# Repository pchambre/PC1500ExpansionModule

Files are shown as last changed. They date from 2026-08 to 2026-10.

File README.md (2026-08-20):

# PC1500 Expansion Module (PSoC 5)

A PSoC 5-based hardware expansion board for the Sharp PC-1500/PC-2 pocket
computer, adding SD-card storage to PC-1500 BASIC via a set of new
`SD`-prefixed keywords (`SDLOAD`, `SDSAVE`, `SDLS`, `SDFMT`, ...).

The board plugs into the PC-1500's expansion port the same way a Sharp
CE-150/153/158 peripheral would, but unlike those (and unlike a real memory
module), the PSoC side has **no bus-request (BRQ) line** — it can't halt the
LH5801 CPU and take over the bus directly. Instead, the two sides
communicate through a shared 2KB RAM window mapped into the PC-1500's
address space: the CPU writes a command byte to a fixed "instruction"
address, the PSoC (polling that address in its own main loop) picks it up,
does the work, and writes its response into the same shared window. See
`PC_EXP.h` for the full wire protocol (command/status codes, buffer
layout).

## Companion emulator

[`pc1500emu`](https://github.com/pchambre/pc1500emu) is a from-scratch
PC-1500/LH5801 emulator with a matching `ExpansionMock` that implements this
same protocol against a real host directory — most of this board's firmware
and expansion-ROM development happens against the emulator (fast, no
hardware round-trip needed) and is only periodically verified against the
real PSoC board.

## Layout

This repo is a PSoC Creator workspace (`PC1500-PSOC5.cywrk`) containing
several `.cydsn` design variants, built up over the course of development.
**`Design01_NonDMA_8K_PV_Swap.cydsn` is the current, active design** — the
others (`Design01.cydsn`, `Design01_NonDMA.cydsn`,
`Design01_NonDMA_8KAddress_Space*.cydsn`, `Design01_NonDMA_8K_Swap2ndPage.cydsn`,
`Design02.cydsn`) are earlier iterations kept for reference, not maintained.

Inside the active design:

- `TopDesign/` — the PSoC 5 schematic (open with PSoC Creator to edit).
- `main.c` / `PC_EXP.h` — the PSoC-side firmware: the command processor
  (`DoCommand()`) that implements the shared-window wire protocol, backed
  by SEGGER emFile for the actual SD card filesystem calls.
- `rom/` — the PC-1500 expansion ROM, hand-written LH5801 assembly
  (`rom.asm`) that installs the new BASIC keywords. Assembled with
  [`sdaslh5801`](https://github.com/pchambre/sdcc-pc1500) via `build.ps1`,
  producing `rom_image.h` (baked into the PSoC firmware image so the module
  presents this ROM to the PC-1500 at boot) and a standalone `rom_8800.bin`
  (loadable directly into `pc1500emu` for fast iteration without a full
  PSoC Creator rebuild). See `rom/tests/` for a couple of small standalone
  test keywords used while reverse-engineering the PC-1500's own keyword
  dispatch mechanism.
- `SDCard/` — the emFile SD-card component wrapper.

Everything under `Generated_Source/`, `CortexM3/`, `codegentemp/`, and
`Export/` in each `.cydsn` folder is regenerated by PSoC Creator on build
and isn't tracked (see `.gitignore`) — open the workspace in PSoC Creator
and build to recreate it.

- `RP2350/` — an in-progress exploration of rearchitecting this board
  around the RP2350 (Pico 2 W) instead of PSoC 5 + ESP32-S3. Not yet the
  active design — see `RP2350/README.md` for the rationale and current
  state.

## Commands (implemented in `rom/rom.asm`)

- **`SDLS`** — browse the SD card's listing (current directory only, not
  recursive). Subdirectories are listed alongside files, with `<DIR>`
  (right-justified) in place of a size.
- **`SDFMT`** — format the SD card (`Y`/`N` confirmation).
- **`SDLOAD`** — load a BASIC program or binary data:
  - `SDLOAD` — browse, `L` selects and loads, `Enter` ignored, `CL`/`BREAK` abort.
  - `SDLOAD "<filename>"` — direct load, no browser.
  - `SDLOAD M` — browse, `L` loads the selected file as binary to its
    header's target address.
  - `SDLOAD M "<filename>"` — direct binary load to the file's header
    address; also `CALL`s an address embedded in the file, if present.
  - `SDLOAD M "<filename>",<address>` — direct binary load, relocated to
    `<address>` (decimal or `&`-prefixed hex); never calls the embedded
    address.
  - A missing file raises a genuine BASIC `ERROR 40`.
- **`SDSAVE`** — save a BASIC program or binary data:
  - `SDSAVE "<filename>"[,-Y]` — saves the current BASIC program.
  - `SDSAVE M "<filename>",<start>,<end>[,<call>][,-Y]` — saves the
    inclusive RAM range `[start,end]` as binary, with an optional embedded
    call address for a later `SDLOAD M` to invoke automatically.
  - Both forms prompt to confirm before overwriting an existing file
    (`-Y` skips the prompt); missing/malformed required arguments raise
    `ERROR 1`.

- **`SDCD "<path>"`** — change the current directory. Every other SD
  command that takes a name (`SDLOAD`, `SDSAVE`, `SDLS`, `SDRM`, `SDCP`,
  `SDMV`, ...) resolves a plain filename relative to wherever this last
  left it. `"."`/`".."` and multi-component relative paths work; a
  nonexistent directory silently aborts (no error code raised for this
  specific case yet).
- **`SDMKDIR "<path>"`** — create a directory.
- **`SDRMDIR "<path>"`** — remove an *empty* directory (matches emFile's
  own `FS_RmDir`, which fails outright on a non-empty one rather than
  deleting its contents).
- **`SDPWD`** — print the current directory (`/` at the SD root, before
  any `SDCD`).
- **`SDRM "<path>"[,-Y]`** — delete a single file (never a directory —
  `SDRMDIR` is the only sanctioned way to remove one). Confirms first
  (`DELETE FILE? Y/N`, explicit `Y` proceeds, anything else including
  `BREAK` aborts) unless `-Y` is given. A missing argument raises
  `ERROR 1`; the file not existing (or being a directory) raises
  `ERROR 40`.
- **`SDCP "<src>","<dest>"`** — copy a file. `SDMV "<src>","<dest>"`
  — move (rename) a file. If `<dest>` resolves to an *existing directory*,
  the file lands inside it under its own basename, matching Unix `cp`/
  `mv`'s own "copy/move INTO a directory" behavior; otherwise `<dest>` is
  the exact target name. An existing destination is confirmed first
  (`FILE EXISTS. OVERWRITE Y/N`) unless `-Y` is given, matching `SDSAVE`/
  `SDRM`'s own convention. A missing argument raises `ERROR 1`; the source
  not existing (or any other copy/move failure) raises `ERROR 40`.
- **`SDDF`** — print free/total SD space (`<free>F / <total>T`).

- **`SDOPEN`/`SDCLOSE`/`SDINPUT#`/`SDPRINT#`/`SDSKIP#`** — up to 16
  variable-oriented SD files open at once, numbered 1-16 (a simplified,
  Apple-BASIC-style analogue of the CE-150's own `PRINT#`/`INPUT#`, which
  operate directly on named variables rather than file handles or byte
  offsets):
  - `SDOPEN "<filename>" AS <n>` — opens (creating if necessary) a file on
    channel `<n>`. Reusing an already-open channel number closes its
    previous file first. Bare `SDOPEN` (no arguments) browses currently
    open channels and their numbers (`Enter`/`CL`/`BREAK` all exit).
  - `SDCLOSE <n>` — closes channel `<n>`. `SDCLOSE ALL` closes every open
    channel.
  - `SDPRINT#<n>,<var>[,<var>...]` — appends one value per listed variable
    to the end of channel `<n>`'s file, always at the end regardless of
    the channel's own read position.
  - `SDINPUT#<n>,<var>[,<var>...]` — reads one value per listed variable
    from channel `<n>`'s own persistent read position, advancing past
    each one read. If the channel runs out, every remaining requested
    variable is set to `0` (numeric) or blank (string) rather than
    raising an error.
  - `SDSKIP#<n>,<count>` — skips forward `<count>` values in channel
    `<n>`'s own read position without reading them. All-or-nothing: if
    the channel runs out partway through, the read position is left
    completely unchanged and a genuine `ERROR 40` is raised. The comma
    between `<n>` and `<count>` is required — BASIC's own line editor
    does not reliably preserve a bare space between two digit runs
    outside a quoted string, confirmed live (`SDSKIP#1 2` silently lands
    in the input buffer as `#12`).
  - Only simple (non-array) numeric and string variables are supported —
    no arrays, no general expressions, matching the real `PRINT#`/
    `INPUT#`'s own variable-list-only grammar. Values are stored as
    self-describing chunks (`rom.asm` resolves each variable's own real
    RAM address via the base ROM's `D461H` "variable address search"
    system subroutine and copies its storage bytes directly — `main.c`/
    the emulator's `ExpansionMock` never see a variable name or value,
    only opaque chunk bytes): a numeric chunk is the variable's own
    8-byte packed-decimal float, copied verbatim; a string chunk is a
    1-byte length plus that many raw ASCII bytes (a simple string
    variable always holds ≤16 characters). Reading back a value chunk
    whose type doesn't match the target variable, or a string chunk
    longer than the target's own real capacity (only possible from a
    corrupted or hand-crafted file — a genuine `SDPRINT#` can never
    overflow what any variable could legitimately hold), raises `ERROR
    42`.
  - A missing/malformed argument to any of these five raises `ERROR 1`;
    referencing a channel number that isn't currently open raises `ERROR
    40` (the wire protocol can't distinguish "not open" from a genuine
    I/O failure, so neither can the ROM — both get the same code every
    other SD-operation-failure case already uses).
  - True random-access/binary-offset access is not implemented yet —
    values are always read/written/skipped sequentially, one whole value
    at a time.

**Full path support**: every SD command's name argument (`SDLOAD`,
`SDSAVE`, `SDCD`, `SDMKDIR`, `SDRMDIR`, `SDRM`, and both `SDCP`/`SDMV`
arguments) accepts a plain filename, a relative path (`"SUB/FILE.BAS"`,
`"../FILE.BAS"`), or an absolute one from the SD root (`"/SUB/FILE.BAS"`,
or bare `"/"` for the root itself) — not just a bare filename in the
current directory. `/` is the one and only path separator — chosen
deliberately because it's an unshifted key on the PC-1500 keyboard, easy
to actually type. `main.c` converts to/from emFile's own native
`\`-separated, volume-prefixed paths at the boundary
(`PrepareFsName`/`ConvertSdPathToFsSeparators`), so nothing above that —
including the ROM side, which only ever sees/displays `/` — needs to know
emFile's own convention exists. A leading `/` with no volume prefix is
passed straight through to emFile, relying on its own path parser to
treat it as "from the SD root" (the same assumption `SDCD`'s own
`FS_ChDir` call already made — confirmed live for `SDCD` specifically,
not independently re-verified for every other command here).

`SDCD`/`SDMKDIR`/`SDRMDIR`/`SDRM`/`SDCP`/`SDMV` all require their
argument(s); missing one raises `ERROR 1`, matching `SDSAVE`'s own
convention.

**Uppercase 8.3 names**: this project's SD card uses SEGGER emFile's
No-Long-File-Name build (`emf32nosnlfn`, confirmed via this project's own
linker settings), so real on-disk names are genuine FAT 8.3 short names —
uppercase, `NAME.EXT` with an up-to-8-character name and an up-to-3-character
extension. Every SD command enforces this on its own argument(s):
lowercase letters are folded to uppercase automatically, and each
`/`-separated path segment that's too long, or has a second `.`, raises
`ERROR 1` (matching the existing unterminated/overlong-argument
convention) — except `SDLOAD`, which (per its own convention above)
silently aborts instead of raising an error for *any* malformed argument,
shape violations included. `.`/`..` segments are always exempt from the
shape check. A quoted argument itself is capped at 40 characters overall
— deliberately more than the 16-character width `SDLS`'s own listing
display column uses, since a path argument isn't shown in that fixed
column and can reasonably be longer.

The actual shape check + uppercase-folding runs on the PSoC/emulator side
(`EXP_COMMAND_VALIDATE_SD_NAME`, moved off `rom.asm` 2026-08-19) — `rom.asm`
itself only copies the raw typed name into the shared window and checks
for unterminated/overlong/empty before handing it off; the wire-level
`ERROR 1` behavior above is unchanged either way, since every call site
still just checks a Carry flag that means the same thing regardless of
which side actually did the validating.

**`+` stands in for `~`**: a card prepared on a normal PC (long filenames)
and then read by this project's NLFN firmware shows its auto-generated FAT
short names, which often contain a literal `~` (e.g. `MYAPPL~1.BAS`) — a
character the PC-1500 keyboard can't type. `+` is used as a typable
stand-in instead: `SDLS`/`SDPWD` show `+` wherever a real name has `~`,
and `SDLOAD`/`SDSAVE`/`SDCD`/`SDMKDIR`/`SDRMDIR` translate `+` back to `~`
before touching the real filesystem — including on create, so
`SDSAVE "APPL+1.BAS"` deliberately creates a file literally named
`APPL~1.BAS`. `+` (not `-`) was chosen specifically because it's illegal in
a real FAT 8.3 name, so the translation is unconditional and unambiguous in
both directions with zero risk of colliding with a genuinely `+`-named
file (impossible) — unlike `-`, which is a legal FAT 8.3 character.

BASIC-mode `SDLOAD`/`SDSAVE` target the program area's real, live start
address (tracked by BASIC itself in RAM at `7865H`/`7866H`, which shifts
depending on installed RAM — e.g. a CE-155 module moves it to `38C5H`),
not a hardcoded address, so they work correctly regardless of the PC-1500's
RAM configuration.

## Building

Requires PSoC Creator (this workspace was last built with PSoC Creator
4.x). Open `PC1500-PSOC5.cywrk`, select `Design01_NonDMA_8K_PV_Swap.cydsn`
as the active design, and Build. The ROM assembly step
(`rom/build.ps1`, needing `sdaslh5801` on `PATH`) must be run first if
`rom.asm` changed, so `rom_image.h` is up to date before the PSoC-side
build picks it up.

## License

Apache License 2.0 — see `LICENSE`.

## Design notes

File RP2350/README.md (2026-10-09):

# RP2350 (Pico 2 W) architecture -- in progress

An exploration of rearchitecting this board around the RP2350 (Pico 2 W,
with its CYW43439 WiFi/BT chip) instead of the current PSoC 5 + ESP32-S3
combination. **This is not yet the active design** -- `Design01_NonDMA_8K_PV_Swap.cydsn`
(see the top-level README) is what actually ships and is developed
against. This directory tracks a real rewrite of the firmware, not a
sketch: the bus-servicing loop and `DoCommand()` SD command dispatcher
are now ported from the PSoC5 side (see "Layout" below), and the GPIO
pin budget for a Pico 2 W module is fully worked out (see "Pin budget"
below) -- but **none of it has been run against real hardware**: there is
no RP2350 board wired to a PC-1500, no GreenPAK, and no schematic for
this board yet. Treat everything here as a carefully-reasoned starting
point for bring-up, not as proven-working firmware.

## Why RP2350

Same fundamental constraint as the PSoC5 design: the LH5801 has no
bus-request (BRQ) line, so the board can never halt the CPU to take over
the bus -- it must react to bus cycles it doesn't control the timing of.
RP2350's PIO blocks are a better fit for the reactive parts of that
problem than PSoC5's software polling loop: independent state machines
that react to GPIO transitions in a handful of deterministic clock
cycles, immune to whatever else the CPU cores are doing. Concretely:

- PIO has no general memory access -- it can capture an address/status
  atomically and drive output pins the instant it's handed a value, but
  it can't do an arbitrary "look up byte at this address" lookup itself
  (confirmed against how the Pico SDK's own `cyw43_bus_pio_spi.c` driver
  uses PIO+DMA: that's a CPU-orchestrated, sequential, fixed-length
  transfer, not a random-access slave response -- a genuinely different
  problem from what this board needs for its live data window).
- The reactive part of the protocol (the 2K "live" MCU<->LH5801 data
  window -- status/params/command byte, matching `EXP_INSTRUCTION_PAGE`/
  `EXP_BUFFER_START_PAGE` in the current PSoC firmware's `PC_EXP.h`)
  needs a real memory lookup per access, so it needs a dedicated CPU
  core running a tight loop against its own on-chip SRAM -- comfortably
  within a ~2us budget at 150MHz (on the order of 10-30 cycles of actual
  work against a ~300-cycle budget), but that core must be fully
  exclusive (no interrupts, no other work) while doing it, since there's
  no BRQ fallback if it's ever late.
- That core is only needed while actively servicing an LH5801 request,
  not perpetually -- most of the time (whenever no command is in
  flight), the MCU can be fully asleep. RP2350's pad isolation latches
  (datasheet SS9.7) freeze every GPIO's output state automatically on
  sleep entry and hold it through the entire sleep period and the early
  part of wake, with zero MCU participation -- so a status byte
  (sleeping/busy/ready) set just before sleeping stays correctly visible
  without needing a separate hardware latch for the *value*. Waking
  itself uses up to 4 dedicated GPIO wake sources (`PWRUP0`-`PWRUP3`),
  monitored by the always-on POWMAN domain even with the core fully
  powered down.
- The 6K ROM region and the 62256's remaining ~26K of general expansion
  RAM are **single-master** -- only the LH5801 ever drives that SRAM's
  address/data pins. The ROM image gets there via the LH5801 itself
  running a memcpy loop (the existing `_PV_Swap` firmware's own
  mechanism: PV toggled between the read, from the MCU's data path, and
  the write, to the SRAM, of each byte), not the MCU writing the SRAM
  directly -- so there's no two-master contention to arbitrate on that
  chip. GreenPAK-equivalent glue logic (still needed, likely still an
  actual small CPLD rather than something RP2350 absorbs) does address
  decode/chip-select for the 26K region and muxes whether the 6K ROM
  window's reads are answered by the SRAM directly (`ROM_FROM_SRAM`,
  hardware-only, MCU asleep) or by the MCU (`ROM_FROM_MCU`, during the
  boot-time copy) -- plus, separately, latching the one thing that
  genuinely still needs a CPLD-side flip-flop: the wake *request* itself
  (a bus write to the instruction address while asleep), since that has
  to survive as a stable level until POWMAN gets around to noticing it,
  not just a bus-cycle-width pulse.

## Pin budget

**Superseded 2026-09-16 by real schematic ground truth -- see
`board_pins.h`'s own top comment, which is now the authoritative
source.** This section is kept for the pin-*count*/budget reasoning
(still valid) and as a record of what this pre-hardware planning got
wrong once a real schematic existed to check it against -- most notably
the SD card story below, which wasn't just off by a pin number but
architecturally wrong for the board that actually got built.

A Pico 2 W module exposes 26 usable GPIOs (GP23/24/25/29 are wired on the
module itself to the onboard CYW43439 wifi chip). This design uses 25 of
those 26, with one spare (GP28, routed to a header on the real board):

| Signal | Pins | Notes |
|---|---|---|
| Address bus A0-A12 | 13 | Flat 8K window (0x8000-0x9FFF) |
| Data bus D0-D7 | 8 | |
| I2C-style link to the GreenPAK(s) | 2 | Comms + the `Control_Mode_Control`-equivalent ROM-source mux select |
| Trigger lines (read-trigger, write-trigger) | 2 | A GreenPAK combines CS+R/W+OE into two edges ("read requested, drive data now" / "write requested, latch data now") instead of RP2350 computing CS&&RW&&OE itself. These double as POWMAN wake sources (`PWRUP0`/`PWRUP1`) -- no separate wake pin. |
| SD card | 0 | **Not wired to any RP2350 GPIO at all -- see below.** |

25 pins total; GP28 is spare. SRAM chip-select and MCU chip-select are
both handled by the GreenPAK(s) directly, not wired to RP2350 GPIOs. See
`board_pins.h` for the exact, schematic-confirmed GPIO assignment.

### SD card: this section was wrong -- no QMI CS1 on the real board

The plan below (QMI CS1 as a 1-GPIO-cost SPI-alike for the SD card) was
worked out before a schematic existed, and `lib/qmi_cs1_sdspi/` was built
against it. `PC1500-Pico2W-Dongle.kicad_sch` shows the real board doesn't
wire the SD socket to RP2350 GPIO/QMI at all: it goes through U5, an
SC18IS602B I2C-to-SPI bridge chip, sharing the GreenPAKs' own I2C bus
(A0/A1/A2 tied to GND -> fixed I2C address 0x28; only SS0 is wired, to
the card's CS). `lib/qmi_cs1_sdspi/` is unused on this board -- calling
its `qmi_cs1_spi_init()` configured GPIO19 for QMI/XIP duty, but GPIO19
is really this board's D6 data-bus line, so it hijacked a live bus line
on every boot and broke the PC-1500's own boot cycle outright.

Real SD support now exists against the actual hardware: `sc18is602b.h`/
`.c` is the bridge primitive (SPI-mode config, a chunked full-duplex
transfer respecting the chip's 200-byte internal buffer), and
`diskio_sd.c` implements FatFs's `disk_*()` interface on top of it,
through `sd_bus.h` (`sd_bus_bridge.c` here; the internal card's
`sd_bus_spi.c` drives SPI1 instead) -- the standard SD-over-SPI command set (CMD0/CMD8/ACMD41 init,
CMD9/CSD-based capacity, CMD17/CMD24 block read/write), targeting modern
SDHC/SDXC cards with a best-effort SDSC fallback. The bridge's own SPI
clock tops out at 1.843 Mbit/s -- slow, but fine for this board's actual
file sizes.

Original (superseded) reasoning, kept for context: a normal SPI
peripheral (4 dedicated GPIOs) would have blown the pin budget by 3.
RP2350's QMI (QSPI Memory Interface) peripheral -- the same one that
does XIP flash fetches -- supports a second chip-select, CS1, sharing
SCLK/SD0-3 with the flash's own CS0 (a real, documented feature,
normally used for XIP PSRAM). Using it for the SD card instead would
have cost 1 GPIO instead of 4 -- see `lib/qmi_cs1_sdspi/`'s own README.md
for the driver itself, which may still be useful for some other RP2350
project whose SD card really is wired that way.

## Layout

- `CMakeLists.txt` / `pico_sdk_import.cmake` -- standard Pico SDK
  project files, `PICO_BOARD=pico2_w`.
- `board_pins.h` -- picks the board's GPIO table: `board_pins_dongle.h`
  (the table above) or `board_pins_card.h` (see "Build targets").
- `pc_exp.h` -- copy of `../Design01_NonDMA_8K_PV_Swap.cydsn/PC_EXP.h`'s
  wire-protocol constants, kept in sync by hand (same pattern this
  project already uses elsewhere, e.g. pc1500emu's `ExpansionMock`).
- `ffconf.h` -- this project's FatFs configuration (copy of the vendored
  library's default with `FF_USE_LABEL`/`FF_FS_NORTC` changed -- see its
  own top comment).
- `monitor.c`/`monitor.h` -- the ported bus-servicing loop and
  `DoCommand()` SD command dispatcher, from
  `../Design01_NonDMA_8K_PV_Swap.cydsn/main.c`. Translated case-by-case
  from SEGGER emFile's `FS_*` API to FatFs's `f_*` API; see `monitor.c`'s
  own top comment for the port's structural reasoning (including why it
  deliberately does *not* need the RAM-residency treatment
  `qmi_cs1_sdspi` does).
- `lib/qmi_cs1_sdspi/` -- the QMI-CS1 SD-over-SPI driver described
  above.
- `lib/no-OS-FatFS-SD-SDIO-SPI-RPi-Pico/` -- git submodule; only its
  protocol-agnostic FatFs core (`ff15/source/ff.c`/`ffsystem.c`/
  `ffunicode.c`) is actually compiled in -- its own SD driver
  (`sd_driver/`) is unused, since the SD card goes through
  `qmi_cs1_sdspi` instead.
- `main.c` -- single-core (`stdio_init_all`, `monitor_init_buffer()`,
  then `monitor_run()`, which never returns) -- see its own comment for
  why: the MCU is either servicing the bus loop or executing a command,
  never both at once, so a second core never bought any real
  concurrency. SD card init is not part of this at all right now -- see
  the SD card section above.

## Build targets: the dongle and the internal card (2026-10-09)

One source tree builds firmware for two boards, chosen by the CMake cache
variable `PC1500_TARGET`, each in its own build directory:

| | `dongle` (default) | `card` |
|---|---|---|
| Board | Pico 2 W dongle (`PICO_BOARD=pico2_w`) | RP2354B internal card, `PC1500-RP2354B-BLE-more-RAM` (`boards/pc1500_card_rp2354b.h`) |
| Configure | `cmake -G Ninja -B build -S .` | `cmake -G Ninja -B build-card -S . -DPC1500_TARGET=card` |
| Firmware | `build/pc1500_expansion_rp2350.uf2` | `build-card/pc1500_card_rp2354b.uf2` |
| Pins | `board_pins_dongle.h` | `board_pins_card.h` |
| SD card | SC18IS602B bridge (`sd_bus_bridge.c`) | SPI1, GPIO40-43 (`sd_bus_spi.c`) |
| Wi-Fi, SSH, WFPING | yes (CYW43, lwIP) | no: the keywords give ERROR 40, WFSTAT is 0 |
| Bluetooth | BTstack on the CYW43: BLE + classic | not yet: the BGM220S's stack is undecided, so `no_radio.c` stands in and no BTstack is linked |
| LED | CYW43 GPIO | none |

`diskio_sd.c`'s SD protocol, the PIO/DMA bus serving, the keyword
executor, STAGE, MLOG, MCONF, command history, sleep and everything else
are shared. The card's differences are compile definitions set in
`CMakeLists.txt` (`PC1500_TARGET_CARD`, `PC1500_NO_WIFI`,
`PC1500_NO_CYW43`, `PC1500_SD_SPI`, `PC1500_NO_BLE`). Each guard is
written `#ifndef PC1500_NO_...`, so the dongle -- and pc1500emu's
ExpansionMock, which compiles `keywords.c` -- defines none of them.

`board_pins_card.h` describes the card **after a data-bus rewire**:
D0-D7 on GPIO16-23, in order. The bus PIO programs need the address bus,
the data bus and both triggers in one PIO block's GPIO0-31 window, and the
schematic as of 2026-10-09 had D3-D7 on GPIO35-39 (`board_pins.h`
checks this at compile time). The card firmware has been built, not yet
run on a card.

## Building

Requires the Pico SDK (2.0.0+, for RP2350 support) and its toolchain --
the [official Raspberry Pi Pico VS Code
extension](https://marketplace.visualstudio.com/items?itemName=raspberry-pi.raspberry-pi-pico)
normally manages this installation automatically, but that installer is
GUI-driven (no CLI equivalent for its specific managed-SDK download), so
this machine's copy was set up manually instead -- an independently
documented, fully standard way to develop for the Pico SDK, not a
workaround:

| Component | Version | Location |
|---|---|---|
| Pico SDK (+ submodules: tinyusb, cyw43-driver, lwip, mbedtls, btstack) | 2.3.0 | `~/.pico-sdk/sdk/2.3.0` |
| Arm GNU Toolchain (arm-none-eabi) | 15.2.rel1 | `~/.pico-sdk/toolchain/15.2.rel1` |
| Ninja | 1.13.2 | `~/.pico-sdk/ninja/1.13.2` |
| `picotool` (prebuilt, from `raspberrypi/pico-sdk-tools`) | 2.3.0 | `~/.pico-sdk/toolchain/picotool-2.3.0` |
| `pioasm` (prebuilt, from `raspberrypi/pico-sdk-tools`) | 2.3.0 | `~/.pico-sdk/toolchain/pico-sdk-tools-2.3.0` |

The SDK/toolchain versions are pinned to specific releases (not
"latest") for reproducibility -- bump deliberately, not by accident.
`picotool`/`pioasm` are prebuilt binaries from `pico-sdk-tools`'
releases rather than built from source: this machine has a stray, very
old GCC earlier in `PATH` (`C:\Flex Windows\gcc\bin`, unrelated to this
project) that CMake's `FetchContent`-driven host-tool sub-builds picked
up instead of a working host compiler, and it's new enough that this
predates C99 support -- using the prebuilt binaries sidesteps needing a
working *host* compiler entirely (separate from the `arm-none-eabi`
*target* cross-compiler above, which is unaffected by this).

`PICO_SDK_PATH` and `PICO_TOOLCHAIN_PATH` are set as persistent User
environment variables pointing at the paths above (standard Pico SDK
convention, read directly by its CMake files); Ninja and the toolchain's
`bin/` are also on the User `PATH`. `.vscode/settings.json` at the repo
root points the Pico extension's own `cmakePath`/`ninjaPath`/
`python3Path` settings at the same install. A new terminal (or VS Code
restart) is needed to pick up environment changes made after it was
opened.

Confirmed working end-to-end: `cmake -G Ninja -B build -S .` then
`cmake --build build` produces `build/pc1500_expansion_rp2350.uf2`,
ready to drag onto the board in BOOTSEL mode -- including the full
monitor loop, `DoCommand()`, and `qmi_cs1_sdspi` module described above
(a clean build was the extent of verification possible in the session
that wrote them; see "Pin budget" above for what still needs real
hardware to confirm).

Unlike the PSoC5 side, this is a plain CMake + C project -- no
proprietary schematic-only files, everything here is directly
readable/editable text.

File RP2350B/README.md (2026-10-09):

# RP2350B (bare core dev board + RN4871 BLE) -- RETIRED

> **Retired 2026-10-09.** The internal card's firmware is now a build
> target of `../RP2350/` (`cmake -B build-card -DPC1500_TARGET=card`; see
> that README's "Build targets"), which carries all the dongle's work since
> this fork (PIO/DMA bus serving, the keyword executor, STAGE, MLOG,
> MCONF, sleep). This directory was copied from the dongle on 2026-08-28 and
> never synced again; it is kept, unbuilt, for reference only. GreenPAK
> provisioning is the separate `../GreenPak_Provision/` project. Nothing
> below is current.

The active RP2350-based redesign, superseding `../RP2350/` (a Pico 2 W
module target, kept for reference/history but no longer developed
against). This directory targets a bare RP2350B chip on a "core dev
board" (WeAct Studio's `weact_studio_rp2350b_core`, a real stock Pico SDK
board definition -- 48-GPIO QFN-80 package, no onboard WiFi/BT module)
plus a Microchip RN4871 BLE module wired over UART, matching the real
KiCad schematic at
`C:\Users\paulc\Documents\PC1500ExpansionBoard\PC1500-RP2350B-BLE`.
**None of this has been run against real hardware yet** -- treat it the
same way `../RP2350/README.md` treats its own port: a carefully-reasoned
starting point for bring-up, not proven-working firmware.

## Why RP2350B instead of the Pico 2 W module

The Pico 2 W module only exposes 26 usable GPIOs (4 of its 30 are wired
on-module to the onboard CYW43439 WiFi/BT chip), which forced `../RP2350/`
into real compromises: a split, non-contiguous data bus field, and the
QMI-CS1 SD-card trick (`../RP2350/lib/qmi_cs1_sdspi/`) to save 3 GPIOs at
the cost of SPI-XIP-flash bus contention during SD transfers. The bare
RP2350B exposes the full 48 GPIOs; this design uses 35 of them with 13
genuinely spare, which removes both compromises: the address bus
(GPIO0-12) and data bus (GPIO13-20) are each a single contiguous field
(`addr = gpio_in & 0x1FFF` with zero shifting), and the SD card gets a
real, uncontended, full 4-pin hardware SPI1 peripheral. BLE is now RN4871
over a real hardware UART instead of the Pico 2 W module's onboard
CYW43439 WiFi/BT combo chip -- a simpler, better-understood transport for
this project's actual need (a BLE link to a phone/host, not WiFi).

See `board_pins.h` for the full pin table and, importantly, its comments
on *why* each pin was checked against the real RP2350 GPIO
function-select table (not just "the schematic says so") -- SPI and UART
pins genuinely need to land on the right hardware peripheral's funcsel,
which isn't the same thing as "the wiring is electrically valid."

## Layout

- `CMakeLists.txt` / `pico_sdk_import.cmake` -- standard Pico SDK project
  files, `PICO_BOARD=weact_studio_rp2350b_core`.
- `board_pins.h` -- the GPIO assignment table, kept in sync by hand with
  the real KiCad schematic (see its own top comment for exactly which
  file is ground truth if they ever disagree).
- `pc_exp.h` -- copy of `../Design01_NonDMA_8K_PV_Swap.cydsn/PC_EXP.h`'s
  wire-protocol constants, unchanged from `../RP2350/pc_exp.h`.
- `ffconf.h` -- this project's FatFs configuration, unchanged from
  `../RP2350/ffconf.h` (`FF_USE_LABEL`/`FF_FS_NORTC` changed from the
  vendored default -- see its own top comment).
- `hw_config.c` -- tells the vendored FatFs SD library which real
  GPIOs/SPI instance the SD card is on (SPI1, GPIO40-43).
- `monitor.c`/`monitor.h` -- the bus-servicing loop and `DoCommand()` SD
  command dispatcher, carried over from `../RP2350/monitor.c` with the
  bus-loop half simplified (single contiguous field for both buses now,
  see the file's own top comment) and `DoCommand()` itself unchanged
  (it's entirely transport-agnostic).
- `ble_rn4871.c`/`.h` -- minimal RN4871 UART-transparent-mode driver
  (init/send/recv/wake-pin control). Doesn't include the RN4871's own
  ASCII command-mode provisioning (putting it into transparent mode in
  the first place) -- that's a one-time setup step via the module's own
  `$$$` escape sequence, out of scope for this driver.
- `greenpak_i2c.c`/`.h` -- bit-banged (software) I2C primitives for the
  two GreenPAK links. Deliberately not using RP2350's hardware I2C
  peripherals -- `board_pins.h`'s GreenPAK SDA/SCL pins don't land on a
  matched pair on the same hardware I2C instance, which is fine since
  this link is low-speed/non-critical (see `board_pins.h`'s own comment).
  The actual GreenPAK command protocol isn't designed yet -- see
  `monitor.c`'s `EXP_COMMAND_ROM_FROM_SRAM`/`ROM_FROM_MCU` cases, carried
  over as placeholders from `../RP2350/monitor.c`.
- `main.c` -- core0: USB stdio, SPI1 SD mount, BLE UART init, both
  GreenPAK I2C buses init, then `multicore_launch_core1(monitor_run)` and
  idle. Core1 runs the whole bus loop/`DoCommand()` exclusively, same
  split as `../RP2350/main.c`.
- `lib/no-OS-FatFS-SD-SDIO-SPI-RPi-Pico/` -- git submodule, same library
  `../RP2350/` uses, pinned to the same commit (`d5e4534`). Unlike
  `../RP2350/`, this project links its own `add_subdirectory`'d
  `no-OS-FatFS-SD-SDIO-SPI-RPi-Pico` INTERFACE target directly (SPI SD
  driver included) instead of hand-picking just the FatFs core files --
  the QMI-CS1-vs-library's-own-SPI-driver symbol collision that forced
  `../RP2350/` to do it the hard way doesn't apply here, since this
  project uses the library's own SPI driver, not a custom one.
- No `lib/qmi_cs1_sdspi/` -- not needed, see "Why RP2350B" above.

## Building

Same toolchain as `../RP2350/` (see that file's own "Building" section
for the full pinned-version table) -- Pico SDK 2.3.0 + Arm GNU Toolchain
15.2.rel1 at `~/.pico-sdk/`, `PICO_SDK_PATH`/`PICO_TOOLCHAIN_PATH` set as
persistent User environment variables. `weact_studio_rp2350b_core` is a
real board definition shipped in Pico SDK 2.3.0's
`src/boards/include/boards/` -- no custom board header needed.

**One gotcha this project hits that `../RP2350/` didn't** (that port
never needed picotool, since it doesn't produce a UF2 via the RP2350
bootloader path the same way -- this one does, via `pico_add_extra_outputs`,
which needs picotool at configure time): a plain `cmake -G Ninja -B build
-S .` fails partway through with unrelated-looking C++ compile errors
(`'to_string' is not a member of 'std'`, `unknown type name '__m128i'`,
etc). That's this machine's stray old `C:\Flex Windows\gcc\bin` earlier in
`PATH` (unrelated to this project) getting picked up by CMake's
`FetchContent`-driven build-picotool-from-source fallback instead of a
working host compiler -- same root cause `../RP2350/README.md` documents
for `pioasm`/`picotool`, but that project's build never actually
triggered this path, so it went undocumented as a required flag until
now. Fix: point `CMAKE_PREFIX_PATH` at the prebuilt binaries so CMake
finds them instead of trying to build from source:

```
cmake -G Ninja -B build -S . -DCMAKE_PREFIX_PATH="C:/Users/paulc/.pico-sdk/toolchain/picotool-2.3.0;C:/Users/paulc/.pico-sdk/toolchain/pico-sdk-tools-2.3.0"
cmake --build build
```

Confirmed working end-to-end 2026-08-25: this produces
`build/pc1500_expansion_rp2350b.uf2` (219KB) from a clean `build/`
directory with zero errors, including the full monitor loop,
`DoCommand()`, `greenpak_i2c`, and `ble_rn4871` modules described above --
ready to drag onto the board in BOOTSEL mode. As with `../RP2350/`, a
clean build is the extent of verification possible without the real
board/GreenPAKs/RN4871/SD card wired up -- see "Pin budget"/board_pins.h
above for what still needs real hardware to confirm.

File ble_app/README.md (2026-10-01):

# pc1500_ble

The laptop (and later phone) side of the PC-1500 expansion board's BLE link. It
advertises the "PC-1500 Link" GATT service, and a PC-1500 scans for it and
connects.

What it does for a connected PC-1500 (`RP2350/BLE_PROTOCOL.md`):
- `BLPRINT`/`BLLIST` text appears in the console; `BLCLS` clears it.
- `BLSAVE`/`BLLOAD` files live in `Documents\PC1500-BLE`.
- The plotter (2026-09-30): what the PC-1500's CE-150 commands (`LPRINT`,
  `LLIST`, `LINE`, `RLINE`, `TEST`, ...) draw, on a 58 mm paper roll at its real
  proportions, in the CE-150's four pens (`lib/plot.dart`). The expansion board
  sends the pen's movements (PLOT frames), so the app only draws lines.

The log is also written to `%TEMP%\pc1500_ble.log`. Tests: `flutter test`.

- Link service `c31f0001-92a3-40ab-b63d-7cdb0a37aed0`
  - RX `c31f0002-…`: written by the connecting side (write without response)
  - TX `c31f0003-…`: notify
- Windows advertises under the computer's name, not the requested local name.
  Peers find servers by the service UUID.
- `third_party/ble_peripheral` is a patched copy of `ble_peripheral` 2.4.0,
  because the published Windows code crashes on writes. See its `PATCHES.md`.

Build: `flutter build windows` (needs Developer Mode, and Visual Studio's
C++ desktop workload in a complete install).

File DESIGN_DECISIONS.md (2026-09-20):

# Design decisions

Rationale behind non-obvious hardware/firmware choices across this repo,
kept at repo root because it's referenced from multiple sub-projects
(`GreenPak_Provision/main_provision.c`, `RP2350B/main_provision.c`, and
others). Both dongle and internal-card boards have **running fabricated
prototype hardware** as of this writing -- entries here are confirmed,
working design intent from that hardware, captured during revision work
for the next fabrication round, not theoretical/undecided.

This file replaces an earlier version of itself that existed at some
point (referenced by the "repo-level plan doc" comments in both copies
of `main_provision.c`) but was never committed to git and has been lost.
Committing this one for real this time so that doesn't happen again.

## Why 4.7V is the PC-1500's native logic rail (Vcc/Vgg)

Sharp's own choice for this CMOS-based pocket computer, not something
either expansion board invented:

- **Easier to regulate down from a 4x1.5V (6V) alkaline/NiCd battery
  pack** than 5V -- less regulator dropout margin needed.
- **Lower power than 5V**, which matters for battery life on CMOS logic
  (power scales with V²).
- **Still close enough to 5V for TTL-style interfacing** -- the PC-1500
  Technical Reference Manual specifies the bus's minimum logic-high
  (`V_IH`) as a fixed **2.4V**, not a percentage of the bus's own supply
  (CMOS-style), so 4.7V clears standard TTL thresholds comfortably. This
  fixed-threshold fact is also what makes direct (un-level-shifted) GPIO
  connection to a 3.3V MCU work -- see
  `PC1500-RP2350B-BLE/no_level_shifters_investigation.md` for the full
  GPIO-tolerance/timing analysis that rests on it.

**Vcc vs Vgg, on the PC-1500 itself:** both are nominally ~4.7V, but
functionally different rails -- `Vcc` is the switched "On" power (dies
when the calculator powers off), `Vgg` is the **always-on** 4.7V rail
that keeps things like static RAM powered through power-off.

**On the expansion boards:** each board has its own onboard regulator
(`U7`, AP1117-ADJ, feedback-set via `R1`/`R2`) deliberately configured to
output **4.7V**, named `VGG` on these boards -- chosen specifically to
match the PC-1500's own native voltage domain, not an arbitrary pick.
This is *not* the same node as the PC-1500's own `+4V7` connector pins
(the PC-1500's own internal Vgg) -- see `CONNECTOR_PINOUT.md`'s note on
this; don't tie them together without checking whether the PC-1500 side
can source/sink current from an external board driving its own +4V7
pins.

## GreenPAK dual-chip provisioning (both boards: GP1/GP2)

Each board carries two Renesas SLG46826G GreenPAKs (GP1, GP2). Brand-new,
unprogrammed GreenPAKs all ship at the **same factory-default I2C slave
address (0x08)**, so both chips can't coexist live on one bus until at
least one has been reassigned a unique address. `GreenPak_Provision`
(standalone Pico 2 W firmware, separate image from normal board
operation) handles this:

- **Target addresses once provisioned:** GP1 -> `0x18`, GP2 -> `0x10`.
- On the **dongle board**, GP2's isolation from the shared bus is a
  physical jumper (SDA1/SCL1 -- see the dongle-specific section below)
  that must be disconnected for GP1-alone provisioning and reconnected
  for GP2's. On the **internal card**, the equivalent isolation is
  whatever this board's own schematic implements (check that board's
  schematic before assuming the dongle's jumper mechanism applies
  identically).
- **Every provisioning run checks target addresses first, not just the
  factory default** -- this is what makes a re-run idempotent/safe: any
  chip already answering at its own target address gets read back and
  compared against the expected image, and is only actually
  reprogrammed if the content doesn't already match (NVM write endurance
  is finite; don't re-erase/re-write a chip that's already correct just
  because the tool ran again, e.g. during repeated power-cycling in
  bring-up).
- Fallback logic handles all four real states (both provisioned already;
  neither provisioned yet; GP1 done/GP2 pending; GP2 done/GP1 pending)
  plus a recovery mode (full 7-bit address scan) if nothing answers at
  any known address. Recovery mode never writes unless built with
  `-DGREENPAK_NVM_ALLOW_RECOVERY_WRITE=1` -- a deliberately different
  build, not a runtime prompt.
- All real NVM writes are gated by `GREENPAK_NVM_DRY_RUN` (default 1).
- Full state-machine detail lives in `GreenPak_Provision/main_provision.c`'s
  own header comment -- this section is the "why," that file is the
  "exactly how."

### Dongle-specific: SDA1/SCL1 jumpers exist for this reason

On `PC1500-Pico2W-Dongle`, `U3`=GP1, `U4`=GP2, bridged via `U8`
(TCA9406 level shifter) to the MCU. `SDA1`/`SCL1` (formerly `JP1`/`JP2`)
jumper `SDA_GP`/`SCL_GP` (GP1's segment, always live) across to
`SDA_GP_U4`/`SCL_GP_U4` (GP2's segment, isolated when open):

1. **Jumpers open** -- GP2 electrically isolated. MCU programs GP1 alone
   at the factory default, reassigns it `0x18`.
2. **Jumpers closed** -- GP2 joins the bus. No collision (GP1's moved
   off default). MCU programs GP2, reassigns it `0x10`.
3. Jumpers **stay closed permanently** after this one-time step for
   normal operation. Always the same on-board MCU on both sides of this
   sequence -- never an external programmer.

**Pull-up placement consequence:** `R11`/`R12` (2K, added for I2C
fast-mode -- see below) sit on `VGG` -> `SDA_GP`/`SCL_GP` only. This
covers GP1 unconditionally and GP2 once the jumpers bridge the segments
together; GP2's isolated segment doesn't need its own pull-up since
nothing communicates with it while isolated.

## I2C pull-up values (dongle, added 2026-09-20 revision)

Goal: run I2C fast mode for reasonable throughput over the level-shifted
bridge to the GreenPAKs.

- **2K** on `VGG` (4.7V) -> `SDA_GP`/`SCL_GP` (`R11`/`R12`) -- the
  GreenPAK/level-shifter-B-side segment.
- **1.5K** on `3V3` -> `SDA`/`SCL` (`R13`/`R14`, at `U5`
  SC18IS602B pins 7/8) -- the MCU-side segment (`U1`, `U5`, `U8`'s
  A-side).

The internal card (RP2350B-BLE) may stay on slower I2C, and might split
out separate per-GreenPAK I2C connections instead of sharing one bridged
bus -- under consideration, not yet decided/implemented as of this
writing; revisit before assuming the dongle's jumper-bridge approach
applies there too.

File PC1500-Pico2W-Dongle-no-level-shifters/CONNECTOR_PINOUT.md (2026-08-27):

# Hirose HIF6A-60PA-1.27DS-71 pinout (Sharp PC-1500/1600 60-pin connector)

Extracted directly from the `Sharp_PC_Connector:HIF6A-60PA-1.27DS` footprint's
pad net names in Kai Bader's `Sharp-PC-Breakout-Boards` repo
(`breakout-board.kicad_pcb`), not re-derived — see
`C:\Users\paulc\Downloads\Sharp-PC-Breakout-Boards-main\Sharp-PC-Breakout-Boards-main\breakout-board.kicad_pcb`.

| Pin | Signal | Pin | Signal | Pin | Signal |
|-----|---|-----|---|-----|---|
| 1 | AD7 | 21 | D3 | 41 | +4V7 |
| 2 | AD6 | 22 | D2 | 42 | +4V7 |
| 3 | AD5 | 23 | D1 | 43 | FGND |
| 4 | AD4 | 24 | D0 | 44 | FGND |
| 5 | AD3 | 25 | ~INHIBIT | 45 | +BATT |
| 6 | AD2 | 26 | ~WEX | 46 | +BATT |
| 7 | AD1 | 27 | ~CMTIN | 47 | +BATT |
| 8 | AD0 | 28 | W1 | 48 | +BATT |
| 9 | PB0 | 29 | CMTOUT | 49 | NC4 |
| 10 | PC7 | 30 | INT | 50 | BFO |
| 11 | +4V7 | 31 | AD8 | 51 | \u03a6OS |
| 12 | +4V7 | 32 | AD9 | 52 | GND |
| 13 | NC1 | 33 | AD10 | 53 | GND |
| 14 | NC2 | 34 | AD11 | 54 | GND |
| 15 | PV | 35 | AD12 | 55 | GND |
| 16 | PU | 36 | AD13 | 56 | DME0 |
| 17 | D7 | 37 | AD14 | 57 | RW |
| 18 | D6 | 38 | AD15 | 58 | DME1 |
| 19 | D5 | 39 | PB1 | 59 | ME1 |
| 20 | D4 | 40 | NC3 | 60 | OD |

Notes:
- `+BATT` (pins 45-48, 4 pins ganged) is the raw, unregulated battery
  supply this board's own 4.7V/600mA regulator feeds from.
- `+4V7` (pins 11/12/41/42) is the PC-1500's own internally-regulated
  4.7V rail (Vgg on the internal RP2350B board's own connector) --
  **not** the same node as this dongle's own locally-regulated `Vgg`,
  though both happen to be ~4.7V. Don't tie them together without
  checking whether the real PC-1500 side can source/sink current from an
  external board driving its own +4V7 pins.
- `FGND` (pins 43/44) vs `GND` (pins 52-55) are kept as separate nets on
  the original board -- confirmed distinct in the source footprint, not
  a naming accident. Don't merge them without understanding why the
  original design kept them apart.
- `~INHIBIT`, `~WEX`, `~CMTIN` -- tilde prefix denotes active-low in the
  source project's own convention.
- Only 13 of the 16 AD lines (AD0-AD12) are needed for this board's own
  8K address-decode window per the approved plan; AD13-AD15 still route
  through the GreenPAKs for SRAM addressing as on the internal board.

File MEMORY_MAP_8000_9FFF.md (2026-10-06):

# Memory Map: 0x8000-0x9FFF

The expansion module's RP2350 decodes and serves **0x8000-0x9FFF (8K)** on the LH5801 bus.
Nothing above 0x9FFF belongs to this module.

Sources of truth: `Design01_NonDMA_8K_PV_Swap.cydsn/rom/rom_defs.inc` and `rom/rom.asm` (ROM
side), `PC_EXP.h` / `RP2350/pc_exp.h` (C side). They are kept in sync by hand. Routine addresses
below come from the assembled listing (`rom/rom.rst`) and move whenever `rom.asm` changes, so
re-check that file after every ROM build.

## Top-level split

| Range | Size | Backing | Purpose |
|---|---|---|---|
| 0x8000-0x87FF | 2K (pages 0-7) | `buffer[0..7]` in RP2350 RAM | Data window: command/status exchange, payloads, ROM-side scratch, and the code that must keep running while the ROM region is remapped |
| 0x8800-0x9FFF | 6K (pages 8-31) | `buffer[8..31]` in RP2350 RAM, or the external SRAM when Remap is on | "ROM" region: sentinel, boot hook, keyword index and table, keyword executor |

- **The ROM region isn't real ROM.** It's the same RAM buffer (`buffer[32][256]` in
  `RP2350/monitor.c`), loaded at boot from the assembled `rom.asm` image.
- **Writes to the ROM region never reach `buffer[]`.** GreenPAK2's LUT only raises the write
  trigger for 0x8000-0x87FF, so the RP2350 never sees a write to 0x8800-0x9FFF. `write_serve.pio`
  also drops any write with address bit A11 set, as a second, partial layer behind that.
- **Remap on (STAGE RAM mode):** GreenPAK1/2's SRAM/ROM Remap is set, so reads of 0x8800-0x9FFF are
  answered by the external SRAM chip, which holds a verified copy of the same image. The RP2350
  isn't involved in those reads at all.

## How keywords run (keyword executor)

Since 2026-09-25 the ROM holds almost no per-keyword code. Every keyword table entry except
`ECVER`, `FNCLR` and the two functions (below) points at `KW_START`, and all argument parsing and command sequencing runs on the MCU
(`RP2350/keywords.c`, which pc1500emu's ExpansionMock compiles too). `ECVER` and `FNCLR` are
ROM-only routines that never wake the MCU. Keywords work both typed at the prompt and inside a running program,
and their file names and numbers can be BASIC expressions.

1. BASIC enters `KW_START` with Y pointing just past the keyword's own E1xx token: in
   `DISP_BUFFER` (0x7BB2) for a typed command, in the program line for a running one.
   `KW_START` wakes the MCU (`EC_WAKE`), saves Y (`KW_TEXT_*`), and copies the token and the
   next 78 bytes to 0x8000.
2. It sends `KEYWORD` (0x2E). The MCU parses the statement and runs whatever SD/log/STAGE
   commands it needs internally (their statuses never reach 0x87FF). It answers `SUCCESS`, with
   the statement's length at 0x87E7 and an action block at 0x87E0. Any other status is ERROR 1.
3. The ROM carries out the action. Actions that need the MCU again finish with
   `KEYWORD_CONTINUE` (0x2F), which returns the next action block.
4. Every exit (`KEYWORD_RETURN`) sets Y to the end of the statement, sends `DONE`, and ends
   with `VEJ E2`, BASIC's own end-of-statement vector. In a program that carries on with the
   next statement; at the prompt it finishes the command.

The statement is BASIC's stored form, which affects parsing:
- every space outside quotes is removed (`SDOPEN "X" AS 1` is stored as `"X"AS1`);
- BASIC's own keywords are tokenized inside it (`SLEEPWAIT` becomes `SLEEP` + F1B3, `WAIT`), and
  the MCU expands them back before parsing;
- `:` or CR ends it.

Arguments are handled like this:
- **Plain literals** are read by the MCU directly: a quoted string, or a decimal or `&hex`
  number followed by `,`, the end, or `AS`.
- **Anything else** goes to BASIC's evaluator through the EVAL action.
- **`AS` after an expression doesn't work:** BASIC's evaluator raises ERROR 1 at a word it
  doesn't know. So `SDOPEN` also takes `name,n`, e.g. `SDOPEN F$,1`.
- **The `M` mode flag** of `SDLOAD`/`SDSAVE` needs a quote, comma or end after it: `SDLOAD M,F$`
  (`SDLOAD MF$` is the variable `MF$`).

| Code | Action | ROM does |
|---|---|---|
| 0 | DONE | `KEYWORD_RETURN` (sends `DONE`, `VEJ E2`) |
| 1 | SHOW | Show the 26 characters at 0x8000, wait for a key, ANSWER = key (0 for BREAK), continue |
| 2 | ERROR | `DONE`, then BASIC `ERROR ARG` |
| 3 | BROWSE | Browse the listing at 0x8000 (`LIST_SD_DIR` format). ARG 0: view; otherwise ARG is the pick key (`L` for SDLOAD, `C` for BLSCAN and WFSCAN), which puts the entry's index in ANSWER and continues |
| 4 | LOAD | File already open: read it into RAM at A until 0 bytes, close. ARG bit 0: BASIC program (target = program start, then program end = last byte); bit 1: `CALL` B |
| 5 | SAVE | File already created: write RAM A..B inclusive, close. ARG bit 0: the BASIC program |
| 6 | VAR_LOOKUP | Look up variable A (D461H name code); copy its type byte and raw storage to 0x8000; continue |
| 7 | VAR_STORE | Copy the storage-sized bytes at 0x8000 into that variable; continue |
| 8 | STAGE | Run the STAGE copy routine, ARG = `STAGE_DEBUG_FLAG` |
| 9 | EVAL | Evaluate the BASIC expression A bytes into the statement (`VEJ DE`): the arithmetic register (7A00-7A07) to 0x8000, a string's characters at 0x8008, B = where it ended; continue. A bad expression is raised by BASIC itself |
| 10 | COPY_IN | Copy B bytes of RAM from A to 0x8000; continue |
| 11 | COPY_OUT | Copy B bytes from 0x8000 to RAM at A; continue |
| 12 | RESTORE | STLOAD's last step. Interrupts off, no stack use: copy B bytes from 0x8000 to A; if ARG is set, send `KEYWORD_CONTINUE` (polled inline) and repeat. Then S = `KW_S`, and `KEYWORD_RETURN` with STSAVE's own statement position |
| 13 | POLL | Sleep one timer wake (`am0`/`sie`/`hlt`), then test BREAK with the base ROM's own `VMJ A6` (IF register F00BH bit 1); ANSWER = 1 for BREAK, else 0; continue. ARG bit 0: clear an old BREAK first; bit 1: first show the 26 characters at 0x8000. How BLADV/BLPUT/BLGET/BLRECV/BLSEND wait, and show `SENDING...` etc. |

### Functions (`BLSTAT`, `BLKEY$`, `WFSTAT`, `SDEOF(n)`)

Four keywords are BASIC **functions**, used in expressions like `MEM` (2026-09-29/30, 10-06):
`S=BLSTAT`, `K$=BLKEY$`, `IF WFSTAT=2 THEN ...`, `IF SDEOF(1) THEN ...`, or typed alone at the prompt.
- **What makes them functions** is their code's low byte, which BASIC's evaluator checks:
  `5xH` = no argument (`BLSTAT` E152, `BLKEY$` E153, `WFSTAT` E154), `6xH`-`7xH` = one argument (`SDEOF`, E170).
  Everything else is a statement. See `PC1500_BASIC_Keyword_Extension_Mechanism.md` §13.
- **How they run:** their table entries point at `BLSTAT_FN`/`WFSTAT_FN`/`SDEOF_FN`, which put the command in A
  and fall into `FN_CALL`. `FN_CALL` wakes the MCU and copies the arithmetic register
  (7A00H-7A07H) to 0x8000 (for `SDEOF`, the argument BASIC has already evaluated). It then sends
  the function's command (`FN_BLSTAT` 0x55 / `FN_SDEOF` 0x56 / `FN_WFSTAT` 0x66), copies the 8-byte result from
  0x8000 back to 7A00H, and returns with UH = 0.
  - On an error, UH = the error number from byte 9 of the reply.
- **No `VEJ E2`, and no `KW_START`:** a function can be evaluated in the middle of another
  keyword. It sends `DONE` only if the reply's byte 8 says no keyword is running, and only after
  reading the reply.
- **`BLKEY$` runs in the ROM alone** (`BLKEY_FN`), with no MCU round trip, so a tight polling loop
  costs nothing. It's `INKEY$` (F15C, ROM1 D9AAH) for either keyboard: the PC-1500's own key down
  (`KEYSCAN_NOWAIT`, E42CH), else the external keyboard's (0x87EF through the FE00H code table,
  as `KBD_SCAN` reads it), else none; then `INKEY$`'s own tail (D9B6H) makes the string. The
  external key counts only while the driver is armed (79D4H = 55H, the vector = `KBD_HOOK`):
  without it the MCU may be asleep, and reading the window would wake it on every poll. So with
  `MCONF BLKBD=1` and no keyboard connected, or on the older ROM, it is plain `INKEY$`.

## MCU sleep in STAGE RAM mode

Once the ROM is staged into SRAM, the RP2350 goes DORMANT between keywords.

- **While it sleeps:**
  - Nothing drives the data bus, so the **whole 0x8000-0x87FF window reads 0x00** (the RP2350's
    data-pin pull-downs).
  - Writes to the window are lost.
  - The access that wakes it is itself lost.
- **What wakes it:** a write to the window -- not a read (2026-10-06). Every user of the MCU starts
  with a write (`EC_WAKE`), and a sleeping MCU can't answer a read anyway; waking on reads only
  caused stray wakes, since BASIC itself reads 8000H on ordinary lines (its module probe, ROM1
  FA74H-FA88H). `BLKEY$`'s reads of 0x87EF need no wake: with `MCONF BLKBD=1` the MCU doesn't sleep.
- **Every keyword wakes it first.** `KW_START` runs `EC_WAKE`: it writes `CLEAR_STATUS` to
  0x87FF twice and polls for `READY` (0x04). The keyword then ends with `EC_DONE`
  (`EXP_COMMAND_DONE`), which lets the MCU sleep again.
- **A wake that isn't followed by a command** within 100 ms (e.g. a `POKE` into the window) goes
  back to sleep on its own. A `PEEK` doesn't wake it, and reads 0x00.
- **Code reached by raw `CALL` bypasses `EC_WAKE`:** `ROM_RESET_REMAP`, `MEMCOPY` and
  `MEMCOPY_PV_SWAP` all run from or use the window. In STAGE RAM mode, any of them started while
  the MCU sleeps will fetch or read 0x00.
- **In MCU mode** (Remap off) the RP2350 never sleeps.

## 0x8000-0x87FF — data window

### Fixed protocol cells

| Address | Symbol | Contents |
|---|---|---|
| 0x8000-0x83FF | `EXP_BUFFER_START_ABS` | Payload window, 1024 bytes (`EXP_MAX_TRANSFER_LEN`), pages 0-3. Command arguments and results, the keyword line, SD file data, STAGE's `GET_BLOCK` blocks. Listings start here too but can run on to 0x87D7 (`EXP_DIR_MAX_ENTRIES` = 66). |
| 0x8100-0x81FF | `EXP_SCRATCH_ABS` | Page 1 of the payload window (not extra space). Short length-prefixed responses such as `GET_SD_CWD` / `GET_SD_FILE_NAME`. |
| 0x87E0-0x87E7 | `EXP_KW_ACTION_ABS` | Keyword action block: +0 action, +1 ARG, +2/+3 A (BE), +4/+5 B (BE), +6 ANSWER (written by the ROM before `KEYWORD_CONTINUE`), +7 the statement's length (from the MCU) |
| 0x87EF | `KBD_KEY_ABS` (`EXP_KBD_KEY`) | The external keyboard's key: the matrix index (80H-BFH) of the key it's holding down, 0 = none. Written by the MCU (`kbd_seq.c`), read by the driver's `KBD_ANY`/`KBD_SCAN`. |
| 0x87F0-0x87F4 | `EXP_STORE_PARAMS` | Parameters of the MCU's own flash-store commands (MCU-internal): slot, offset (BE), length (BE) |
| 0x87F5 | `KBD_BREAK_ABS` (`EXP_KBD_BREAK`) | The external keyboard's ON presses, counted by the MCU |
| 0x87FA | `KBD_ACK_ABS` (`EXP_KBD_ACK`) | The ON count the driver has acted on (written by the ROM's `KBD_BREAK`): a BREAK is due while it differs from 0x87F5 |
| 0x87FB-0x87FC | `EXP_BLOCK_CHECKSUM_ABS` | 2-byte BE additive checksum of the block `ROM_COPY_GET_BLOCK` just staged. |
| 0x87FD-0x87FE | `EXP_LENGTH_PORT_ABS` | 2-byte BE transfer length: request in, actual count out (`READ_FROM_SD_FILE`, `WRITE_TO_SD_FILE`, `ROM_COPY_GET_BLOCK`). |
| 0x87FF | `EXP_INSTRUCTION_ABS` | Command/status byte. The LH5801 writes a command code here; the status appears here. A command write is captured by its own PIO/DMA dispatch path, which stamps `BUSY` in hardware before the LH5801's next access, so the raw command byte is never stored here. |

### ROM-side scratch cells

Ordinary RAM cells that `rom.asm` itself uses as working storage, all inside the window.

| Address | Symbol(s) | User |
|---|---|---|
| 0x8000-0x8005 | `MEMCOPY_PARAMS_ABS` | `MEMCOPY` / `MEMCOPY_PV_SWAP` parameter block (source, dest, count; 16-bit BE each) |
| 0x87E8-0x87E9 | `KW_TEXT_HI/LO_ABS` | The statement's argument address (Y at `KW_START`) |
| 0x87EA | `SD_VAR_TYPE_ABS` | VAR_LOOKUP/VAR_STORE: the variable's type/size byte |
| 0x87EB-0x87EC | `SD_VAR_ADDR_HI/LO_ABS` | VAR_LOOKUP/VAR_STORE: the variable's address |
| 0x87ED-0x87EE | `KW_S_HI/LO_ABS` | The stack pointer at `KW_START` (STSAVE saves it, STLOAD's RESTORE returns through it) |
| 0x87F6-0x87F9 | `SD_LIST_INDEX/COUNT/ADDR_HI/ADDR_LO_ABS` | BROWSE cursor (SDLS, SDLOAD picker, SDOPEN, MLOG VIEW) |

LOAD and SAVE use the action block's A cells as their running RAM pointer.

### Resident code in the window

| Range | Contents |
|---|---|
| 0x8400-0x8716 | STAGE's ROM-to-SRAM copy routine (`STAGE_COPY_ROUTINE_ABS`) and its data. It has to run from the window, because once `ROM_COPY_BEGIN` switches Remap, the ROM region is answered by the half-written SRAM. It must never call anything in 0x8800+ until the copy is finished and verified. |
| 0x8717-0x8723 | `ROM_RESET_REMAP` (`CALL 34583`): sends `ROM_FROM_MCU` (Remap and write-enable off) and returns. It uses nothing in 0x8800+, so it's safe in any Remap state. |
| 0x8724-0x87DF | Free |

The longest listings run over 0x8400-0x87D7. The MCU copies the resident code back from the ROM
image at the start of every keyword (`RestoreWindowCode()` in `monitor.c`), so STAGE and
`ROM_RESET_REMAP` always find it intact.

STAGE copy routine layout, 0x8400-0x8716:

| Address | Label | Contents |
|---|---|---|
| 0x8400 | `STAGE_COPY_START` | BEGIN, per-block GET_BLOCK / copy / verify, FINISH, success exit |
| 0x859A | `STAGE_COPY_BEGIN_FAILED` | BEGIN failed: revert quietly (boot hook) or ERROR 1 (from BASIC) |
| 0x85A7 | `STAGE_COPY_VERIFY_MISMATCH` | Per-byte / per-block mismatch report |
| 0x85F0 | `STAGE_BUILD_MISMATCH_MSG` | Builds the `STAGE @aaaa E:ee F:ff` mismatch message |
| 0x8611 | `HEX_BYTE_TO_ASCII`, `HEX_NIBBLE_TO_ASCII` (0x8630) | Hex formatting helpers |
| 0x863A | `STAGE_COPY_MIDFAIL`, `STAGE_COPY_BADCHECKSUM` (0x8642), `STAGE_COPY_REVERT` (0x8648) | Failure exits: RAM mode reverts to MCU-served ROM; the boot hook does too, without display |
| 0x868C | `STAGE_DEBUG_FAIL_RETURN` | DEBUG-mode failure exit: leaves Remap on and returns to BASIC without touching 0x8800+ |
| 0x86AB-0x86B5 | `STAGE_CHECKSUM_HI/LO`, `STAGE_BLOCK_INDEX`, `STAGE_BLOCK_START_HI/LO`, `STAGE_BLOCK_CKSUM_HI/LO`, `STAGE_DEBUG_FLAG`, `STAGE_BOOT_FLAG`, `STAGE_DEBUG_SRC`, `STAGE_DEBUG_FOUND` | Copy state and flags |
| 0x86B6-0x8716 | `STAGE_OK_MSG`, `STAGE_MIDFAIL_MSG`, `STAGE_CHECKSUM_MSG`, `STAGE_BYTE_MISMATCH_TEMPLATE`, `STAGE_HEX_SCRATCH`, `STAGE_REVERT_FAIL_MSG` | Messages and scratch |

## 0x8800-0x9FFF — ROM region

| Range | Contents |
|---|---|
| 0x8800 | `0x55` sentinel. The base ROM's boot scan and keyword lookup only see this page if it's present. |
| 0x8801-0x8809 | Reserved (header padding) |
| 0x880A-0x881F | `BOOT_SELFCHECK_ENTRY`: the base ROM calls page+0x0A during its boot-time module scan (`STX P`, return address pushed). It holds `jmp STAGE_BOOT_ENTRY`; then, at 0x880E, `KBD_HOOK` (`jmp KBD_ENTRY`, the keyboard driver's fixed address for the base ROM's hook vector at 785BH/785CH -- even, so PV low), and at 0x8811 the four BE addresses the MCU patches into the driver's wait loop (`KBD_LOOP`, `KBD_ANY`, `KBD_SCAN`, `KBD_DISPATCH`); then padding. The header must stay exactly 32 bytes. |
| 0x8820-0x8853 | First-letter index, 26 × 2-byte BE pointers (A-Z). Non-zero slots: B → `BLSCAN`, C → `COLOR`, E → `ECVER`, F → `FNCLR`, G → `GRAPH`, L → `LCURSOR`, M → `MLOGMSG`, R → `RLINE`, S → `SDDF`, T → `TAB`, W → `WFSCAN`. |
| 0x8854-0x8B09 | Keyword table (below), terminator `0xD0` at 0x8B09 |
| 0x8B0A | `KEYWORD_RETURN`: shared exit for every keyword the MCU ran. Y to the end of the statement, `EC_DONE`, `VEJ E2`. |
| 0x8B1F | `ECVER_ROUTINE` and its message |
| 0x8B46 | `FNCLR_ROUTINE`; `SD_LIST_BLANK` (26 spaces) at 0x8B58 |
| 0x8B72 | `CE150_E6_ENTRY` (2026-10-01): the CE-150 stand-in's seven E1C0-E1C6 keywords. With a CE-150 attached (C0H at A000H, 55H at B000H) it runs the CE-150's own routine for E680 + the low nibble, found in its table at B054H; otherwise it falls into `KW_START` |
| 0x8BA9-0x9105 | Keyword executor (`KW_START`), action handlers, the functions' `FN_CALL`, browse/load/save loops, EC helpers, variable lookup, `MEMCOPY`, STAGE boot entry |
| 0x9106-0x92B0 | The external keyboard's driver (MCONF `BLKBD`, below) |
| 0x92B1-0x9FFF | Free (the image must not pass 0x9FFF; `.org ROM_REGION_END` guards it) |

### Keyword table and keyword addresses

Entry format: `marker | name | code (2 bytes BE) | address (2 bytes BE)`.
- **Marker:** low nibble = name length. Any entry that isn't the first of its letter needs bit 4
  (0x10) clear, because the base ROM's skip-scan rejects a landing marker with that bit set.
  Conversely, each letter's first entry has bit 4 SET (0xD_), as the CE-150's table does: that
  ends a skip-scan coming from the letter before. Without it the scan runs on into the next
  letter's entries, comparing only from their second character (2026-09-30: after the new L chain
  was added, `A=&FF` became ERROR 1 -- the second F matched `LF`).
- **Code:** the high byte 0xE1 is this page's PV-low code. The exceptions are eight of the CE-150
  stand-in's keywords (2026-09-30), which keep the CE-150's own F0xx codes: BASIC looks for F0xx
  codes on every page, but for E6xx (the CE-150's other seven) only on the CE-150's own page, so
  those seven are E1C0-E1C6 here.
- **Address:** every statement but `ECVER`, `FNCLR` and the E1C0-E1C6 seven points at `KW_START`
  (0x8BA9); the MCU tells the keywords apart by the token code the ROM hands it. `ECVER` points at
  `ECVER_ROUTINE` (0x8B1F), `FNCLR` at `FNCLR_ROUTINE` (0x8B46), and `CSIZE`, `GRAPH`, `GLCURSOR`,
  `LCURSOR`, `SORGN`, `ROTATE` and `TEXT` at `CE150_E6_ENTRY` (0x8B72), which hands them to a real
  CE-150 when one is attached. The functions point at `BLSTAT_FN` (0x8E05), `WFSTAT_FN` (0x8E09),
  `BLKEY_FN` (0x8E0D) and `SDEOF_FN` (0x8E39).

| Keyword | Table entry | Code |
|---|---|---|
| `SDDF` | 0x8854 | 0xE18A |
| `SDFMT` | 0x885D | 0xE189 |
| `SDLOAD` | 0x8867 | 0xE187 |
| `SDLS` | 0x8872 | 0xE185 |
| `SDRMDIR` | 0x887B | 0xE18E |
| `SDRM` | 0x8887 | 0xE188 |
| `SDSAVE` | 0x8890 | 0xE186 |
| `SDCP` | 0x889B | 0xE18B |
| `SDCD` | 0x88A4 | 0xE18C |
| `SDMKDIR` | 0x88AD | 0xE18D |
| `SDPWD` | 0x88B9 | 0xE18F |
| `SDMV` | 0x88C3 | 0xE180 |
| `SDOPEN` | 0x88CC | 0xE190 |
| `SDCLOSE` | 0x88D7 | 0xE191 |
| `SDINPUT` | 0x88E3 | 0xE192 |
| `SDPRINT` | 0x88EF | 0xE193 |
| `SDSKIP` | 0x88FB | 0xE194 |
| `STAGE` | 0x8906 | 0xE197 |
| `STSAVE` | 0x8910 | 0xE19E |
| `STLOAD` | 0x891B | 0xE19F |
| `SDEOF` (function) | 0x8926 | 0xE170 |
| `SORGN` | 0x8930 | 0xE1C4 |
| `ECVER` | 0x893A | 0xE195 |
| `MLOGMSG` | 0x8944 | 0xE199 |
| `MLOG` | 0x8950 | 0xE198 |
| `MCONF` | 0x8959 | 0xE19A |
| `FNCLR` | 0x8963 | 0xE19B |
| `FNSAVE` | 0x896D | 0xE19C |
| `FNLOAD` | 0x8978 | 0xE19D |
| `BLSCAN` | 0x8983 | 0xE1A0 |
| `BLCON` | 0x898E | 0xE1A1 |
| `BLDISC` | 0x8998 | 0xE1A2 |
| `BLPRINT` | 0x89A3 | 0xE1A3 |
| `BLLIST` | 0x89AF | 0xE1A4 |
| `BLSAVE` | 0x89BA | 0xE1A5 |
| `BLLOAD` | 0x89C5 | 0xE1A6 |
| `BLCLS` | 0x89D0 | 0xE1A7 |
| `BLADV` | 0x89DA | 0xE1A8 |
| `BLPUT` | 0x89E4 | 0xE1A9 |
| `BLGET` | 0x89EE | 0xE1AA |
| `BLSEND` | 0x89F8 | 0xE1AB |
| `BLRECV` | 0x8A03 | 0xE1AC |
| `BLPAIR` | 0x8A0E | 0xE1AD |
| `BLUNPAIR` | 0x8A19 | 0xE1AE |
| `BLKBD` | 0x8A26 | 0xE1AF |
| `BLSTAT` (function) | 0x8A30 | 0xE152 |
| `BLKEY$` (function) | 0x8A3B | 0xE153 |
| `COLOR` | 0x8A46 | 0xF0B5 |
| `CSIZE` | 0x8A50 | 0xE1C0 |
| `GRAPH` | 0x8A5A | 0xE1C1 |
| `GLCURSOR` | 0x8A64 | 0xE1C2 |
| `LCURSOR` | 0x8A71 | 0xE1C3 |
| `LF` | 0x8A7D | 0xF0B6 |
| `LINE` | 0x8A84 | 0xF0B7 |
| `LLIST` | 0x8A8D | 0xF0B8 |
| `LPRINT` | 0x8A97 | 0xF0B9 |
| `RLINE` | 0x8AA2 | 0xF0BA |
| `ROTATE` | 0x8AAC | 0xE1C5 |
| `TAB` | 0x8AB7 | 0xF0BB |
| `TEST` | 0x8ABF | 0xF0BC |
| `TEXT` | 0x8AC8 | 0xE1C6 |
| `WFSCAN` | 0x8AD1 | 0xE1B0 |
| `WFCON` | 0x8ADC | 0xE1B1 |
| `WFDISC` | 0x8AE6 | 0xE1B2 |
| `WFFORGET` | 0x8AF1 | 0xE1B3 |
| `WFSTAT` (function) | 0x8AFE | 0xE154 |

Table order is load-bearing:
- **The S chain is contiguous**, starting at `SDDF`.
- **`STAGE` is placed inside the S chain**, because the base ROM's skip-scan can't be relied on to
  pass a foreign-letter entry.
- **`MLOGMSG` precedes `MLOG`**, because name matching is a prefix search.
- **`STSAVE`/`STLOAD`, then `SDEOF` and `SORGN`, follow `STAGE` in the S chain.**
- **`MCONF` follows `MLOG`; the F chain (`FNCLR`, the F index slot's entry, then `FNSAVE`,
  `FNLOAD`) follows `MCONF`.**
- **The B chain (`BLSCAN`, the B index slot's entry, through `BLKEY$`) follows `FNLOAD`.** No B
  name is a prefix of a later one (`BLPUT` differs from `BLPRINT` at the 4th letter,
  `BLSEND`/`BLSTAT` from `BLSCAN`/`BLSAVE` by the 4th, `BLKEY$` from `BLKBD` by the 4th).
  `BLCON` was `BLCONNECT` until 2026-09-28; the token is the same.
- **The CE-150 stand-in's C, G, L, R and T chains (2026-09-30) follow `BLKEY$`, each starting at
  its index slot's entry.** The names are the
  CE-150's own; none is a prefix of another. A CE-150's table (B000, PV low) is searched before
  this page, so with one attached its keywords win, both when a line is typed and when it runs.
- **The W chain (2026-10-06, Wi-Fi: `WFSCAN`, the W index slot's entry, then `WFCON`, `WFDISC`,
  `WFFORGET` and the function `WFSTAT`) follows `TEXT`, and the terminator directly follows
  `WFSTAT`.** No W name is a prefix of another; `WFFORGET` contains the built-in `FOR`, as
  `BLPRINT` contains `PRINT`.

Keyword arguments:
- `STAGE`:
  - no argument: show the current mode (`STAGE: MCU` / `RAM` / `MODE UNKNOWN`);
  - `RAM`: stage the ROM into SRAM; with a copy already there it copies again (refreshing it
    after a firmware update, 2026-09-29). The boot hook still skips a verified copy;
  - `DEBUG`: slower per-byte write-and-verify copy, which leaves Remap on after a failure for
    inspection;
  - `MCU`: switch back to MCU-served ROM.
- `MLOG`:
  - no argument: show VERBOSE/QUIET;
  - `VIEW`: browse the log;
  - `VERBOSE` / `QUIET`: turn INFO logging on or off;
  - `RESET`: clear the log.
- `MLOGMSG "text"` or `MLOGMSG A$`: add a `U:` note to the MCU log, up to 23 characters.
- `MCONF`: MCU firmware settings, saved in the MCU's flash:
  - no argument: browse every setting;
  - `NAME`: show one (`LED=1`);
  - `NAME=value`: set one. `LED` (0/1, default 1): flash the LED for SD activity. `SLEEPWAIT`
    (0-65535 ms, default 0): in STAGE RAM mode, stay awake that long after a keyword before
    going DORMANT.
    `LOGSIZE` (KB, default 100, a multiple of 4): the MCU log's size; changing it starts a
    fresh log. `AUTOSTAGE` (0/1, default 0): STAGE RAM at power-on/reset (the boot hook).
    `BLKBD` (0/1, default 0): set up the external keyboard's driver at power-on/reset (the boot
    hook; see "The external keyboard's driver").
    `POWMANDELAY` (-1, or 0-65534 s; default -1): in STAGE RAM mode, a POWMAN power-down on top of
    DORMANT. -1 never; 0 straight to POWMAN after SLEEPWAIT; n DORMANT, then POWMAN if n seconds pass
    with no wake. A POWMAN wake is a reboot: SD files and SDOPEN channels are closed first, and the
    current directory (up to 20 characters, else its deepest parent that fits) is kept in POWMAN's
    scratch registers for the first SD command after it. Measured 2026-10-06: about 4.5 mA less
    than DORMANT. Like DORMANT, only a write to the window wakes it.
  - `HOSTNAME` / `HOSTNAME="name"`: this PC-1500's name on the BLE link (1-15 characters,
    default `PC-1500`), listed last.
- BLE (`RP2350/BLE_PROTOCOL.md`); every failure is ERROR 40 (MLOG VIEW says why):
  - `BLSCAN [seconds]`: scan (default 3 s) and browse the Link peers found; `C` connects.
  - `BLCON name`: connect to the peer advertising that name. (Not the emulator on Windows,
    which can't advertise its own name: use BLSCAN.) `BLDISC`: disconnect.
  - `BLPRINT` (like PRINT), `BLLIST [from[,to]]`, `BLCLS`: text to the peer's console.
  - `BLSAVE` / `BLLOAD`: like `SDSAVE` / `SDLOAD`, with the feature server's file store in
    place of the card.
  - `BLADV`: advertise, and wait for another PC-1500 to connect (BREAK stops).
  - `BLPUT` (the program), `BLPUT M start,end[,call]`, `BLPUT SD [M] name`: offer a file to the
    peer PC-1500, and send it once its `BLGET` accepts. `BLGET` (into memory) or
    `BLGET name[,-Y]` (onto the card): wait for an offer and take it. Either may start first;
    BREAK stops a wait.
  - `BLSEND value[,value...]`: numbers and strings to the peer PC-1500 as one message (waits
    while its 8-message inbox is full; BREAK stops). `BLRECV [#t,]var[,var...]`: the oldest
    message into the variables (extra ones 0 / blank; a type mismatch is ERROR 42); waits until
    one comes (BREAK stops), or up to t seconds (`#0`: not at all), leaving the variables as they
    were if none does.
  - `BLSTAT` (a function): messages waiting (0-8), or -1 with no link and none waiting.
  - `BLKBD`: pair an external Bluetooth keyboard (classic for now), replacing any paired before.
    Needs `MCONF BLKBD=1` (and a reset since, for the driver). Put the keyboard in pairing mode,
    then type the code shown on it and press Enter; BREAK stops. After that it connects by
    itself when a key is pressed. `BLKBD FORGET`: forget it. On an older PC-1500 ROM
    (`PEEK &E2B9` is 213, not 56) the base ROM's keyboard hook doesn't work, so there is no
    driver: `BLKBD` shows `BLKBD: NOT ON THIS ROM`, and the boot hook leaves the hook unarmed.
  - `BLKEY$` (a function): `INKEY$` for either keyboard -- the key down on the PC-1500's own,
    else on the external one, else "". A BASIC program's `INKEY$` becomes `BLKEY$` when it is
    loaded with `MCONF BLKBD=1` (`SDLOAD`, `BLLOAD`, `BLGET`), and a save (`SDSAVE`, `BLSAVE`,
    `BLPUT`) always writes `INKEY$`, so a file stays plain BASIC (`RP2350/basic_xlate.h`).
    Not for M files or a file copied as is (`BLPUT SD`), and not `CLOAD`/`CSAVE`.
- `SDEOF(n)` (a function): 1 once SD channel n has nothing left for `SDINPUT#`, else 0 (not
  open: ERROR 40).
- `SDSAVE` with no name: save as the last BASIC program `SDLOAD` loaded (full path, asks before
  overwriting); ERROR 1 if none since the MCU powered up.
- `ECVER`: show the expansion ROM version (ROM only, doesn't wake the MCU).
- `FNCLR`: zero the function-key definitions, the 195 bytes ending just before the BASIC program
  (7865H/7866H) -- for after a crash has corrupted them. ROM only.
- `FNSAVE` / `FNLOAD`: save the function-key definitions to the MCU's flash / put them back
  (relative to the current program start). `FNLOAD` with nothing saved: ERROR 40.
- `STSAVE` / `STLOAD`: save all of 0000H-7FFFH (and where the `STSAVE` statement was) to the
  MCU's flash / put it back. `STLOAD` resumes right after the `STSAVE` that made the state -- at
  the prompt that just ends the command; saved inside a program, the program carries on from
  there. Nothing saved: ERROR 40. One saved set of each for now.

### `CALL` entry points

| Address | `CALL` | Routine |
|---|---|---|
| 0x8717 | `CALL 34583` | `ROM_RESET_REMAP`: force MCU-served ROM (Remap and write-enable off) |
| 0x9006 | `CALL 36815` | `MEMCOPY`: copy `count` bytes, parameters at 0x8000-0x8005 |
| 0x9029 | `CALL 36850` | `MEMCOPY_PV_SWAP`: same, with PV low for each read and high for each write |

### Other internal entry points

| Address | Label | Purpose |
|---|---|---|
| 0x8B71 | `KW_START` | Every MCU-run keyword: wake the MCU, save S, hand it the statement at Y, run the actions it returns |
| 0x8BE3 | `KW_CONTINUE` | Send `KEYWORD_CONTINUE` and run the next action |
| 0x8BF7 | `SD_RAISE_ERROR_1` | Send `DONE`, then raise ERROR 1 |
| 0x8CD8 | `KW_EVAL` | The EVAL action: `VEJ DE` at the statement offset in A |
| 0x8D56 | `KW_RESTORE` | The RESTORE action (STLOAD's stack page) |
| 0x8D98 | `KW_POLL` | The POLL action: one timer wake, then BREAK? (`VMJ A6`) into ANSWER |
| 0x8DCD / 0x8DFD | `BLSTAT_FN` / `SDEOF_FN` | The functions' table addresses: the command into A, then `FN_CALL` |
| 0x8DFF | `FN_CALL` | A function's MCU round trip (above, "Functions") |
| 0x8F79 | `EC_SEND` | Write the command in A, then fall into `EC_WAIT_NOT_BUSY` |
| 0x8F7C | `EC_WAIT_NOT_BUSY` | Poll the status byte until it isn't BUSY (HLT between polls) |
| 0x8F8F | `EC_WAKE` | Wake the MCU and wait for READY (tight poll, ~3 s timeout per wait, Carry set on timeout) |
| 0x8FCB | `EC_DONE` | Send `DONE` and wait for it to leave BUSY |
| 0x9051 | `STAGE_BOOT_ENTRY` | Boot hook body: wake; with `BLKBD`, `KBD_BOOT_COPY` first; skip staging if already staged or `AUTOSTAGE` is 0, otherwise run the copy in boot mode; with `BLKBD`, `KBD_ARM`; then `DONE` |
| 0x908F | `STAGE_SHOW_OK` | Blank the line, show `STAGE: OK`, wait for a key, return (the copy routine's success exit) |
| 0x90A7 | `STAGE_IS_STAGED` | `ROM_GET_MODE` query (clears the AUTOSTAGE and BLKBD bytes first); Carry set if Remap is on and the MCU vouches for the copy |
| 0x90CA | `KBD_ENTRY` | The keyboard hook's target (via `KBD_HOOK`): `KBD_LOOP` if the loop is there, else ROM1's own E24AH |
| 0x90D8-0x91F3 | `KBD_LOOP` | 284 bytes left empty in the image: ROM1's wait loop goes here (see below) |
| 0x91F4 | `KBD_DISPATCH` | Where the loop hands a key to SML_DISPATCH (E366H): OFF goes to the loop's own power-off instead |
| 0x91FF / 0x9213 / 0x9225 | `KBD_ANY` / `KBD_SCAN` / `KBD_BREAK` | The loop's keyboard reads with the external key added, and the external ON as BREAK |
| 0x9231 / 0x925D | `KBD_BOOT_COPY` / `KBD_ARM` | Boot: copy ROM1's loop to the MCU (`KBD_INSTALL`); set the hook (785BH/785CH, 79D4H = 55H) if the loop is served |

## The external keyboard's driver

For a BLE keyboard (MCONF `BLKBD=1`, default 0). The MCU turns its keys into taps of the
PC-1500's own key matrix (`RP2350/kbd_seq.c`, timed like pc1500emu's host keyboard) and
publishes the key being "held" at 0x87EF. The ROM reads it through the base ROM's keyboard hook:
with 79D4H = 55H, `KEYSCAN_WAIT` (E243H) jumps through the vector at 785BH/785CH (bit 0 of
the low byte picks PV) instead of scanning -- the hook BASWORD uses.

The driver is ROM1's own wait loop, E24AH-E365H, so the external key goes through ROM1's code
table, debounce, auto-repeat and SHIFT/DEF/SML handling like a physical key. The module doesn't
carry Sharp's code. At power-on/reset the boot hook copies the loop from the machine's own ROM to
0x8000 and sends `KBD_INSTALL`. The MCU checks it is ROM1's (CRC-32 8B43EF78H) and patches it
into the ROM image at `KBD_LOOP`, in place:

- its two keyboard reads call `KBD_ANY` and `KBD_SCAN`;
- its two branches to SML_DISPATCH go to `KBD_DISPATCH`;
- its power-off resumes its own loop.

Older ROMs: a real PC-1500's ROM (2026-10-05) has `VEJ F4H,79H,D5H` at E2B7H where ROM1 has
`VEJ CCH,5BH` + NOP. VEJ F4H loads the word at 79D5H into U, not X, and the `STX P` after it
jumps to whatever X held, so that ROM's hook can't be used (BASWORD's `PEEK &E2B9` = 56 test
rejects it too). The MCU refuses its loop (E2B9H isn't 38H; MLOG "KBD: ROM hook unusable"; an
unknown loop logs its CRC), `KBD_ARM` then leaves the hook unarmed, and `BLKBD` shows
`NOT ON THIS ROM`. Known system ROMs (C000H-FFFFH, CRC-32): DCA8F879H and D480B50DH have the
working hook; A4713655H is the older one.

The boot hook sends `KBD_INSTALL` before any staging, so an AUTOSTAGE copy includes the loop, and
sets the hook last (`KBD_ARM`), once the ROM is served as it will stay. Reset clears 79D4H before
the module scan, so the hook only ever comes from here.

- OFF: given to BASIC, the OFF key rewrites 785BH/785CH while 79D4H stays 55H, so the next
  `KEYSCAN_WAIT` after ON would jump into nowhere. `KBD_DISPATCH` sends it to the loop's own
  power-off instead, as BASWORD does.
- ON (BREAK): the MCU counts presses at 0x87F5, and the driver acknowledges each at 0x87FA and
  returns BREAK from `KEYSCAN_WAIT`. A running program can't be stopped this way: it tests the
  ON key's hardware latch (F00BH bit 1).
- `INKEY$` reads the matrix directly (E42CH) and doesn't see the external key.
- A staged copy made without the loop doesn't get the hook until it's staged again (AUTOSTAGE,
  or STAGE RAM then a reset). If the MCU loses the loop under a running PC-1500, `KBD_ENTRY` falls
  back to ROM1's own loop.

## Status and command reference

**`EXP_STATUS_*`** (read at 0x87FF): `BUSY=1`, `SUCCESS=2`, `EOF=3` (`SD_READ_VALUE` only),
`READY=4`, `NOT_IMPLEMENTED=64`, `ERROR=128`. A sleeping MCU reads as 0x00 (0xFF before the
data-pin pull-downs), which is why no status uses 0x00 or 0xFF.

**`EXP_COMMAND_*`** (written to 0x87FF):

| Dec | Hex | Command |
|---|---|---|
| 1 | 0x01 | GET_SD_FREE_SPACE |
| 2 | 0x02 | CREATE_SD_FILE |
| 3 | 0x03 | WRITE_TO_SD_FILE |
| 4 | 0x04 | CLOSE_SD_FILE |
| 5 | 0x05 | GET_SD_FILE_SIZE |
| 6 | 0x06 | READ_SD_VOLUME_LABEL |
| 7 | 0x07 | GET_SD_FILE_NAME |
| 8 | 0x08 | GET_SD_FILE_STATUS |
| 9 | 0x09 | FORMAT_SD_CARD |
| 10 | 0x0A | OPEN_SD_FILE_READ |
| 11 | 0x0B | READ_FROM_SD_FILE |
| 12 | 0x0C | LIST_SD_DIR |
| 14 | 0x0E | REMOVE_SD_FILE |
| 15 | 0x0F | GET_SD_VOLUME_SIZE |
| 16 | 0x10 | CHANGE_SD_DIR |
| 17 | 0x11 | MAKE_SD_DIR |
| 18 | 0x12 | REMOVE_SD_DIR |
| 19 | 0x13 | GET_SD_CWD |
| 20 | 0x14 | COPY_SD_FILE |
| 21 | 0x15 | MOVE_SD_FILE |
| 22 | 0x16 | GET_SD_DF_TEXT |
| 23 | 0x17 | CHECK_SD_COPY_MOVE_DEST_EXISTS |
| 24 | 0x18 | SD_OPEN_CHANNEL |
| 25 | 0x19 | SD_CLOSE_CHANNEL |
| 26 | 0x1A | SD_LIST_CHANNELS |
| 27 | 0x1B | SD_WRITE_VALUE |
| 28 | 0x1C | SD_READ_VALUE |
| 29 | 0x1D | SD_SKIP_VALUES |
| 30 | 0x1E | VALIDATE_SD_NAME |
| 31 | 0x1F | SD_CHANNEL_EOF (SDEOF: in: [channel]; out: [1 = nothing left for SDINPUT#]) |
| 32 | 0x20 | ROM_FROM_MCU |
| 33 | 0x21 | ROM_FROM_SRAM |
| 34 | 0x22 | ROM_COPY_BEGIN |
| 35 | 0x23 | ROM_COPY_GET_BLOCK |
| 36 | 0x24 | ROM_COPY_FINISH |
| 37 | 0x25 | ROM_GET_MODE (byte 0: Remap on; byte 1: Remap on and verified copy; byte 2: MCONF AUTOSTAGE; byte 3: MCONF BLKBD) |
| 38 | 0x26 | LOG_LIST |
| 39 | 0x27 | LOG_CLEAR |
| 40 | 0x28 | LOG_SET_INFO_ENABLED |
| 41 | 0x29 | LOG_BLOCK_CHECKSUM |
| 42 | 0x2A | STAGE_BYTE_MISMATCH |
| 43 | 0x2B | LOG_GET_INFO_ENABLED |
| 44 | 0x2C | DONE (end of keyword; the MCU may sleep in STAGE RAM mode) |
| 45 | 0x2D | LOG_USER_MESSAGE (`MLOGMSG`; string chunk at 0x8001: `'S'`, length, text) |
| 46 | 0x2E | KEYWORD (start a keyword: token + statement at 0x8000; action block back at 0x87E0) |
| 47 | 0x2F | KEYWORD_CONTINUE (after an action that needs the MCU again; ANSWER at 0x87E6) |
| 48 | 0x30 | CONFIG_GET (MCONF; byte 0 = setting number, bytes 1-2 = BE value back) |
| 49 | 0x31 | CONFIG_SET (MCONF; byte 0 = setting number, bytes 1-2 = BE value, saved to flash) |
| 50 | 0x32 | STORE_ERASE (MCU-internal: FNSAVE/STSAVE flash store; parameters at 0x87F0) |
| 51 | 0x33 | STORE_WRITE (MCU-internal) |
| 52 | 0x34 | STORE_READ (MCU-internal) |
| 53 | 0x35 | CONFIG_HOSTNAME_GET (MCONF HOSTNAME; out: [len][name]) |
| 54 | 0x36 | CONFIG_HOSTNAME_SET (in: [len][name], saved to flash) |
| 55 | 0x37 | KBD_INSTALL (in: ROM1's 284-byte wait loop at 0x8000; the MCU checks its CRC and patches it into the ROM image at `KBD_LOOP`; ERROR for another ROM's) |
| 56 | 0x38 | KBD_PAIR (BLKBD: forget any paired keyboard, look for one in pairing mode; ERROR if MCONF BLKBD is 0) |
| 57 | 0x39 | KBD_STATUS (out: [state][code len][code 6][name len][name 16]; states: none, searching, connecting, code, connected, not found, failed, paired) |
| 58 | 0x3A | KBD_STOP (end PAIR's search) |
| 59 | 0x3B | KBD_FORGET (drop the keyboard's bond) |
| 64 | 0x40 | BLE_SCAN (in: [seconds]; out: the Link peers as a `LIST_SD_DIR` listing) |
| 65 | 0x41 | BLE_CONNECT (in: [index into the last scan]; HELLOs; out: [len][peer name]) |
| 66 | 0x42 | BLE_CONNECT_NAME (in: name slot; out: as BLE_CONNECT) |
| 67 | 0x43 | BLE_DISCONNECT |
| 68 | 0x44 | BLE_TEXT (in: [len hi][len lo][text]) |
| 69 | 0x45 | BLE_FILE_PUT (BLSAVE: name slot, [kind][flags][size BE] at 0x802A; then WRITE/CLOSE go to the peer) |
| 70 | 0x46 | BLE_FILE_GET (BLLOAD: name slot; then READ/CLOSE come from the peer; out: [kind]) |
| 71 | 0x47 | BLE_ADVERTISE (in: [1 start / 0 stop]) |
| 72 | 0x48 | BLE_STATUS (out: [flags: linked, advertising, offer in, answered, accepted][len][peer name]) |
| 73 | 0x49 | BLE_OFFER (BLPUT: as BLE_FILE_PUT; SUCCESS once the peer holds the offer) |
| 74 | 0x4A | BLE_WITHDRAW (our offer) |
| 75 | 0x4B | BLE_OFFER_GET (the peer's offer: name slot, [kind][0][size BE] at 0x802A) |
| 76 | 0x4C | BLE_ANSWER (BLGET: in: [1 accept / 0 refuse][1 routed / 0 not]) |
| 77 | 0x4D | BLE_SEND (BLPUT, once accepted: in: [1 routed / 0 not]) |
| 78 | 0x4E | BLE_DATA_WRITE (an unrouted transfer's WRITE: BLPUT SD) |
| 79 | 0x4F | BLE_DATA_READ (an unrouted transfer's READ: BLGET name) |
| 80 | 0x50 | BLE_DATA_CLOSE (in: [1 = abandon]) |
| 81 | 0x51 | BLE_MSG_SEND (BLSEND: in: [len hi][len lo][value chunks]; ERROR [6] = the peer's inbox is full) |
| 82 | 0x52 | BLE_MSG_WAIT (in: [seconds hi][lo], 0xFFFF = no limit, for the next MSG_RECVs) |
| 83 | 0x53 | BLE_MSG_RECV (out: [len hi][len lo][chunks], the oldest message; ERROR [1 = time's up / 0 = keep waiting / 2 = no link]) |
| 84 | 0x54 | BLE_MSG_COUNT (out: [waiting][1 = linked]) |
| 85 | 0x55 | FN_BLSTAT (sent by the ROM's `FN_CALL`: the value at 0x8000, [end of keyword] at 0x8008, [error] at 0x8009) |
| 86 | 0x56 | FN_SDEOF (as FN_BLSTAT; in: the argument, the arithmetic register's 8 bytes at 0x8000) |
| 129 | 0x81 | TEST_COPY_STRING |
| 255 | 0xFF | CLEAR_STATUS (sets READY; also the write `EC_WAKE` uses to wake the MCU) |

The BLE commands and `SD_CHANNEL_EOF` are MCU-internal (keywords.c runs them), like STORE_*. A
"routed" transfer takes over `WRITE_TO_SD_FILE`/`READ_FROM_SD_FILE`/`CLOSE_SD_FILE`, so the
ROM's LOAD/SAVE actions move the bytes to or from the peer. The `FN_*` commands come from the
ROM itself, from inside BASIC's expression evaluator ("Functions", above).

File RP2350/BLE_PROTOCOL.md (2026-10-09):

# PC-1500 Link: the BLE protocol

The protocol between a PC-1500 expansion board and anything it talks to over
Bluetooth Low Energy: the feature-server app (`ble_app/`), another PC-1500,
or the emulator. The firmware (`ble_link`), the app and the emulator all
implement this document. The requirements are in the design Google Doc,
`1JsBLb6IfurR44339UCfs4avSaGKE_G_6TDKPcVkkZ6s`.

Version 2, 2026-10-03: every link is authenticated and encrypted (sec.7,
"Security"); a version-1 peer is refused. Version 1 was 2026-09-27.

Milestone 1 uses `HELLO`, `TEXT`, the file messages,
`BYE`, `ACK` and `ERR`. Milestone 2 (2026-09-28) adds peer-to-peer files
between two PC-1500s: `FILE_OFFER` and `FILE_ANSWER` (sec.5, "Peer-to-peer
files"), then `MSG` (2026-09-29, "Peer messaging"). They're new message
types, not a new version: a side that doesn't know them answers
`ERR UNSUPPORTED`.

## 1. Roles

Both ends of a link are **peers** speaking the same messages. The BLE roles
decide only who finds whom:

- **Advertiser (peripheral, GATT server):** advertises the Link service and
  hosts it. This is the feature-server app, and a PC-1500 that has run `BLADV`
  (peer-to-peer, milestone 2), which waits for another PC-1500 to connect
  with `BLSCAN`/`BLCON`.
- **Connector (central, GATT client):** scans, connects, and subscribes. This
  is a PC-1500 running `BLSCAN`/`BLCON`.

So a PC-1500 always starts things: the user just leaves the app running, and
everything else is driven from the PC-1500. Every PC-1500 can take either
role, since for peer-to-peer one of two PC-1500s must advertise.

## 2. GATT service

| Item | UUID | Properties |
|---|---|---|
| Link service | `c31f0001-92a3-40ab-b63d-7cdb0a37aed0` | primary |
| RX | `c31f0002-92a3-40ab-b63d-7cdb0a37aed0` | write without response (write also allowed) |
| TX | `c31f0003-92a3-40ab-b63d-7cdb0a37aed0` | notify |

- The connector sends by writing RX; the advertiser sends by notifying TX.
  Everything above that is the same in both directions.
- No BLE pairing or bonding: the Link authenticates and encrypts its own
  frames (sec.7), the same over every radio and host.
- The connector requests an ATT MTU of 247 and subscribes to TX before
  sending anything. The link needs an ATT MTU of at least 64: at less, the
  connector disconnects and reports an error.
- **One frame per ATT packet:** a frame is at most `MTU − 3` bytes, so its
  payload is at most `MTU − 7`. Frames are never split across packets; long
  data goes in several frames (`TEXT`, `FILE_DATA`).

## 3. Finding a peer

- A connector scans **actively** (scan requests on), because many advertisers
  put their name and the 128-bit service UUID in the scan response rather
  than the advertisement itself.
- A peer is anything whose advertisement or scan response lists the Link
  service UUID. **Match on the UUID, never on the name:** Windows advertises
  under the computer's name (not the name the app asks for), and may
  advertise twice, once with no name.
- For display before connecting, use the advertised local name, or the
  address if there is none. The peer's real name comes in its `HELLO`.

## 4. Frames

```
offset  size  field
0       1     type
1       1     seq
2       2     len   (payload length, little-endian)
4       len   payload
```

- **seq:** each side numbers the frames it sends: 0, 1, 2, … wrapping at
  255, independently in each direction. `ACK` and `ERR` don't take a number
  of their own: their `seq` is the number of the frame they answer.
- **Every frame except `ACK` and `ERR` is answered** with an `ACK` or an
  `ERR`. A side sends nothing else until the answer arrives: **one frame in
  flight per direction.** This keeps both ends' buffers to one frame, and
  the order of events is always clear.
- **Timeout:** no answer within 5 s means the link has failed. The side that
  noticed disconnects.
- A frame whose `len` doesn't match the packet's length, or whose type is
  unknown, is answered with `ERR BAD_FRAME` or `ERR UNSUPPORTED`. The link
  stays up.

## 5. Messages

Strings are ASCII, preceded by a 1-byte length, with no terminator (`str8`
below). Multi-byte numbers are little-endian.

| Type | Name | Payload |
|---|---|---|
| 0x01 | `HELLO` | `version` u8 (= 2), `kind` u8 (1 PC-1500, 2 server), `name` str8, `id` 8 bytes, `nonce` 16 bytes; the advertiser's adds `known` u8 and, if 1, `proof` 16 bytes (sec.7) |
| 0x03 | `AUTH` | `proof` 16 bytes (sec.7) |
| 0x04 | `PAIR_START` | `pk` 32 bytes (sec.7) |
| 0x05 | `PAIR_NONCE` | `nonce` 16 bytes |
| 0x06 | `PAIR_CONFIRM` | `ok` u8, `mac` 16 bytes |
| 0x02 | `BYE` | none |
| 0x10 | `TEXT` | `channel` u8, then text bytes to the end of the frame |
| 0x20 | `FILE_PUT` | `target` u8, `kind` u8, `flags` u8, `size` u32, `name` str8 |
| 0x21 | `FILE_DATA` | file bytes to the end of the frame |
| 0x22 | `FILE_END` | none |
| 0x23 | `FILE_GET` | `target` u8, `name` str8 |
| 0x24 | `FILE_ABORT` | none |
| 0x25 | `FILE_OFFER` | `kind` u8, `size` u32, `name` str8 (may be empty) |
| 0x26 | `FILE_ANSWER` | `accept` u8 (1 yes, 0 no) |
| 0x30 | `MSG` | value chunks to the end of the frame (peer messaging) |
| 0x40 | `PLOT` | plotter operations to the end of the frame (CE-150 emulation) |
| 0x41 | `TIME` | none; the `ACK` carries `utc_ms` i64 (Unix ms) and `offset` i16 (minutes from UTC) |
| 0x7E | `ACK` | none |
| 0x7F | `ERR` | `code` u8, then an optional ASCII message |

Reserved type ranges: 0x30–0x3F peer messaging (P2P), 0x40–0x5F server
features (web, plotter). An implementation answers types it doesn't know
with `ERR UNSUPPORTED`.

### Connecting: `HELLO`

The connector sends `HELLO` as soon as it has subscribed to TX. The
advertiser `ACK`s it and sends its own `HELLO`, which the connector `ACK`s.
Until then neither side sends anything else. A `version` the receiver doesn't
support is answered `ERR UNSUPPORTED`, and the connector disconnects. The
`HELLO`s also start the authentication: sec.7.

### Ending: `BYE`

`BYE` is `ACK`ed, and then the connector disconnects. A dropped link needs no
`BYE`: whatever was in progress fails with an error on the PC-1500.

### Text: `TEXT`

- `channel` 0 is the console: `BLPRINT` and `BLLIST` output, shown by the app
  in its text window. Other channel numbers are reserved (P2P messaging).
- Lines end with CR (0x0D), as on the PC-1500. Receivers display CR as a new
  line.
- FF (0x0C, form feed) clears the console; text after it starts at the top.
  `BLCLS` sends it, and so does `BLPRINT CHR$(12);`.
- Characters are the PC-1500's: ASCII for 0x20–0x7E; others are passed
  through, and the app shows them however it chooses.
- A long output is sent as several `TEXT` frames; frame boundaries mean
  nothing.

### Files

A file's bytes are exactly what `SDSAVE` writes to the SD card, so files move
between the SD card and the app unchanged:
- `kind` 0 (BASIC): BASIC's tokenized program, as it is in RAM.
- `kind` 1 (M): the 4-byte header `[load hi][load lo][call hi][call lo]`
  (call 0 = none), then the memory bytes.
- `kind` 0xFF: unknown (a server returning a file whose kind it didn't
  record). The loading keyword decides from its own flags, as `SDLOAD` does.

`name`: up to 40 characters, the same rule as SD names.

`target` names what the file is written to or read from **on the receiving
side of the request**:

| target | meaning |
|---|---|
| 0 | the server's file store (the app's folder) |
| 1, 2 | reserved (once meant for peer-to-peer; that uses `FILE_OFFER` instead, where the receiver chooses) |

`flags` bit 0: overwrite an existing file (otherwise `ERR EXISTS`).

**Saving** (`BLSAVE`): the PC-1500 sends `FILE_PUT`, then any number of
`FILE_DATA`, then `FILE_END`. Each frame is `ACK`ed:
- `FILE_PUT`'s `ACK` means "accepted, go ahead". An `ERR` (`EXISTS`, `IO`,
  `BUSY`, `UNSUPPORTED` for a target it doesn't have) ends the transfer.
- `FILE_END`'s `ACK` means the file is completely written. The receiver
  checks that it got exactly `size` bytes, else `ERR IO`. `size`
  0xFFFFFFFF means "not known in advance" (a BASIC save streamed by the ROM),
  and there's no check.
- The sender may give up part-way with `FILE_ABORT` (`ACK`ed); the receiver
  throws the partial file away. The receiver may give up instead by
  answering a `FILE_DATA` with `ERR ABORTED` (e.g. no room left); the sender
  then stops.

**Loading** (`BLLOAD`): the PC-1500 sends `FILE_GET`. The other side `ACK`s
it and becomes the sender: `FILE_PUT` (whose `target`, `flags` are 0),
`FILE_DATA`…, `FILE_END`, with the PC-1500 `ACK`ing each frame. Or it
answers `FILE_GET` with `ERR NOT_FOUND`.

### Peer-to-peer files: `FILE_OFFER`, `FILE_ANSWER`

Between two PC-1500s (milestone 2) the **receiver** decides where a file
goes, and a person runs a keyword on each side, in either order: `BLPUT`
sends, `BLGET` receives. So a transfer starts with an offer, which may wait
a long time for its answer:

1. The sender sends `FILE_OFFER`: the file's `kind` (as above: 0 BASIC,
   1 M), its `size` (0xFFFFFFFF if not known in advance) and a `name`, for
   information only (a program in memory has none, so it may be empty).
2. The receiving side `ACK`s it **at once**, whether or not anyone there is
   running `BLGET` yet: the `ACK` means "held", not "accepted". It answers
   `ERR BUSY` if it already holds an offer or is in a transfer, and a side
   with no peer-to-peer support (the feature-server app) answers
   `ERR UNSUPPORTED`.
3. When `BLGET` takes the offer, the receiver sends `FILE_ANSWER` (1 to
   accept, 0 to refuse -- e.g. it couldn't create the file). The sender
   `ACK`s it. There's no time limit between steps 2 and 3: nothing is in
   flight while an offer is held.
4. After `ACK`ing an accepting `FILE_ANSWER`, the sender sends `FILE_DATA`…
   `FILE_END`, each `ACK`ed by the receiver, exactly as in saving above
   (and the receiver may stop it with `ERR ABORTED`).

The sender may withdraw a held offer with `FILE_ABORT` (`ACK`ed), e.g. on
BREAK; the receiver drops it. A `FILE_ABORT` that crosses an accepting
`FILE_ANSWER` reaches the receiver where it expects `FILE_DATA`, and ends
the transfer there. A dropped link drops any held offer.

Either side may offer, whichever BLE role it has, and each side holds at
most one offer at a time. Where the file goes is the receiver's business:
`BLGET "name"` saves it on its SD card, a bare `BLGET` loads it into memory
(a BASIC file as the program, an M file at its header's load address).

### Peer messaging: `MSG`

Short messages between two PC-1500s' BASIC programs (milestone 2, 2026-09-29):
text, or a game's moves. A message is the values of one `BLSEND`, as value
chunks, the format `SDPRINT#` writes to a file:
- a number: `'N'` (0x4E), then its 8 bytes as BASIC stores them (packed-BCD
  float, TRM sec.5-3-1);
- a string: `'S'` (0x53), its length u8, then its characters.

A `MSG` holds at least one chunk and fits one frame. The receiving side keeps
up to 8 messages, oldest first, until its `BLRECV` takes them:
- it `ACK`s a `MSG` once it's stored, whether or not anyone is running
  `BLRECV`;
- with 8 already waiting it answers `ERR BUSY`, and the sender tries again
  later (`BLSEND` waits, and BREAK stops it);
- a malformed `MSG` (a bad chunk, or one running past the end) is
  `ERR BAD_FRAME`.

A new link empties the inbox; a dropped one doesn't, so a program can still
read what arrived. Either side may send, whichever BLE role it has.

### Plotter: `PLOT` (2026-09-30)

The expansion module can stand in for a Sharp CE-150 printer/plotter. It
answers the CE-150's BASIC commands (`LPRINT`, `LLIST`, `LINE`, `RLINE`,
`GLCURSOR`, `COLOR`, `CSIZE`, `ROTATE`, `GRAPH`, `TEXT`, ...) when no real
CE-150 is attached, and draws on the connected app instead of on paper.

**The PC-1500 sends pen movements, never text or shapes.** Its MCU does
everything a CE-150 does:
- It turns characters into pen strokes (Hershey Roman Simplex, scaled to the
  CE-150's nine `CSIZE` cells and four `ROTATE` directions).
- It turns dashed line types into short strokes.
- It tracks the BASIC coordinate origin (`SORGN`) and TEXT/GRAPH mode.
- It lifts the pen outside the paper, as a CE-150 does.

So the receiver only draws lines, and can print what it drew as-is.

**Units are quarter steps, 0.05 mm.** The CE-150's own plotter step is
0.2 mm (PC-2 service manual, p.39). BASIC's coordinates and the line
drawing stay on whole steps, i.e. multiples of 4. Lettering uses the finer
grid, since a stroke font on a 4 x 6-step `CSIZE 1` cell would be mush.
- **X:** 0-860 across the 43.2 mm plotting width (216 steps, 0-215; the 58
  mm roll has 5 mm left and 9.8 mm right margins outside it). 0 is the left
  edge. The pen never goes outside it.
- **Y:** the position along the paper. Positive is *up* the paper (towards
  what was printed earlier), as on the CE-150, so later output usually has
  smaller Y. Paper feed is simply the pen's Y changing. Its zero is
  arbitrary (where the PC-1500's module started); a receiver places its
  roll relative to the first Y it's sent. Absolute Y is 32-bit, because an
  i16 would only cover 1.6 m of roll.
- The relative ops (i8, ±127 quarter steps = ±6.35 mm) carry most
  lettering strokes in 3 bytes instead of 7.

**Receiver state:** where the pen is, and which pen. Each `PLOT` sets both
first, so a frame needs nothing from earlier ones (a reconnect, or a frame
lost to a dropped link, doesn't throw later drawing off). The receiver keeps
one continuous roll, growing it to include every position the pen reaches;
clearing or saving it is the app's business.

A `PLOT` payload is the pen's state, then a sequence of operations, as many
as fit the frame; multi-byte numbers are little-endian and signed:

| Offset | Field | Meaning |
|---|---|---|
| 0 | `pen` u8 | the pen (0-3) |
| 1 | `x` i16 | where the pen is, up |
| 3 | `y` i32 | |
| 7 | operations | below, to the end of the frame (there may be none: then the frame just says where the pen now rests, e.g. after a paper feed) |

| Op | Name | Operands | Meaning |
|---|---|---|---|
| 0x01 | `MOVE` | `x` i16, `y` i32 | pen up, go to (x, y) |
| 0x02 | `DRAW` | `x` i16, `y` i32 | pen down, draw a line to (x, y) |
| 0x03 | `MOVE_REL` | `dx` i8, `dy` i8 | pen up, move by (dx, dy) |
| 0x04 | `DRAW_REL` | `dx` i8, `dy` i8 | pen down, draw by (dx, dy) |
| 0x05 | `PEN` | `pen` u8 (0-3) | change pen; the receiver maps pens to colours (default: 0 black, 1 blue, 2 green, 3 red, the colours the CE-150 ships with) |

- Operations apply in order. A frame never ends in the middle of one.
  Anything malformed or unknown is `ERR BAD_FRAME` for the whole frame,
  which is then ignored.
- **Each `PLOT` is `ACK`ed once drawn** (one frame in flight, sec.4). A BASIC
  statement returns only after its frames are `ACK`ed, so drawing keeps pace
  with the program, as it would on paper. Each statement's `PLOT`s end with
  the pen where it rests; a statement that only moves the pen (`GLCURSOR`,
  `LF`, a pen-up `LINE`) sends one with no operations, and one that changes
  nothing on paper (`CSIZE`, `COLOR` in GRAPH mode) sends none.
- A side that can't draw (a PC-1500 peer) answers `ERR UNSUPPORTED`. The
  keyword then raises `ERROR 27`, which is also what it raises with no link:
  the PC-1500's own "printer not connected".
- The firmware's `plotter.c` has a portable C decoder (`plot_decode()`) and
  the frame splitter; pc1500emu uses both (its printer panel, `PlotPaper`).
  The laptop app's decoder is `ble_app/lib/plot.dart`.

*Open:*
- whether one `PLOT` per statement is fast enough for drawing-heavy programs
  (e.g. GLOBE's thousands of short `LINE`s), or the MCU should gather
  several statements' operations and send them after a short pause;
- whether a "new sheet"/"cut" operation is wanted.

### The clock: `TIME` (2026-10-08)

Right after a `BLCON` to a server (its `HELLO`'s `kind` is 2), the PC-1500
sends `TIME`, and sets its clock to the server's own local time:
`utc_ms + offset` from the `ACK`. It never asks another PC-1500, and with
`MCONF TIMESYNC=0` it doesn't ask at all. A server too old to know `TIME`
answers `ERR UNSUPPORTED`, and the clock is left alone; the link stays up.

### Errors: `ERR`

| code | name | meaning |
|---|---|---|
| 1 | `BAD_FRAME` | malformed frame |
| 2 | `UNSUPPORTED` | unknown type, version or target |
| 3 | `NOT_FOUND` | no such file |
| 4 | `EXISTS` | file exists and overwrite wasn't requested |
| 5 | `IO` | couldn't read or write, or the size was wrong |
| 6 | `BUSY` | already in a transfer |
| 7 | `ABORTED` | the receiver gave up on the transfer (answering `FILE_DATA`) |
| 8 | `NOT_PAIRED` | the link isn't authenticated: pair first (sec.7) |
| 9 | `AUTH_FAILED` | a proof or confirmation didn't check out |

## 6. Throughput

One frame in flight per direction means one frame per round trip, which is
two to three connection intervals. At a 30 ms interval and a 247-byte MTU
that's roughly 3 KB/s: a 10 KB program takes a few seconds. That's fine for
milestone 1. If it isn't later, the fix is a window of several frames in
flight, not a different framing.

## 7. Security (version 2, 2026-10-03)

The advertiser -- the laptop app above all -- reads and writes files on its
host, and a PC-1500 runs what it loads (`BLGET` of an M file can `CALL` it).
So both ends must know who they're talking to, and nobody else should read
or change what passes. BLE's own pairing can't be relied on for that: what
it offers differs between radios (the Pico 2 W's, an RN4871) and hosts
(Windows, macOS, Linux, iOS, Android), and a GATT server app often can't
control it. So the Link does it itself, the same everywhere:

- **Once per pair of devices, pairing:** an X25519 key exchange, confirmed by
  the people at both ends comparing a six-digit code (as BLE's "numeric
  comparison"). It leaves both sides holding a 32-byte long-term key.
- **Every link:** each side proves it holds that key, and every frame after
  that is encrypted and authenticated (ChaCha20-Poly1305).

### Identities and keys

- Every device has an `id`: 8 random bytes, made once and kept. Pairings are
  found by it (BLE addresses change).
- A pairing record holds the peer's `id`, its name (from its `HELLO`), and
  the long-term key `ltk`. Devices keep them in protected storage: the MCU's
  flash; the app's platform secure storage (Windows DPAPI, the macOS/iOS
  Keychain, the Android Keystore, libsecret on Linux), not synced or backed
  up; the emulator's own file, DPAPI-protected on Windows.
- Either side can forget a pairing; the other then finds it no longer
  authenticates (`ERR AUTH_FAILED` or `NOT_PAIRED`), and the two pair again.

### Starting a link

1. The connector's `HELLO` carries its `id` and a fresh random `nonce_c`.
2. The advertiser `ACK`s it, and looks for a pairing with that `id`. Its own
   `HELLO` carries its `id`, a fresh `nonce_s`, `known` (1 if it found one)
   and, if so, `proof_s` = `auth("S")`.
3. The connector `ACK`s that, then looks for a pairing with the advertiser's
   `id`. If both sides have one and `proof_s` checks out, it sends `AUTH`
   with `proof_c` = `auth("C")`. The advertiser checks it: `ACK`, or
   `ERR AUTH_FAILED` (the connector disconnects).
4. **The `ACK` of `AUTH` is the last frame in the clear.** After it, both
   sides seal every frame, `ACK`s and `ERR`s included (below).

If either side has no pairing, the link stays up but **unpaired**: either
side answers anything but `HELLO`, `BYE` and the pairing frames with
`ERR NOT_PAIRED`. A PC-1500 reports it (`BLCON`: "NOT PAIRED"), and `BLPAIR`
pairs over the same link.

`auth(role)` = the first 16 bytes of HMAC-SHA512(`ltk`, `"PC1500 auth "` |
`role` | `nonce_c` | `nonce_s` | `id_c` | `id_s`), where `role` is the
character `C` or `S` and `|` is concatenation. The session keys are
HKDF-SHA512(`ltk`, salt `nonce_c` | `nonce_s`, info `"PC1500 session"`), 64
bytes: the first 32 encrypt what the connector sends, the rest what the
advertiser sends. Strings are ASCII, without terminators.

### Pairing

The connector starts it (a PC-1500's `BLPAIR`) on an unpaired link. The
advertiser only answers: its `ACK`s carry its side's data, the one place an
`ACK` has a payload.

1. `PAIR_START` (`pk_c`, the connector's fresh X25519 public key). The
   advertiser makes its own key pair and a random `n_s`, and `ACK`s with
   `pk_s` (32) | `commit` (16), `commit` = the first 16 bytes of
   SHA-512(`"PC1500 commit"` | `pk_s` | `pk_c` | `n_s`).
2. `PAIR_NONCE` (`n_c`, 16 random bytes). The advertiser `ACK`s with `n_s`,
   and the connector checks it against `commit`: committing first means a
   man in the middle can't choose its keys to make the codes match.
3. Both sides show the code: the first 4 bytes of SHA-512(`"PC1500 code"` |
   `pk_c` | `pk_s` | `n_c` | `n_s`), read big-endian, mod 1000000, as six
   digits. The people at both ends check that they're the same and accept
   (or refuse) on each side.
4. Both compute `ltk` = HKDF-SHA512(X25519(own secret, peer's public), salt
   `n_c` | `n_s`, info `"PC1500 pair"` | `pk_c` | `pk_s`), 32 bytes. An
   all-zero X25519 result fails the pairing.
5. Once its user has answered, the connector sends `PAIR_CONFIRM` (`ok` 1/0,
   `mac_c` = `confirm("C")`). The advertiser answers:
   - `ERR BUSY` if its user hasn't answered yet: the connector asks again
     shortly, as long as its user waits (BREAK gives up);
   - `ACK` with `ok` 0 if either user refused;
   - `ACK` with `ok` 1 and `mac_s` = `confirm("S")` if both accepted and
     `mac_c` checks out: it keeps the pairing (the connector's `id` and name,
     `ltk`);
   - `ERR AUTH_FAILED` if `mac_c` doesn't check out.

   The connector checks `mac_s` and keeps the pairing too.
6. The connector then starts over with a fresh `HELLO`, which now
   authenticates (above).

`confirm(role)` = the first 16 bytes of HMAC-SHA512(`ltk`, `"PC1500 confirm "`
| `role` | `id_c` | `id_s`). The ephemeral secret keys are wiped when the
pairing ends; a pairing abandoned part-way (a dropped link, BREAK, a refusal)
leaves nothing behind.

### Sealed frames

After `AUTH`'s `ACK`, a frame `[type][seq][len][payload]` goes out as

```
offset  size  field
0       1     type
1       1     seq
2       2     len  = 4 + payload + 16
4       4     counter (u32, little-endian)
8       n     the payload, encrypted
8+n     16    tag
```

- ChaCha20-Poly1305 as in RFC 8439, with the sender's session key; the
  12-byte nonce is 4 zero bytes then the counter as 8 bytes, little-endian;
  the associated data is `type` | `seq` | `counter` (6 bytes).
- Each side counts its frames from 0 for the session. A receiver takes a
  counter it hasn't taken before and no more than 32 below the highest it
  has (frames can cross, e.g. an `ACK` and a request); anything else, and
  any frame whose tag fails, is dropped unanswered.
- So a frame's payload can be 20 bytes shorter than before: at most
  `MTU − 27`. `MSG` holds at most 220 bytes (it was 240).

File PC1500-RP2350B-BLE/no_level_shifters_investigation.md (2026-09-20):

# Dropping the FXMA108 level shifters on PC1500-RP2350B-BLE — investigation notes

Status: **decided to proceed to implementation (2026-09-12)**, on the
basis of the reasoning below — not yet bench-verified. Nothing on the
*original* boards has been changed; the actual direct-connect rework is
being carried out in new working copies (`PC1500-RP2350B-BLE-no-level-shifters/`
and `PC1500-Pico2W-Dongle-no-level-shifters/`) so the originals remain as
a fallback/comparison baseline. This file exists to capture the research
so it isn't lost, and to give Piers/Reddit/whoever a concrete writeup of
the question being asked.

This applies to **both** PC-1500 MCU expansion boards, not just
RP2350B-BLE: the Pico2W-Dongle board has the same exposure (a resistor
divider network protecting the address bus, and a TXS0108EPWR level
shifter protecting the bidirectional data bus) and the same reasoning
applies to it directly.

## The question

The data bus (U7), and the two address-bus level shifters (U11/U12), are
all FXMA108 parts translating the PC-1500's ~4.7-5V (`VCC`) logic to the
RP2350's 3.3V (`IOVDD`) domain. That's 3 chips and roughly 30
connections/traces. If they can be safely removed (tying the PC-1500 side
directly to RP2350 GPIOs), the board simplifies enough that 4-layer
routing might become viable again.

The LH5801 (PC-1500 CPU) almost certainly can't source more than a small
fraction of a mA on its bus outputs — nowhere near enough to force a
low-impedance node. The question is whether that matters, given the
RP2350's own 5V-tolerance spec is written as a voltage limit, not a
current limit.

## What the RP2350 datasheet actually says

Table 1433 ("Absolute maximum ratings"), `V_PIN_FT`:

| IOVDD | Max pin voltage |
|---|---|
| 3.3V | 5.5V |
| 2.5V | 4.2V |
| 1.8V | 3.63V |
| **0V (unpowered)** | **3.63V** |

Section 14.8.2.1 ("Pin types"), verbatim:

> "Fault Tolerant Digital... these pins are described as Fault Tolerant,
> which in this case means that **very little current flows into the pin
> whilst it is below 3.63V and IOVDD is 0V**. Additionally, they will
> tolerate voltages up to 5.5V, provided IOVDD is powered to 3.3V."

Key point: the "very little current flows" guarantee is *scoped to below
3.63V*. Above that, unpowered, Raspberry Pi doesn't characterize or
publish a current-vs-damage curve at all — it's simply stated as exceeding
the absolute maximum rating. **No public source (datasheet, forums, or
community bug reports — see below) publishes an actual current threshold
for this condition.** That's a real gap, not something we failed to find.

## A2 vs A4 stepping (as asked about directly)

No functional GPIO circuit difference — same pad design on both. What
changed with A4 is that Raspberry Pi ran a full qualification campaign and
officially blessed the 5V-tolerance claim (retroactively covering A2/A3
too, since the silicon is identical). Current datasheet wording: **"5V
tolerant (powered), and 3.3V-failsafe (unpowered)."** An RP2350 forum
thread has an RPi engineer (jamesh) noting an earlier, more permissive
datasheet draft "was inadvertently left in at release so we removed it
asap" — plausible root of some community confusion about how tolerant
these pins really are unpowered.

Also from that same forum thread, asked directly whether there's any way
around needing `IOVDD` powered before 5V is applied: **"no, I can't see
any way round this without additional hardware"** (jamesh, RPi).

## Community evidence, weighed on its merits

**For the "it's probably fine within our exposure" side:** the *One ROM*
project (piers.rocks / onerom.org, github.com/piersfinlayson/one-rom)
runs an RP2354 (2MB on-die flash) directly on 5V retro buses -- 
Commodore 64 (character/kernal ROM replacement), VIC-20, PET, Atari 800XL,
TI-99 -- with no level shifting, and reports first PCB revision "just
worked." The specific GPIO 5V-tolerance characterization writeup cited
below tests on "RP2350 A4 stepping" silicon (same pad design as RP2354,
same family), which is the qualification basis for the tolerance claim;
the shipping OneROM hardware itself uses RP2354. Their own measurements: ~15ms from `IOVDD`
present to the RP2350's own code starting to run. The host bus is
electrically active the whole time `IOVDD` is ramping/the chip is in
reset, and it hasn't reportedly killed chips in that project.

**Against:** a contributor on the gusmanb/logicanalyzer GitHub discussion
(#301) claims to have killed an RP2354B this way ("I damaged one of my
RP2354Bs without a level shifter"). **This claim has zero circuit
detail** — no schematic, no statement of what was on the other end of the
pin (a bus signal vs. a low-impedance rail), no series resistor
information, and the poster's own words ("I guess I messed up... I'll
have to look into this a little more") read as an unconfirmed hypothesis,
not a diagnosed failure. The GitHub issue he links as
detail (#308) is unrelated (a stepping/overclocking question). A second
citation in the same thread, offered as evidence of "relatively great
risk" (issue #142), turned out to be about the unrelated E9 **latch-up**
erratum from 2024, not this failure mode at all.

**Bottom line on public evidence:** real people believe they've killed
RP2350/2354 chips this way, but nobody has published a characterized
failure (source impedance, available current, exposure duration). It's
folklore-grade evidence in both directions — enough to take the risk
seriously, not enough to quantify it.

## The other direction: can the MCU's 3.3V drive be read as a valid HIGH?

Everything above is about protecting the MCU's *input* — whether it's
safe to receive the PC-1500's ~4.7V. The data bus (`D0-D7` /
`D0_LV-D7_LV`) is bidirectional: during a read cycle the MCU itself
drives 3.3V onto the bus, which the LH5801/SRAM/GreenPAK glue logic on
the *other* side must recognize as a logic-high. That's a separate
question from GPIO damage, and the OneROM precedent only transfers if
the receiving side's input-high threshold is a fixed voltage (TTL-style)
rather than a percentage of its own ~4.7V supply (CMOS-style) — at 70% of
4.7V that would be ~3.3V, i.e. marginal-to-failing for a 3.3V drive.

**Resolved:** the PC-1500 Technical Reference Manual specifies the bus's
minimum logic-high (`V_IH`) as **2.4V** — a fixed voltage spec, not a
percentage of the bus's own supply. A 3.3V drive from the MCU clears
this with about **0.9V of margin**, the same fixed-threshold situation
that makes OneROM's un-shifted 5V TTL bus work. This closes the gap the
rest of this document left open, for both the address bus (input-only,
already covered above) and the data bus (now covered in both
directions).
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

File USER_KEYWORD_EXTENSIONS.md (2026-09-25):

# User keyword extensions: design ideas

Status: ideas only (2026-09-25), nothing implemented. Written so the work can be picked up later.

Goal: someone who has an LH5801 routine and a keyword name for it (already checked for conflicts)
can add it to the expansion ROM without learning its internals.

## What makes it hard today

- **The keyword table is edited by hand** (`rom/rom.asm`), and its layout rules were found the hard
  way (see `Documents/PC1500/PC1500_BASIC_Keyword_Extension_Mechanism.md` §1-§4):
  - one first-letter index;
  - every marker that isn't first for its letter needs bit 4 clear;
  - a name that is a prefix of another must come after the longer one (SDRMDIR before SDRM);
  - a terminator right after the last entry of each letter chain;
  - a unique E1xx code per keyword.
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

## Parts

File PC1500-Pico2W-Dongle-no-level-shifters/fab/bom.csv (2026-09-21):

Refs | Value | Footprint | Qty | DNP
C1,C2 | 10uF | Capacitor SMD:C 0603 1608Metric | 2
C3,C4,C5,C6,C7,C8 | 100nF | Capacitor SMD:C 0603 1608Metric | 6
D1 | PMEG6010ELR | Diode SMD:D SOD 123F | 1
J1 | PC1500 60Pin Connector | Pico2W Dongle Footprints:HIF6A 60PA 1.27DS | 1
J2 | microSD | Connector Card:microSD HC Molex 104031 0811 | 1
J3 | INT / GP28 / GND | Connector PinHeader 2.54mm:PinHeader 1x03 P2.54mm Vertical | 1
J5 | GP2 Spare IO | Connector PinHeader 2.54mm:PinHeader 1x03 P2.54mm Vertical | 1
JP3 | 1500A | Connector PinHeader 2.54mm:PinHeader 1x02 P2.54mm Vertical | 1
Q1 | Si2333 | Package TO SOT SMD:SOT 23 | 1
Q2 | MMBT2222A | Package TO SOT SMD:SOT 23 | 1
R1 | 330Ω | Resistor SMD:R 0201 0603Metric | 1
R2 | 910Ω | Resistor SMD:R 0201 0603Metric | 1
R3,R4,R5,R6,R7,R8,R9,R10 | 10kΩ | Resistor SMD:R 0201 0603Metric | 8
R11,R12 | 2KΩ | Resistor SMD:R 0201 0603Metric | 2
R13,R14 | 1.5KΩ | Resistor SMD:R 0201 0603Metric | 2
SCL1,SDA1 | GP1 GP2 I2C link | Connector PinHeader 2.54mm:PinHeader 1x02 P2.54mm Vertical | 2
U1 | Pico2W | Pico2W Dongle Footprints:Pico2W Socket | 1
U2 | AS6C62256 55SIN | Package SO:SOP 28 8.4x18.16mm P1.27mm | 1
U3,U4 | SLG46826G | Package SO:TSSOP 20 4.4x6.5mm P0.65mm | 2
U5 | SC18IS602B | Package SO:TSSOP 16 4.4x5mm P0.65mm | 1
U7 | NCP1117 ADJ | Package TO SOT SMD:SOT 223 3 TabPin2 | 1
U8 | TCA9406DC | Package SO:VSSOP 8 3x3mm P0.65mm | 1

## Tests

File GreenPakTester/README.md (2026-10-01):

# GreenPakTester

Pico 2 W bench-test firmware for a Renesas GreenPAK SLG46826V (GreenPAK6,
20-pin) on a breadboard. Drives/reads the GreenPAK's IO pins to verify
its programmed logic, and talks to it over I2C. This is a standalone
bring-up tool, not part of the PC-1500 expansion board firmware itself,
though the chip under test ("GP1") is the same GreenPAK design used on
the real board (`../../PC1500ExpansionBoard/GreenPak/GP1-SRAM.gp6` --
address-decode glue logic for the expansion SRAM/ROM).

## Wiring (all at 3.3V -- GreenPAK powered from the Pico's own rail, no level shifters needed)

| Signal | Pico GPIO | GreenPAK pin | Function |
|---|---|---|---|
| I2C0 SDA | GP0 | 9 | SDA |
| I2C0 SCL | GP1 | 8 | SCL |
| IO0 | GP2 | 2 | IO0 |
| IO1 | GP3 | 3 | IO1 |
| IO2 | GP4 | 4 | IO2 |
| IO3 | GP5 | 5 | IO3 |
| IO4 | GP6 | 6 | IO4 |
| IO5 | GP7 | 7 | IO5 ("R/W from bus") |
| IO6 | GP10 | 10 | IO6 |
| IO7 | GP12 | 12 | IO7 |
| IO8 | GP13 | 13 | IO8 |
| IO9 | GP15 | 15 | IO9 |
| IO10 | GP16 | 16 | IO10 ("R/W to SRAM") |
| IO11 | GP17 | 17 | IO11 |
| IO12 | GP18 | 18 | IO12 ("SRAM CS") |
| IO13 | GP19 | 19 | IO13 |
| IO14 | GP20 | 20 | IO14 |
| VDD | 3V3 | 1 | power |
| GND | GND | 11 | ground |
| VDD2 | 3V3 | 14 | power |

Encoded in `greenpak_pins.c` -- edit there if the wiring changes.

**Add a real discrete external pull-down resistor on any pin the bench
drives as an input to the GreenPAK (address bus, DME0, PV, R/W-from-bus,
OD, 1500A-sense).** Confirmed on real hardware 2026-09-16: after such a
pin has been actively driven and then released to Hi-Z, the RP2350 lets
it bleed a residual "ghost" voltage back onto the line (measured ~1.9V
resting between periodic 3.3V pulses on IO14/DME0, GPIO20) that the
firmware's own internal weak pull-down (`greenpak_gpio_release_pulled_down()`,
~50-80k ohm) does not fully suppress -- this cost real debugging time
before being traced to the RP2350 rather than to test-vector logic or
breadboard noise. A real external pull-down, well below that internal
value, resolved it. GreenPAK output pins being read (CS, R/W to SRAM,
GP2's read/write triggers) don't need this.

## Building

Same pattern as `../RP2350`:

```
mkdir build && cd build
cmake -G Ninja -DCMAKE_PREFIX_PATH="C:/Users/paulc/.pico-sdk/toolchain/picotool-2.3.0;C:/Users/paulc/.pico-sdk/toolchain/pico-sdk-tools-2.3.0" ..
ninja
```

Requires `PICO_SDK_PATH` set (already configured on this machine, pointing
at `~/.pico-sdk/sdk/2.3.0`). The `CMAKE_PREFIX_PATH` above points CMake at
the pre-installed `picotool`/`pioasm` that ship with the pico-sdk installer
-- without it, CMake tries to build picotool from source using whatever
host `cc`/`c++` it finds first on PATH, which on this machine resolves to
an ancient MinGW GCC 4.7.2 (`C:\Flex Windows\gcc\bin`) too old to compile
picotool's C99/C++11 sources, and the build fails deep in mbedtls/picotool
internals rather than in this project's own code. `../RP2350`/`../RP2350B`
already have this baked into their cached `build/CMakeCache.txt`, which is
why a bare `cmake ..` works for them without the flag once already
configured -- a truly fresh `cmake ..` there would hit the same failure.

Flash `greenpak_tester.uf2` via BOOTSEL mode. View debug output over the
USB CDC serial port (e.g. the Pico VS Code extension's serial monitor).

## Bring-up sequence

Work through these in order rather than trusting the full self-test
immediately -- several steps deliberately come before the GreenPAK is
even wired in, to isolate Pico-side bugs from chip-side ones:

1. Build+flash the firmware as-is and confirm it enumerates as a USB CDC
   device and prints the startup banner. Validates toolchain/board
   id/CMake before anything hardware-specific.
2. **No GreenPAK attached yet:** blink one mapped GPIO (e.g. GP2/IO0)
   and confirm with a multimeter/LED that it toggles -- validates the
   pin table against the physical breadboard wiring.
3. **Still no GreenPAK:** jumper two mapped GPIOs together (e.g.
   GP2<->GP3) and confirm `greenpak_gpio_drive`/`greenpak_gpio_read` see
   each other -- exercises the exact code path the self-test uses, with
   zero risk to the chip.
4. Power up the GreenPAK (VDD/VDD2/GND only, no signal GPIO yet) and
   confirm with a meter it sees a clean 3.3V and draws sane idle current.
5. Wire GP0/GP1 to GreenPAK pins 9/8. `greenpak_i2c_detect_dut()` (see
   `greenpak_i2c.h`) does exactly this bus scan automatically at boot --
   confirmed working against real hardware: GP1-SRAM.gp6's compiled
   control code is `0011`, giving I2C address `0x18`
   (`GREENPAK_GP1_I2C_ADDR`); GP2's design is compiled with `0010`
   (`0x10`, `GREENPAK_GP2_I2C_ADDR`).
6. Wire and test one IO pin (e.g. GP2/IO0) against the live chip before
   wiring the rest.
7. Wire the remaining 14 IO connections, re-checking each pin
   individually (not just in aggregate) to localize any wiring mistakes.
8. Run the placeholder self-test end-to-end with full wiring in place --
   validates harness plumbing; the PASS/FAIL result itself is
   meaningless until real vectors replace the placeholder.
9. Once real GP1 truth-table data is available (GreenPAK Designer
   truth-table export, or decoded LUT data), replace `example_vectors`
   in `selftest.c` with real ones for a first meaningful run.

## Known open items

- GP1's I2C address (`0x18`) is confirmed against real hardware. GP1's
  vectors were re-derived 2026-09-16 after finding DME0 (J3 pin 6) had
  been treated as active-low when it's actually active-high -- the LUT
  programming for both GreenPAKs was corrected, and every DME0-gated
  expected result in `test_vectors`/`test_vectors_gp2` was flipped to
  match (see `selftest.c`'s per-vector comments). Not yet re-run against
  real hardware since the fix -- treat prior "N/N passing" hardware
  confirmations as stale until it is. GP2's address (`0x10`) matches its
  compiled control code. `test_vectors_gp2` in `selftest.c` is no longer a
  pure placeholder -- `GP2-MCU.gp6` now exists (`../../../PC1500ExpansionBoard/GreenPak/`)
  and `write_trigger`'s address decode was updated 2026-09-23 to
  8000H-87FFH only (was the whole ROM range); Tests 8/10-12 were updated/
  added to match. `read_trigger`'s formula is still only from the design
  doc, not independently re-derived from this specific `.gp6` -- see
  `selftest.c`'s own header comment for exactly what's confirmed vs. not.
  Not yet run against real GP2 hardware at all.
- `selftest.c`'s `example_vectors` is explicitly fake, for exercising the
  harness only -- not real GP1 behavior.
- Pull-up/pull-down needs on individual IO pins during test depend on
  whether GP1's design configures a given output push-pull or
  open-drain, which isn't decoded from the LUT -- left as a per-call
  choice (`greenpak_gpio_release` applies no pull) rather than hardcoded.
- No interactive re-trigger (serial command) or generic NVM read/write
  beyond the register helpers in `greenpak_i2c.h` -- natural follow-on
  once the register protocol/address is confirmed.

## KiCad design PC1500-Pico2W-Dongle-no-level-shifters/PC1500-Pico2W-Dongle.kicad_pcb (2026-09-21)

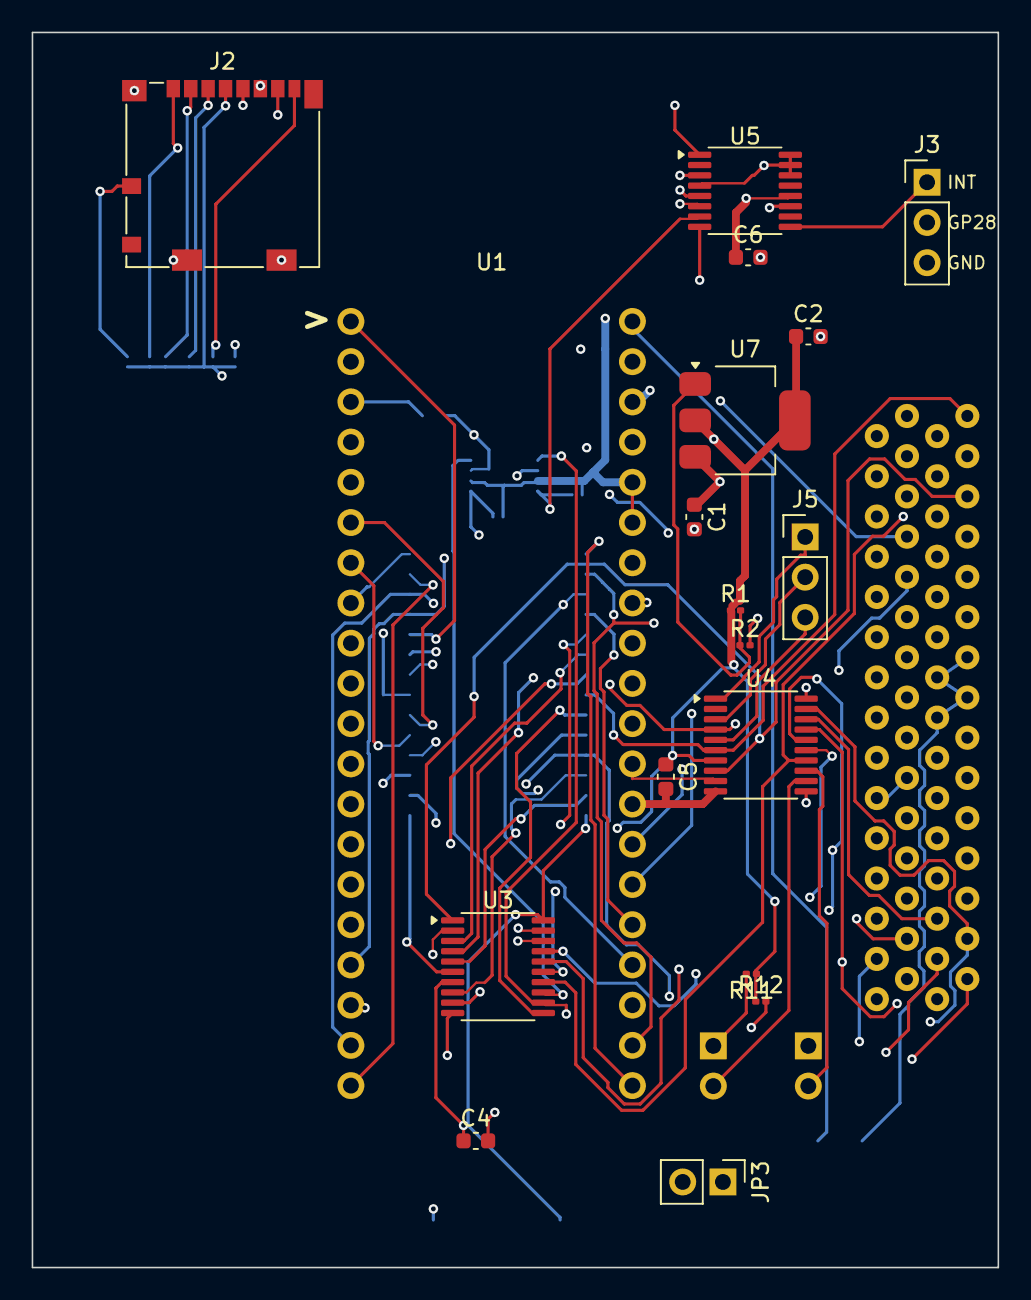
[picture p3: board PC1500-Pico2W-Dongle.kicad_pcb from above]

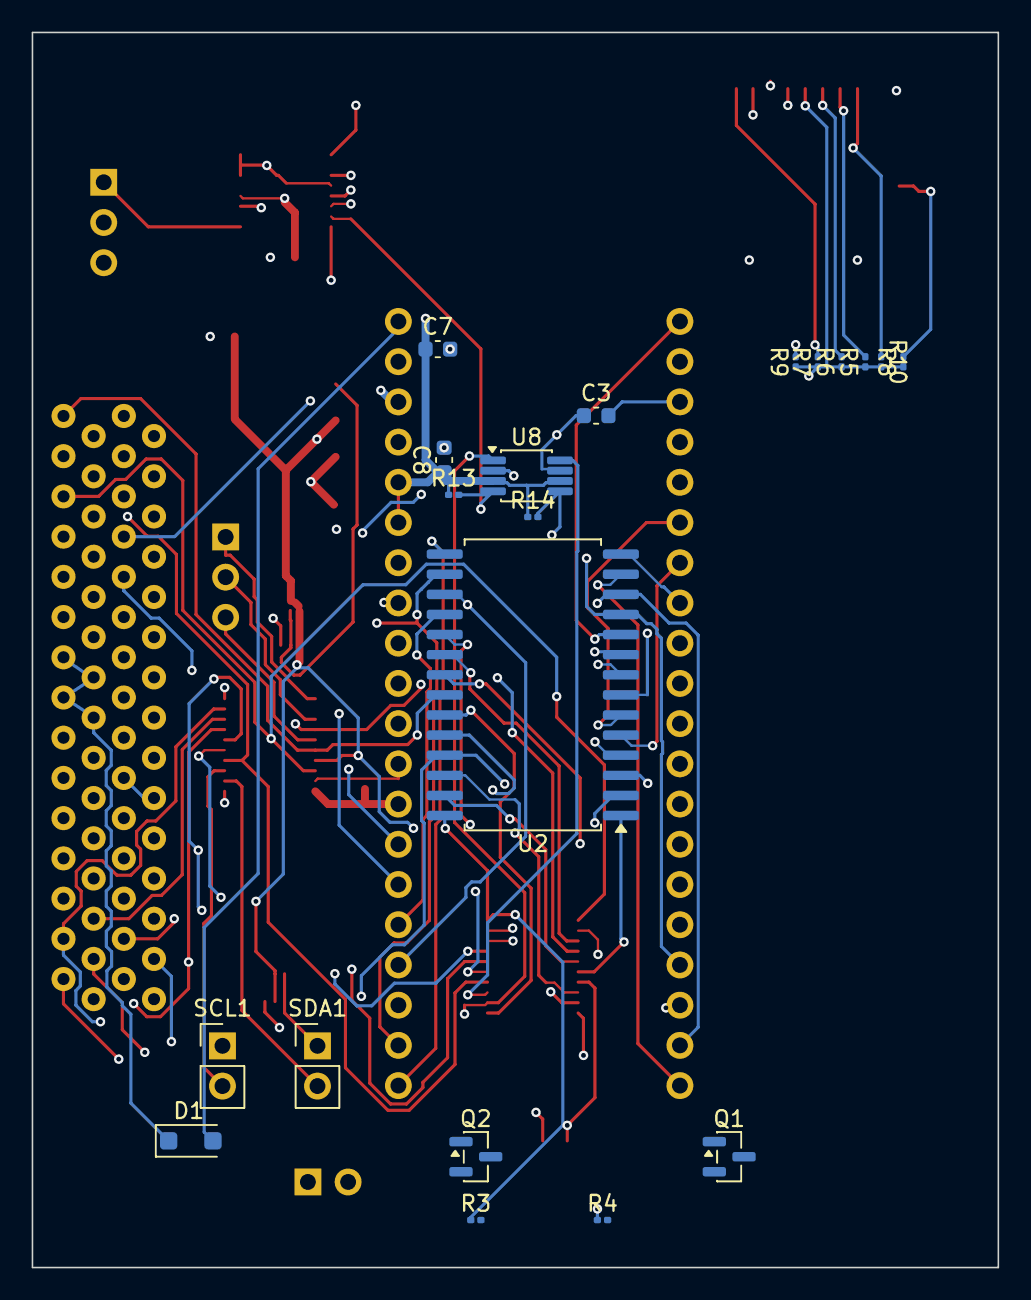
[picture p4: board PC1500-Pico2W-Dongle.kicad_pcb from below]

Board: 4 copper layers, 61.0 x 78.0 mm, 39 parts (20 on the bottom side), 64 nets.

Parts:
C1, C2: 10uF; C_0603_1608Metric
C3, C4, C5, C6, C7, C8: 100nF; C_0603_1608Metric
D1: PMEG6010ELR; D_SOD-123F
J1: PC1500_60Pin_Connector; HIF6A-60PA-1.27DS
J2: microSD; microSD_HC_Molex_104031-0811
J3: INT / GP28 / GND; PinHeader_1x03_P2.54mm_Vertical
J5: GP2_Spare_IO; PinHeader_1x03_P2.54mm_Vertical
JP3: 1500A; PinHeader_1x02_P2.54mm_Vertical
Q1: Si2333; SOT-23
Q2: MMBT2222A; SOT-23
R1: 330; R_0201_0603Metric
R2: 910; R_0201_0603Metric
R3, R4, R5, R6, R7, R8, R9, R10: 10k; R_0201_0603Metric
R11, R12: 2K; R_0201_0603Metric
R13, R14: 1.5K; R_0201_0603Metric
SCL1: GP1-GP2 I2C link; PinHeader_1x02_P2.54mm_Vertical
SDA1: GP1-GP2 I2C link; PinHeader_1x02_P2.54mm_Vertical
U1: Pico2W; Pico2W-Socket
U2: AS6C62256-55SIN; SOP-28_8.4x18.16mm_P1.27mm
U3, U4: SLG46826G; TSSOP-20_4.4x6.5mm_P0.65mm
U5: SC18IS602B; TSSOP-16_4.4x5mm_P0.65mm
U7: AP1117-ADJ; SOT-223-3_TabPin2
U8: TCA9406DC; VSSOP-8_3x3mm_P0.65mm

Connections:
3V3: C6.1, C7.1, C8.1, J2.4 (VDD), R5.1, R6.1, R7.1, R8.1, R9.1, R10.2, R13.1, R14.1, U1.35 (ADC_VREF), U1.36 (3V3), U5.12 (VDD), U8.3 (VCCA), U8.6 (OE)
+4V7: J1.11 (+4V7), J1.12 (+4V7), J1.41 (+4V7), J1.42 (+4V7), R4.1
+BATT: C1.1, D1.1 (K), J1.45 (+BATT), J1.46 (+BATT), J1.47 (+BATT), J1.48 (+BATT), U7.3 (VI)
AD0: J1.8 (AD0), U1.1 (GP0), U2.10 (A0)
AD1: J1.7 (AD1), U1.2 (GP1), U2.9 (A1)
AD2: J1.6 (AD2), U1.4 (GP2), U2.8 (A2)
AD3: J1.5 (AD3), U1.5 (GP3), U2.7 (A3)
AD4: J1.4 (AD4), U1.6 (GP4), U2.6 (A4)
AD5: J1.3 (AD5), U1.7 (GP5), U2.5 (A5)
AD6: J1.2 (AD6), U1.9 (GP6), U2.4 (A6)
AD7: J1.1 (AD7), U1.10 (GP7), U2.3 (A7)
AD8: J1.31 (AD8), U1.11 (GP8), U2.25 (A8)
AD9: J1.32 (AD9), U1.12 (GP9), U2.24 (A9)
AD10: J1.33 (AD10), U1.14 (GP10), U2.21 (A10)
AD11: J1.34 (AD11), U1.15 (GP11), U3.19 (IO0), U4.19 (IO0)
AD12: J1.35 (AD12), U1.16 (GP12), U3.18 (IO1), U4.18 (IO1)
AD13: J1.36 (AD13), U3.17 (IO2), U4.17 (IO2)
AD14: J1.37 (AD14), U3.16 (IO3), U4.16 (IO3)
AD15: J1.38 (AD15), U3.15 (IO4), U4.15 (IO4)
D0: J1.24 (D0), U1.17 (GP13), U2.11 (Q0)
D1: J1.23 (D1), U1.19 (GP14), U2.12 (Q1)
D2: J1.22 (D2), U1.20 (GP15), U2.13 (Q2)
D3: J1.21 (D3), U1.21 (GP16), U2.15 (Q3)
D4: J1.20 (D4), U1.22 (GP17), U2.16 (Q4)
D5: J1.19 (D5), U1.24 (GP18), U2.17 (Q5)
D6: J1.18 (D6), U1.25 (GP19), U2.18 (Q6)
D7: J1.17 (D7), U1.26 (GP20), U2.19 (Q7)
DME0: J1.56 (DME0), U3.1 (IO14), U4.8 (IO8)
FGND: J1.43 (FGND), J1.44 (FGND)
GND: C1.2, C2.2, C3.2, C4.2, C5.2, C6.2, C7.2, C8.2, J1.52 (GND), J1.53 (GND), J1.54 (GND), J1.55 (GND), J2.6 (VSS), J2.SH, J3.3, JP3.2, R2.2, U1.3 (GND), U1.8 (GND), U1.13 (GND), U1.18 (GND), U1.23 (GND), U1.28 (GND), U1.33 (GND), U1.38 (GND), U2.14 (GND), U3.10 (GND), U4.10 (GND), U5.4 (VSS), U5.14 (A0), U5.15 (A1), U5.16 (A2), U8.2 (GND)
GP28: J3.2, U1.34 (GP28)
GREENPAK2_IO10: J5.3, U4.5 (IO10)
GREENPAK2_IO12: J5.2, U4.3 (IO12)
GREENPAK2_IO14: J5.1, U4.1 (IO14)
unnamed: J2.1 (CD/DAT3), R10.1
OD: J1.60 (OD), U2.22 (~OE), U4.6 (IO9)
PC1500_SENSE: JP3.1, U3.2 (IO13)
PV: J1.15 (PV), U3.4 (IO11), U4.4 (IO11)
RW: J1.57 (RW), U3.14 (IO5), U4.14 (IO5)
SCL: R14.2, U1.32 (GP27), U5.8 (SCL), U8.5 (SCL_A)
SCL_GP: R12.2, SCL1.1, U3.13 (SCL), U8.8 (SCL_B)
SCL_GP_U4: SCL1.2, U4.13 (SCL)
SC_RESET: R9.2, U5.3 (~RESET)
SDA: R13.2, U1.31 (GP26), U5.7 (SDA), U8.4 (SDA_A)
SDA_GP: R11.2, SDA1.1, U3.12 (SDA), U8.1 (SDA_B)
SDA_GP_U4: SDA1.2, U4.12 (SDA)
SD_CS: J2.2 (CMD), R5.2, U5.1 (~SS0~/GPIO0)
SD_DAT1: J2.8 (DAT1), R7.2
SD_DAT2: J2.9 (DAT2), R8.2
SD_MISO: J2.7 (DAT0), U5.5 (MISO)
SD_MOSI: J2.3 (VSS), R6.2, U5.6 (MOSI)
SD_SCK: J2.5 (CLK), U5.11 (SPICLK)
SRAM_A11: U2.23 (A11), U3.11 (IO6)
SRAM_A12: U2.2 (A12), U3.9 (IO7)
SRAM_A13: U2.26 (A13), U3.8 (IO8)
SRAM_A14: U2.1 (A14), U3.6 (IO9)
SRAM_CS: U2.20 (~CS), U3.3 (IO12)
SRAM_WE: U2.27 (~WE), U3.5 (IO10)
TRIG_RD: U1.27 (GP21), U4.11 (IO6)
TRIG_WR: U1.29 (GP22), U4.9 (IO7)
VBUS: D1.2 (A), U1.40 (VBUS)
VGG: C2.1, C3.1, C4.1, C5.1, R1.1, R3.1, R11.1, R12.1, U2.28 (VCC), U3.7 (V_{DD2}), U3.20 (V_{DD}), U4.7 (V_{DD2}), U4.20 (V_{DD}), U7.2 (VO), U8.7 (VCCB)
VGG_FB: R1.2, R2.1, U7.1 (ADJ)
~INT: J3.1, U5.9 (~INT)

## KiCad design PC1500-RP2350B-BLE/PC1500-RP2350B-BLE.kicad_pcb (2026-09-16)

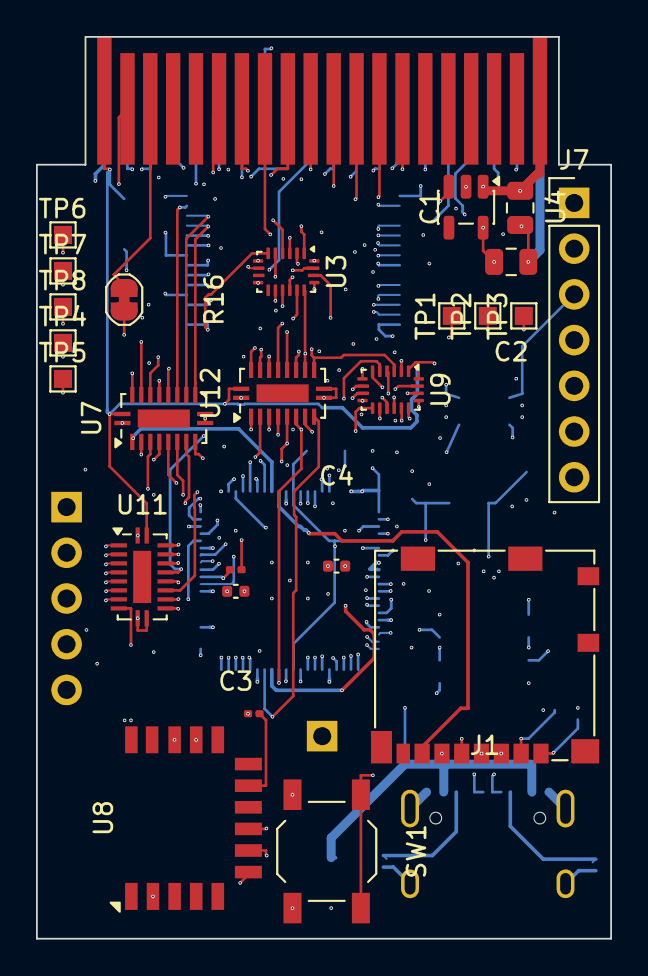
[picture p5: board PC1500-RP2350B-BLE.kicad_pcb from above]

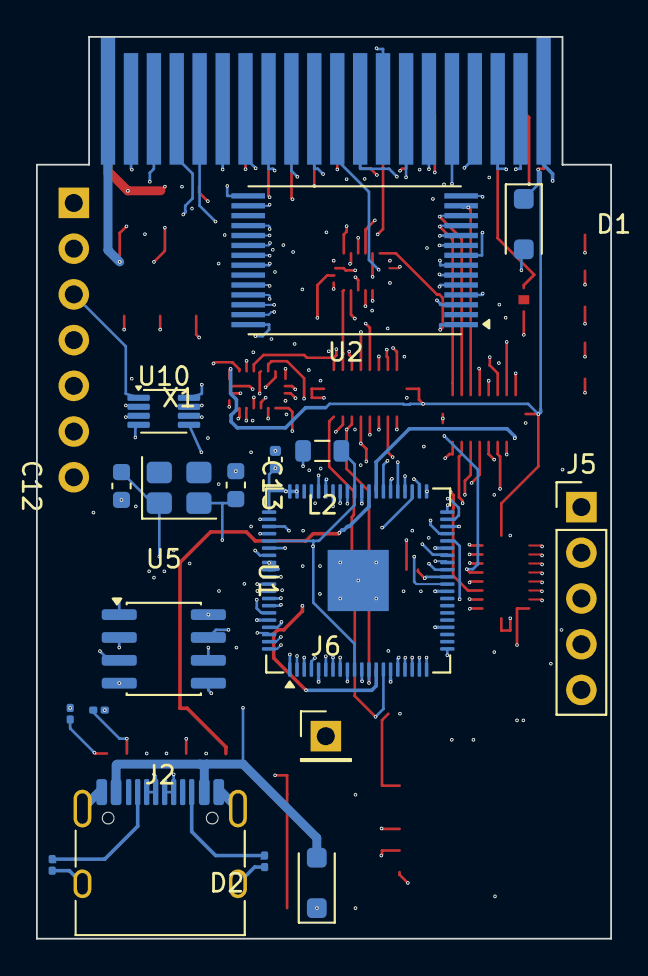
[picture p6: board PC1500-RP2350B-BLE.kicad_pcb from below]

Board: 8 copper layers, 31.9 x 50.1 mm, 44 parts (18 on the bottom side), 104 nets.

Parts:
C1, C2: 10uF; C_0805_2012Metric
C3, C4, C14: 100nF; C_0402_1005Metric
C12, C13: 15pF; C_0603_1608Metric
D1, D2: PMEG6010ELR; D_SOD-123F
J1: microSD; microSD_HC_Molex_104031-0811
J2: USB-C (programming/debug); USB_C_Receptacle_HRO_TYPE-C-31-M-12
J3: PC-1500 40-pin cartridge slot; SHARP-PC-CARTRIDGE
J5: PC1500_SENSE_JUMPER; PinHeader_1x05_P2.54mm_Vertical
J6: SPARE_GPIO_U9; PinHeader_1x01_P2.54mm_Vertical
J7: SWD_I2C_HEADER; PinHeader_1x07_P2.54mm_Vertical
L2: 1uH; L_0805_2012Metric
R9, R10: 5K1; R_0201_0603Metric
R11: 1K; R_0201_0603Metric
R14, R17, R18: 10K; R_0201_0603Metric
R16: Jumper_2_Bridged; SolderJumper-2_P1.3mm_Bridged_RoundedPad1.0x1.5mm
SW1: BOOTSEL; SW_SPST_TL3342
TP1: TRIG_RD; TestPoint_Pad_1.0x1.0mm
TP2: AD15_MCU; TestPoint_Pad_1.0x1.0mm
TP3: AD13_MCU; TestPoint_Pad_1.0x1.0mm
TP4: GPIO19; TestPoint_Pad_1.0x1.0mm
TP5: GPIO20; TestPoint_Pad_1.0x1.0mm
TP6: GPIO44; TestPoint_Pad_1.0x1.0mm
TP7: GPIO45; TestPoint_Pad_1.0x1.0mm
TP8: GPIO34; TestPoint_Pad_1.0x1.0mm
U1: RP2350B; QFN-80-1EP_10x10mm_P0.4mm_EP3.4x3.4mm
U2: AS6C62256-55STCN; AS6C62256_STSOP-28_11.8x8mm_P0.55mm
U3, U9: SLG46826V; Renesas_UQFN-20_2x3mm_P0.4mm_LayoutBorder4x6y
U4: AP2112K-3.3; SOT-23-5
U5: W25Q32RVXHJQ; SOIC-8_3.9x4.9mm_P1.27mm
U7, U11, U12: FXMA108; WQFN-20-1EP_2.5x4.5mm_P0.5mm_EP1x2.9mm
U8: RN4871; Microchip_RN4871
U10: TCA9406DCUR; VSSOP-8_2.3x2mm_P0.5mm
X1: 12MHz (Abracon ABM8-272-T3); Crystal_SMD_3225-4Pin_3.2x2.5mm

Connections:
+3V3: C2.2, C3.2, C4.2, C14.1, J1.4 (VDD), J5.5, R14.1, R17.1, R18.1, U1.5 (IOVDD), U1.15 (IOVDD), U1.24 (IOVDD), U1.29 (IOVDD), U1.35 (RUN), U1.41 (IOVDD), U1.50 (IOVDD), U1.59 (ADC_AVDD), U1.60 (IOVDD), U1.61 (VREG_AVDD), U1.64 (VREG_VIN), U1.68 (USB_OTP_VDD), U1.69 (QSPI_IOVDD), U1.76 (IOVDD), U4.5 (VOUT), U5.8 (VCC), U7.1 (VCCA), U8.14 (VBAT), U9.7 (V_{DD2}), U10.3 (VCCA), U10.6 (OE), U11.1 (VCCA), U12.1 (VCCA)
AD0: J3.37, U2.10 (A0), U11.19 (B0)
AD0_MCU: U1.77 (GPIO0), U11.2 (A0)
AD1: J3.36, U2.9 (A1), U11.18 (B1)
AD1_MCU: U1.78 (GPIO1), U11.3 (A1)
AD2: J3.35, U2.8 (A2), U11.17 (B2)
AD2_MCU: U1.79 (GPIO2), U11.4 (A2)
AD3: J3.34, U2.7 (A3), U11.16 (B3)
AD3_MCU: U1.80 (GPIO3), U11.5 (A3)
AD4: J3.33, U2.6 (A4), U11.15 (B4)
AD4_MCU: U1.1 (GPIO4), U11.6 (A4)
AD5: J3.32, U2.5 (A5), U11.14 (B5)
AD5_MCU: U1.2 (GPIO5), U11.7 (A5)
AD6: J3.31, U2.4 (A6), U11.13 (B6)
AD6_MCU: U1.3 (GPIO6), U11.8 (A6)
AD7: J3.30, U2.3 (A7), U11.12 (B7)
AD7_MCU: U1.4 (GPIO7), U11.9 (A7)
AD8: J3.29, U2.25 (A8), U12.19 (B0)
AD8_MCU: U1.6 (GPIO8), U12.2 (A0)
AD9: J3.28, U2.24 (A9), U12.18 (B1)
AD9_MCU: U1.7 (GPIO9), U12.3 (A1)
AD10: J3.27, U2.21 (A10), U12.17 (B2)
AD10_MCU: U1.8 (GPIO10), U12.4 (A2)
AD11: J3.26, U3.19 (IO0), U12.16 (B3)
AD11_MCU: U1.9 (GPIO11), U9.8 (IO8), U12.5 (A3)
AD12: J3.25, U3.18 (IO1), U12.15 (B4)
AD12_MCU: U1.11 (GPIO12), U9.6 (IO9), U12.6 (A4)
AD13: J3.24, U3.17 (IO2), U12.14 (B5)
AD13_MCU: U1.12 (GPIO13), U9.5 (IO10), U12.7 (A5)
AD14: J3.23, TP2.1 (1_1), U3.16 (IO3), U9.16 (IO3), U12.13 (B6)
AD14_MCU: U1.13 (GPIO14), U9.4 (IO11), U12.8 (A6)
AD15: J3.22, U3.15 (IO4), U9.3 (IO12), U12.12 (B7)
AD15_MCU: U1.14 (GPIO15), U12.9 (A7)
BLE_RST: R14.2, U8.10 (RST)
BLE_UART_RX: U1.40 (GPIO32), U8.7 (UART_RX)
BLE_UART_TX: U1.42 (GPIO33), U8.8 (UART_TX)
BLE_WAKE: U1.21 (GPIO21), U8.6 (P1_6)
CC1_R: J2.A5 (CC1), R9.2
CC2_R: J2.B5 (CC2), R10.2
D0: J3.14, U2.11 (Q0), U7.12 (B7)
D1: J3.13, U2.12 (Q1), U7.13 (B6)
D2: J3.12, U2.13 (Q2), U7.14 (B5)
D3: J3.11, U2.15 (Q3), U7.15 (B4)
D4: J3.10, U2.16 (Q4), U7.16 (B3)
D5: J3.9, U7.17 (B2)
D6: J3.8, U2.18 (Q6), U7.18 (B1)
D7: J3.7, U2.19 (Q7), U7.19 (B0)
DATA0_MCU: U1.18 (GPIO18), U7.9 (A7)
DATA1_MCU: U1.17 (GPIO17), U7.8 (A6)
DATA2_MCU: U1.16 (GPIO16), U7.7 (A5)
DATA3_MCU: U1.44 (GPIO35), U7.6 (A4)
DATA4_MCU: U1.45 (GPIO36), U7.5 (A3)
DATA5_MCU: U1.46 (GPIO37), U7.4 (A2)
DATA6_MCU: U1.47 (GPIO38), U7.3 (A1)
DATA7_MCU: U1.48 (GPIO39), U7.2 (A0)
DME0: J3.6, U3.1 (IO14), U9.19 (IO0)
DVDD: L2.1, U1.10 (DVDD), U1.32 (DVDD), U1.51 (DVDD), U1.65 (VREG_FB)
GND: C1.1, C2.1, C3.1, C4.1, C12.1, C13.1, C14.2, J1.3 (VSS), J1.6 (VSS), J2.A1 (GND), J2.A12 (GND), J2.B1 (GND), J2.B12 (GND), J2.SH (SHIELD), J3.21, J3.40, J5.2, J5.3, J7.7, R9.1, R10.1, SW1.2, U1.62 (VREG_PGND), U1.81 (GND), U2.14 (GND), U3.10 (GND), U4.2 (GND), U5.4 (GND), U7.10 (GND), U7.11 (~OE), U8.2 (GND), U8.13 (GND), U9.10 (GND), U10.2 (GND), U11.10 (GND), U11.11 (~OE), U12.10 (GND), U12.11 (~OE)
GPIO19: TP4.1 (1_1), U1.19 (GPIO19)
GPIO20: TP5.1 (1_1), U1.20 (GPIO20)
GPIO34: TP8.1 (1_1), U1.43 (GPIO34)
GPIO44: TP6.1 (1_1), U1.55 (GPIO44/ADC4)
GPIO45: TP7.1 (1_1), U1.56 (GPIO45/ADC5)
GREENPAK1_SCL: U1.37 (GPIO29), U10.5 (SCL_A)
GREENPAK1_SDA: U1.36 (GPIO28), U10.4 (SDA_A)
GREENPAK2_IO13: R16.2 (B), U9.2 (IO13)
unnamed: TP3.1 (1_1), U9.15 (IO4)
unnamed: TP1.1 (1_1), U9.11 (IO6)
OD: J3.38, U2.22 (~OE), U9.18 (IO1)
PC1500_SENSE: J5.1, U3.2 (IO13)
PU: J3.3, R16.1 (A)
PV: J3.2, U3.4 (IO11), U9.17 (IO2)
QSPI_SCLK: U1.71 (QSPI_SCLK), U5.6 (CLK)
QSPI_SD0: U1.72 (QSPI_SD0), U5.5 (DI/IO_{0})
QSPI_SD1: U1.74 (QSPI_SD1), U5.2 (DO/IO_{1})
QSPI_SD2: U1.73 (QSPI_SD2), U5.3 (~WP/IO_{2})
QSPI_SD3: U1.70 (QSPI_SD3), U5.7 (~HOLD/~RESET/IO_{3})
QSPI_SS: SW1.1, U1.75 (~QSPI_SS), U5.1 (~CS)
RW: J3.39, U3.14 (IO5), U9.14 (IO5)
SCL_GP: J7.1, U3.13 (SCL), U10.8 (SCL_B)
SCL_GP_U9: J7.2, U9.13 (SCL)
SDA_GP: J7.3, U3.12 (SDA), U10.1 (SDA_B)
SDA_GP_U9: J7.4, U9.12 (SDA)
SD_CS: J1.1 (CD/DAT3), R17.2, U1.52 (GPIO41/ADC1)
SD_MISO: J1.7 (DAT0), U1.49 (GPIO40/ADC0)
SD_MOSI: J1.2 (CMD), R18.2, U1.54 (GPIO43/ADC3)
SD_SCK: J1.5 (CLK), U1.53 (GPIO42/ADC2)
SRAM_A13: U2.26 (A13), U3.8 (IO8)
SRAM_A14: U2.1 (A14), U3.6 (IO9)
SRAM_CS: U2.20 (~CS), U3.3 (IO12)
SRAM_WE: U2.27 (~WE), U3.5 (IO10)
SWCLK: J7.5, U1.33 (SWCLK)
SWDIO: J7.6, U1.34 (SWDIO)
TRIG_RD: U1.38 (GPIO30), U9.1 (IO14)
TRIG_WR: U1.39 (GPIO31), U9.9 (IO7)
USB_DM: J2.A6 (D+), J2.B7 (D-), U1.66 (USB_DM)
USB_DP: J2.A7 (D-), J2.B6 (D+), U1.67 (USB_DP)
VBUS: D1.2 (A), D2.2 (A), J2.A4 (VBUS), J2.A9 (VBUS), J2.B4 (VBUS), J2.B9 (VBUS)
VCC: D1.1 (K), J3.1, U4.3 (EN), U7.20 (VCCB), U9.20 (V_{DD}), U11.20 (VCCB), U12.20 (VCCB)
VGG: C1.2, D2.1 (K), J3.20, J5.4, U2.28 (VCC), U3.7 (V_{DD2}), U3.20 (V_{DD}), U4.1 (VIN), U10.7 (VCCB)
VREG_LX: L2.2, U1.63 (VREG_LX)
XIN: C12.2, U1.30 (XIN), X1.1
XOUT: C13.2, R11.2, X1.2
XOUT_MCU: R11.1, U1.31 (XOUT)

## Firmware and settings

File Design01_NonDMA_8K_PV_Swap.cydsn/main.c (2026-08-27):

/* ========================================
 *
 * Copyright YOUR COMPANY, THE YEAR
 * All Rights Reserved
 * UNPUBLISHED, LICENSED SOFTWARE.
 *
 * CONFIDENTIAL AND PROPRIETARY INFORMATION
 * WHICH IS THE PROPERTY OF your company.
 *
 * ========================================
*/
#include "project.h"
#include "FS.h"
#include "PC_EXP.h"
#include <string.h>
#include "rom/rom_image.h"

FS_FILE *currentFile;
uint8 currentFileStatus = EXP_SD_FILE_STATUS_CLOSED;
uint32 fileEnd = 0;
uint8* buff;
char currentFileName[64];

//SDOPEN/SDCLOSE/SDINPUT#/SDPRINT#/SDSKIP#'s own real multi-file state --
//entirely separate from currentFile/currentFileName above (SDLOAD/SDSAVE's
//own single-open-file mechanism); the two don't interact. Index i holds
//channel (i+1). channelName is kept only for EXP_COMMAND_SD_LIST_CHANNELS'
//own display; channelReadPos is the persistent SDINPUT#/SDSKIP# cursor,
//deliberately independent of the file's own internal position (which
//EXP_COMMAND_SD_WRITE_VALUE moves to the end and back on every SDPRINT#
//call). See PC_EXP.h's own comment for the full writeup and the chunk
//format both sides share.
FS_FILE *channelFile[EXP_MAX_SD_CHANNELS];
char channelName[EXP_MAX_SD_CHANNELS][EXP_PATH_ARG_LEN + 1];
uint32 channelReadPos[EXP_MAX_SD_CHANNELS];

void InitBuffer(uint8 rom[32][256])
{
    memset(rom, 0, 32 * 256);
    LoadRomImage(rom);
}

void LongToBuffer(uint8 buffer[16][256], int8 page, int8 start, uint32 value) 
{
    buffer[page][start] = (int)((value >> 24) & 0xFF) ;
    buffer[page][start+1] = (int)((value >> 16) & 0xFF) ;
    buffer[page][start+2] = (int)((value >> 8) & 0XFF);
    buffer[page][start+3] = (int)((value & 0XFF));
}

void StringFromBuffer(uint8 buffer[16][256], uint8 page, uint8 start, uint16 length, char result[])
{
    const uint8* buff = &buffer[page][start];
    for (uint16 i = 0; i < length; i++)
    {
        result[i] = (char)*buff++;
    }
    result[length]=0;
}

void DataFromBuffer(uint8 buffer[16][256], uint8 page, uint8 start, uint16 length, uint8 result[])
{
    const uint8* buff = &buffer[page][start];
    for (uint16 i = 0; i < length; i++)
    {
        result[i] = *buff++;
    }
}

//Right-justifies `value` as ASCII decimal into result[0..width-1], space-
//padded on the left -- e.g. FormatSizeText(6234, buf, 10) -> "      6234".
//Deliberately done here (MCU-side), not on the LH5801: the ROM has no
//binary-to-decimal routine of its own, and there's no need to invent one
//when this side can trivially render display-ready text instead of a raw
//number (see PC_EXP.h's EXP_DIR_SIZE_TEXT_LEN comment).
void FormatSizeText(uint32 value, uint8 result[], uint8 width)
{
    uint8 i;
    for (i = 0; i < width; i++)
        result[i] = ' ';
    i = width;
    do
    {
        i--;
        result[i] = (uint8)('0' + (value % 10));
        value /= 10;
    } while (value != 0 && i > 0);
}

//Writes `value` as left-justified ASCII decimal (no padding) starting at
//result[0]; returns the digit count written. `result` must have room for
//at least 10 bytes (uint32's max digit count) -- callers here always pass
//into a generously-sized scratch buffer, not directly into a fixed-width
//wire-format field.
uint8 WriteDecimal(uint32 value, uint8 result[])
{
    uint8 buf[10];
    uint8 n = 0;
    uint8 i;
    if (value == 0)
    {
        result[0] = '0';
        return 1;
    }
    while (value != 0)
    {
        buf[n++] = (uint8)('0' + (value % 10));
        value /= 10;
    }
    for (i = 0; i < n; i++)
        result[i] = buf[n - 1 - i];
    return n;
}

//This project's own SD-path convention (SDCD/SDMKDIR/SDRMDIR/SDPWD) is a
//single '/' separator, no volume-name prefix, and exactly "/" at the SD
//root -- '/' specifically because it's an unshifted key on the real
//PC-1500 keyboard, easy for a user to actually type. emFile's own paths
//look like "PC1500:\SUBDIR" (backslash-separated, volume-prefixed); these
//two helpers convert between the two conventions at the boundary, so nothing
//above the DoCommand() switch (or the ROM side, which just blits whatever
//text comes back) ever needs to know emFile's own convention exists.
void NormalizeSdPathFromFs(const char* raw, char* out, uint8 outSize)
{
    const char* colon = strchr(raw, ':');
    const char* src = colon ? colon + 1 : raw;
    uint8 n = 0;
    out[n++] = '/';
    for (; *src != 0 && n < outSize - 1; src++)
    {
        char c = (*src == '\\') ? '/' : *src;
        //Avoid a doubled leading slash: after stripping the volume prefix,
        //emFile's own root is just "\" (or empty), which would otherwise
        //normalize to a second '/' right after the one already placed above.
        if (n == 1 && c == '/') continue;
        out[n++] = c;
    }
    out[n] = 0;
}

//Converts a '/'-separated path (as typed by the user, e.g. via SDCD) to
//emFile's own native '\' convention, in place, before handing it to
//FS_ChDir/etc.
void ConvertSdPathToFsSeparators(char* path)
{
    for (; *path != 0; path++)
        if (*path == '/') *path = '\\';
}

//This project's own SD-name convention also swaps '+' for a real short
//FAT name's '~' -- the PC-1500 keyboard has a '+' key but no '~' key, and
//a card prepared on a normal PC (long filenames) and then read by this
//firmware's NLFN emFile build shows its auto-generated short names, which
//often contain a literal '~' (e.g. "MYAPPL~1.BAS"). Every SD command now
//enforces uppercase 8.3 shape on its own argument (see rom.asm's
//SD_PARSE_QUOTED_NAME), so '+' can never legitimately appear in a name for
//any other reason -- the swap is unconditional and unambiguous in both
//directions (unlike '-', which is a legal FAT 8.3 character and could
//collide with a real hyphenated name). Apply ConvertPlusToTilde to any
//name arriving from the PC-1500 before it touches the real filesystem
//(lookups *and* creates -- typing "APPL+1.BAS" to SDSAVE deliberately
//creates a file literally named "APPL~1.BAS"), and ConvertTildeToPlus to
//any real on-disk name before it's shown back to the PC-1500.
void ConvertPlusToTilde(char* name)
{
    for (; *name != 0; name++)
        if (*name == '+') *name = '~';
}

void ConvertTildeToPlus(char* name)
{
    for (; *name != 0; name++)
        if (*name == '~') *name = '+';
}

//Every SD command's name argument is a full path now (a plain filename, a
//relative path with '.'/'..'/multiple components, or an absolute one
//starting with '/' from the SD root) -- rom.asm's SD_PARSE_QUOTED_NAME
//already validates 8.3 shape per '/'-segment regardless of what the
//argument is actually used for. PrepareFsName is the one place that
//converts a raw typed argument into the exact string an FS_* call needs:
//'+'->'~' (see ConvertPlusToTilde's own comment) and '/'->'\\' (see
//ConvertSdPathToFsSeparators's own comment). A leading '\\' with no
//volume prefix is passed straight through to FS_ChDir/FS_FOpen/etc.,
//relying on emFile's own path parser to treat it as "from the SD root" --
//the same assumption CHANGE_SD_DIR's own FS_ChDir call already made
//(confirmed live for SDCD; not independently re-verified for every other
//FS_* function here, but there is no reason emFile would parse the same
//syntax differently depending on which function receives it).
//`raw` and `out` may safely be different buffers only -- write into a
//buffer separate from wherever the original (unconverted, for later
//redisplay) argument is kept.
void PrepareFsName(const char* raw, char* out, uint8 outSize)
{
    strncpy(out, raw, outSize - 1);
    out[outSize - 1] = 0;
    ConvertPlusToTilde(out);
    ConvertSdPathToFsSeparators(out);
}

//Returns a pointer into `path` at its last '/' or '\\' component (or
//`path` itself if there's none) -- the plain filename a full path ends
//with. Used to get SDCP/SDMV's source basename for ResolveCopyOrMove
//Destination below. Works on the raw ('+'-preserved, '/'-separated)
//argument -- checking both separators means it also works if called
//after PrepareFsName has already converted it, though nothing here does
//that.
const char* GetBasename(const char* path)
{
    const char* base = path;
    for (const char* p = path; *p != 0; p++)
        if (*p == '/' || *p == '\\') base = p + 1;
    return base;
}

//SDCP/SDMV's destination resolution: if destArg (after PrepareFsName)
//refers to an *existing directory*, the real target is that directory
//plus the source's own basename, matching Unix cp/mv's own "copy/move
//INTO a directory" behavior; otherwise destArg itself (converted) is the
//target. `out` must be able to hold the longest possible result:
//EXP_PATH_ARG_LEN (converted destArg) + 1 ('\\' separator) + up to a
//12-character 8.3 basename + a null terminator.
void ResolveCopyOrMoveDestination(const char* srcBasename, const char* destArg, char* out,
                                   uint8 outSize)
{
    char converted[EXP_PATH_ARG_LEN + 1];
    PrepareFsName(destArg, converted, sizeof(converted));
    if (FS_GetFileAttributes(converted) & FS_ATTR_DIRECTORY)
    {
        uint8 n = 0;
        for (; converted[n] != 0 && n < outSize - 1; n++) out[n] = converted[n];
        if (n > 0 && out[n-1] != '\\' && n < outSize - 1) out[n++] = '\\';
        uint8 i = 0;
        while (srcBasename[i] != 0 && n < outSize - 1) out[n++] = srcBasename[i++];
        out[n] = 0;
    }
    else
    {
        strncpy(out, converted, outSize - 1);
        out[outSize - 1] = 0;
    }
}

//Writes "<count> FILES <totalBytes>B <freeBytes>F" left-justified into
//result[0..width-1], space-padded/truncated to width -- e.g. "3 FILES
//23051B 2122343F". Mirrors pc1500emu's ExpansionMock::listSdDir summary
//line exactly (kept in sync by hand); see PC_EXP.h's EXP_DIR_SUMMARY_LEN
//comment. Built in a generously-sized local buffer first so a longer
//listing/volume just truncates safely instead of overflowing `result`.
void FormatSummaryLine(uint16 count, uint32 totalBytes, uint32 freeBytes, uint8 result[],
                        uint8 width)
{
    char temp[48];
    uint8 pos = 0;
    uint8 i;
    pos = (uint8)(pos + WriteDecimal(count, (uint8*)(temp + pos)));
    temp[pos++] = ' '; temp[pos++] = 'F'; temp[pos++] = 'I'; temp[pos++] = 'L';
    temp[pos++] = 'E'; temp[pos++] = 'S'; temp[pos++] = ' ';
    pos = (uint8)(pos + WriteDecimal(totalBytes, (uint8*)(temp + pos)));
    temp[pos++] = 'B'; temp[pos++] = ' ';
    pos = (uint8)(pos + WriteDecimal(freeBytes, (uint8*)(temp + pos)));
    temp[pos++] = 'F';
    for (i = 0; i < width; i++)
        result[i] = (i < pos) ? (uint8)temp[i] : ' ';
}

void WriteStatus(uint8 buffer[16][256], uint8 status)
{
    buffer[EXP_INSTRUCTION_PAGE][EXP_INSTRUCTION_ADDRESS] = status;
}    

void DoCommand(uint8 req, uint8 buffer[16][256]) __attribute__((noinline));
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
int main(void)
{
    //Set busy status until we're done with init
    Pin_Data_DR = EXP_STATUS_BUSY;
    
    uint8 laddress = 0;
    uint8 page = 0;
    uint8 buffer[32][256];
    uint8 data_read;
    uint8 rwpin;
    
    InitBuffer(buffer);

    CyGlobalIntEnable; /* Enable global interrupts. */
    
    FS_Init();
    FS_X_AddDevices();
    
    for(;;)
    {        
        if (Status_CS_Read())
        {
            laddress = Pin_Address_Low_PS;
            page = Status_Page_Status;
            data_read = Pin_Data_PS;
            
            //It's always safe to do this, because strong drive of the data
            //pins is enabled by CS and `OD
            Pin_Data_DR = buffer[page][laddress];

            //Sometimes R/W will already be low when we get here
            if (!(rwpin = Status_RW_Status))
            {    
                if (page == EXP_INSTRUCTION_PAGE && laddress == EXP_INSTRUCTION_ADDRESS) 
                {
                    DoCommand(data_read, buffer);
                }
                else
                    buffer[page][laddress] = data_read;
            }
            else 
            {
                //Try to wait in case RW goes low later
                while (page == Status_Page_Status && Pin_Address_Low_PS == laddress && (rwpin = Status_RW_Status)) 
                {
                }
                if (!rwpin)
                {
                    if (page == EXP_INSTRUCTION_PAGE && laddress == EXP_INSTRUCTION_ADDRESS) 
                    {
                        DoCommand(data_read, buffer);
                    }
                    else 
                        buffer[page][laddress] = data_read;
                }
            }                        
        }
    }        
}


/* [] END OF FILE */

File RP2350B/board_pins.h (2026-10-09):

/* Copyright (c) 2026 Paul Chambre. Licensed under the Apache License,
 * Version 2.0 -- see LICENSE.
 */
/* board_pins.h
 *
 * GPIO assignment for the RP2350B expansion board redesign (bare RP2350B
 * "core dev board", not the Pico 2 W module -- see ../RP2350/ for that
 * earlier, superseded design). Re-derived 2026-09-08 directly from the
 * KiCad PCB's own per-pad `pinfunction` fields (authoritative -- these
 * come straight from the RP2350B symbol's pin data, not from manual
 * pin-number bookkeeping) at
 * C:\Users\paulc\Documents\PSoC Creator\PC1500-PSOC5\PC1500-RP2350B-BLE.
 * The previous version of this file described an intended-but-never-
 * fully-realized layout (fully contiguous data bus, GPIO21/22 for the
 * trigger lines) that did not match the actual wiring -- this version
 * reflects verified, current reality, bugs included (see below).
 *
 * The bare RP2350B exposes all 48 GPIOs; this design uses 35 of them.
 *
 * GPIO0-12 = AD0-AD12 (address bus) is a direct bit alignment: GPIO*n* =
 * AD*n*, so firmware reads the whole 13-bit address with zero shifting
 * (`gpio_in & ADDR_PIN_MASK`), and it fits inside a single 32-bit
 * GPIO_IN register read. Confirmed pin-by-pin against the schematic
 * 2026-09-08, including catching and fixing a real bug where AD4_MCU/
 * AD6_MCU's net labels sat 2.54mm short of GPIO4/GPIO6's actual pin
 * position with no wire between them -- those two address bits were
 * silently unconnected until that fix.
 *
 * The data bus is NOT contiguous, unlike an earlier planned layout:
 * D0-D2 live at GPIO16-18 (in reverse order -- GPIO18=D0, GPIO17=D1,
 * GPIO16=D2), while D3-D7 are separately at GPIO35-39 (in-order, ascending).
 * Firmware must read/assemble the byte from two register groups.
 *
 * Re-derived again 2026-09-10: U7 (the FXMA108 level shifter between this
 * chip and the PC-1500's D0-D7) has each channel's PC-1500-side pin wired
 * to D_(7-channel), not D_channel -- a real, since-corrected schematic bug
 * (channel 0's A-side pin was floating outright; channels 1-7 were each
 * bridged to the WRONG PC-1500 bit). The fix keeps every already-routed
 * U1<->U7 physical connection untouched (that side was already non-crossing)
 * and instead renames which DATA_k_MCU net sits on which channel, so this
 * file's bit assignment flipped (old D0..D7 GPIOs are now this file's
 * D7..D0) relative to any version of this file from before 2026-09-10.
 *
 * KNOWN BUG, not yet fixed in hardware: SD_MISO is wired to GPIO27, a
 * plain GPIO with no SPI1 capability, while GPIO40 (the real SPI1 RX/
 * MISO funcsel pin, and the pin CS/SCK/MOSI below correctly assume) is
 * left unconnected. As wired, the SD card cannot use hardware SPI1 for
 * reads -- either bit-bang MISO on GPIO27, or fix the schematic to move
 * SD_MISO to GPIO40 (a real fix, not a relabel -- ask before assuming
 * which). PIN_SD_MISO below reflects actual wiring (27), not the
 * design intent (40).
 *
 * GreenPAK1 (U3) I2C runs through U10 (TCA9406, a 2-bit I2C level
 * translator) between U1's GPIO28/29 (3.3V side) and the shared VGG-side
 * I2C bus (SDA_GP/SCL_GP) that GreenPAK1's GREENPAK1_SDA/SCL are always
 * hard-wired to -- bit-banged on the RP2350B side, not a hardware I2C
 * peripheral (see greenpak_i2c.h). (Moved from GPIO23/24 to GPIO28/29 in
 * the 2026-09-08 pin-swap pass -- physically closer to U10, see the
 * spare-pin list at the bottom of this file for the full rationale.)
 *
 * GreenPAK2 (U9) shares that SAME bus -- there is no separate
 * PIN_GREENPAK2_SDA/SCL, GPIO28/29 talk to both chips -- but only when
 * two shunt jumpers are installed on J7 (pins 1-2 bridge SCL_GP to
 * GreenPAK2's own SCL_GP_U9; pins 3-4 do the same for SDA). Removing
 * those jumpers deliberately isolates GreenPAK2 from the bus so
 * GreenPAK1's slave address can be reprogrammed without GreenPAK2 also
 * responding/conflicting. Firmware talking to GreenPAK2 over I2C must
 * not assume it's reachable unconditionally -- whoever operates the
 * board controls that via the physical jumpers, not firmware.
 */
#pragma once

/* ---- LH5801-facing bus: 13-bit flat address, 8K window (0x8000-0x9FFF).
 * GPIO*n* = AD*n* for n=0..12, contiguous, verified pin-by-pin 2026-09-08. ---- */
#define PIN_A0  0
#define PIN_A1  1
#define PIN_A2  2
#define PIN_A3  3
#define PIN_A4  4
#define PIN_A5  5
#define PIN_A6  6
#define PIN_A7  7
#define PIN_A8  8
#define PIN_A9  9
#define PIN_A10 10
#define PIN_A11 11
#define PIN_A12 12
#define ADDR_PIN_BASE  PIN_A0   /* A0..A12 are contiguous -- read as one 13-bit field */
#define ADDR_PIN_COUNT 13
#define ADDR_PIN_MASK  ((1u << ADDR_PIN_COUNT) - 1u)
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

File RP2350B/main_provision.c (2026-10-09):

/* Copyright (c) 2026 Paul Chambre. Licensed under the Apache License,
 * Version 2.0 -- see LICENSE.
 */
/* main_provision.c -- GreenPAK NVM provisioning tool. Separate firmware
 * image from this board's normal main.c/monitor.c -- flash this
 * deliberately to program GP1/GP2's NVM, then flash the normal
 * firmware back for actual expansion-board operation.
 *
 * Workflow (see ../DESIGN_DECISIONS.md for full background). Every run
 * checks the TARGET addresses (0x18 GP1, 0x10 GP2) first, not the
 * factory-default address -- this is what lets a re-run safely
 * reprogram already-provisioned chips instead of just idling, and lets
 * "nothing done yet" be told apart from "one done, one pending"
 * regardless of jumper state:
 *   1. Both GP1 (0x18) and GP2 (0x10) already respond -- reprograms
 *      both in place (each chip stays at its own address throughout).
 *   2. Neither responds -- if a chip answers at the factory default
 *      (0x08), programs it as GP1. (With GP2's isolation jumper
 *      disconnected, only GP1 is on the bus, so this is naturally
 *      GP1's first run.)
 *   3. GP1 responds but GP2 doesn't -- if a second chip answers at the
 *      default address, programs it as GP2. (Reconnect GP2's isolation
 *      jumper before this run.)
 *   4. GP2 responds but GP1 doesn't -- symmetric fallback, programs a
 *      default-address chip as GP1.
 *   5. If nothing answers at any known address, drops into recovery
 *      mode: scans the full 7-bit address range and reports findings.
 *      Recovery mode never reprograms anything unless this firmware
 *      was built with -DGREENPAK_NVM_ALLOW_RECOVERY_WRITE=1 (a
 *      deliberately different build/flash, not a runtime prompt).
 *
 * All real writes are gated by GREENPAK_NVM_DRY_RUN (default 1 --
 * override via -DGREENPAK_NVM_DRY_RUN=0 to actually program a chip).
 * In dry-run mode, program_image() only reads back and reports
 * existing NVM content -- zero write risk.
 */
#include <stdio.h>
#include "pico/stdlib.h"
#include "pico/stdio_usb.h"

#include "board_pins.h"
#include "greenpak_i2c.h"
#include "greenpak_nvm.h"
#include "gp1_nvm_image.h"
#include "gp2_nvm_image.h"

#ifndef GREENPAK_NVM_DRY_RUN
#define GREENPAK_NVM_DRY_RUN 1
#endif

#ifndef GREENPAK_NVM_ALLOW_RECOVERY_WRITE
#define GREENPAK_NVM_ALLOW_RECOVERY_WRITE 0
#endif

#define GP1_CONTROL_CODE 0x3 /* GP1-SRAM.gp6's compiled control code -- confirmed against real hardware in GreenPakTester */
#define GP2_CONTROL_CODE 0x2 /* GP2-MCU.gp6's compiled control code -- confirmed against real hardware in GreenPakTester (10/10 self-test vectors passing) */

static greenpak_i2c_bus_t g_bus;

static void wait_for_usb_terminal(void) {
    for (int waited_ms = 0; !stdio_usb_connected() && waited_ms < 10000; waited_ms += 100) {
        sleep_ms(100);
    }
    sleep_ms(200);
}

static void report_page(const char *label, uint8_t control_code, bool ok) {
    printf("  %s: control_code=0x%X reg_addr=0x%02X nvm_addr=0x%02X %s\n",
           label, control_code,
           greenpak_nvm_reg_addr(control_code), greenpak_nvm_nvm_addr(control_code),
           ok ? "OK" : "FAIL");
}

/* `current_cc` is the control code the chip is ACTUALLY answering at
 * right now -- erase/write/read-back/reset_and_reload all target this
 * address, since that's the only address the chip currently listens
 * on. `target_cc` is what it should become after this image's reload
 * (equal to current_cc for an in-place reprogram of an already-
 * provisioned chip; the factory default for a fresh chip's first
 * programming, since the desired final control code is baked into the
 * image itself, not set separately). When they differ, this also
 * re-probes `target_cc`'s address afterward as a real end-to-end check
 * that the chip actually moved, not just that the I2C writes ACKed. */
static bool program_or_report(const char *label, uint8_t current_cc, uint8_t target_cc,
                               const uint8_t *image, uint32_t image_len) {
    if (image_len != GREENPAK_NVM_IMAGE_SIZE) {
        printf("  %s: image size mismatch (%u, expected %u) -- refusing\n",
               label, (unsigned)image_len, (unsigned)GREENPAK_NVM_IMAGE_SIZE);
        return false;
    }
    printf("  %s: %s image (chip currently at 0x%02X, target 0x%02X)...\n", label,
           GREENPAK_NVM_DRY_RUN ? "[DRY RUN] reading back (not writing)" : "programming",
           greenpak_nvm_reg_addr(current_cc), greenpak_nvm_reg_addr(target_cc));
    bool ok = greenpak_nvm_program_image(&g_bus, current_cc, image, GREENPAK_NVM_DRY_RUN);
    report_page(label, current_cc, ok);

    if (ok && !GREENPAK_NVM_DRY_RUN && current_cc != target_cc) {
        sleep_ms(50); /* allow real POR startup time after reset_and_reload -- not datasheet-confirmed exact, a conservative margin above the documented <=20ms self-timed cycles */
        bool moved = greenpak_nvm_probe(&g_bus, greenpak_nvm_reg_addr(target_cc));
        printf("  %s: post-program check at target 0x%02X: %s\n",
               label, greenpak_nvm_reg_addr(target_cc), moved ? "ACK (moved OK)" : "no ACK (FAILED to move!)");
        ok = ok && moved;
    }
    return ok;
}

static void recovery_scan(void) {
    printf("Recovery mode: scanning I2C addresses 0x08-0x77...\n");
    for (uint8_t addr = 0x08; addr <= 0x77; addr++) {
        if (greenpak_nvm_probe(&g_bus, addr)) {
            uint8_t control_code = addr >> 3;
            uint8_t block = addr & 0x7;
            printf("  0x%02X ACKs (control_code=0x%X, block=0b%d%d%d)\n",
                   addr, control_code,
                   (block >> 2) & 1, (block >> 1) & 1, block & 1);
        }
    }
    printf("Recovery scan complete.\n");

#if GREENPAK_NVM_ALLOW_RECOVERY_WRITE
    printf("This build allows recovery writes, but no automatic action is\n"
           "taken -- recovery reprogramming isn't implemented as an\n"
           "unattended step; re-run normal provisioning once you've\n"
           "identified which chip/address needs attention.\n");
#else
    printf("This build does not allow recovery writes (default). Rebuild\n"
           "with -DGREENPAK_NVM_ALLOW_RECOVERY_WRITE=1 if reprogramming a\n"
           "chip found here is really intended.\n");
#endif
}
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

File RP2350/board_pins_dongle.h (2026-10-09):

/* board_pins_dongle.h (included through board_pins.h)
 *
 * GPIO assignment for the RP2350 (Pico 2 W) PC1500-Pico2W-Dongle board --
 * NOT the RP2354B internal card, whose layout is board_pins_card.h
 * (PC1500_TARGET=card, 2026-10-09).
 *
 * Confirmed 2026-09-16 against PC1500-Pico2W-Dongle.kicad_sch's own
 * netlist (U1, the Pico 2 W module socket) -- read directly from the
 * schematic, not inferred -- after this table's earlier, unbuilt/
 * theoretical version turned out to disagree with the real board in
 * several places at once (see the git history around this date for the
 * full incident: those disagreements are what was actively breaking the
 * PC-1500's own boot cycle whenever the Pico was present). Every pin
 * below is schematic ground truth for this board specifically.
 *
 * GreenPAK glue logic (external to the RP2350) does SRAM chip-select,
 * MCU chip-select, and combines CS+R/W+OE into the two trigger lines
 * below -- none of that logic has RP2350 GPIOs of its own; only its two
 * trigger outputs and the I2C link are wired to this chip.
 */
#pragma once

/* ---- LH5801-facing bus: 13-bit flat address, 8K window (0x8000-0x9FFF) ---- */
#define PIN_A0  0
#define PIN_A1  1
#define PIN_A2  2
#define PIN_A3  3
#define PIN_A4  4
#define PIN_A5  5
#define PIN_A6  6
#define PIN_A7  7
#define PIN_A8  8
#define PIN_A9  9
#define PIN_A10 10
#define PIN_A11 11
#define PIN_A12 12
#define ADDR_PIN_BASE  PIN_A0   /* A0..A12 are contiguous -- read as one 13-bit field */
#define ADDR_PIN_COUNT 13
#define ADDR_PIN_MASK  ((1u << ADDR_PIN_COUNT) - 1u)

/* ---- Data bus D0-D7: GP13-GP20, one contiguous 8-bit field, wired
 * directly to the LH5801-side bus -- schematic nets D0_LV..D7_LV (U6, a
 * TXS0108E level shifter formerly in this path, has been physically
 * removed from the board; see SetupReadServePio()/SetupWriteServePio()'s
 * own comments in monitor.c). NOT split around GPIO19 -- an earlier, unbuilt
 * version of this table assumed GPIO19 was reserved for a QMI-CS1 SD
 * card chip-select and routed D6/D7 around it onto GP20/21 instead; on
 * the real board GPIO19 is simply D6, GPIO21 is TRIG_RD (see below), and
 * the SD card isn't wired to RP2350 GPIO/QMI at all (see PIN_SD note
 * below) -- that earlier assumption had the firmware hijacking a live
 * data-bus line for QMI/XIP duty on every boot, and driving an output
 * onto TRIG_RD (an input the GreenPAK itself drives) every time a read
 * looked like it needed bit 7. ---- */
#define PIN_D0 13
#define PIN_D1 14
#define PIN_D2 15
#define PIN_D3 16
#define PIN_D4 17
#define PIN_D5 18
#define PIN_D6 19
#define PIN_D7 20
#define DATA_PIN_BASE  PIN_D0
#define DATA_PIN_COUNT 8

/* ---- GreenPAK trigger lines: combine CS+R+OE ("read requested, drive
 * data now") and CS+W ("write requested, latch data now") into two
 * unambiguous edges -- firmware no longer computes CS&&RW&&OE itself.
 * These double as POWMAN wake sources (PWRUP0/PWRUP1); no separate wake
 * pin is used. Schematic nets TRIG_RD_PICO/TRIG_WR_PICO -- swapped from
 * this table's earlier (22/26) assumption; GP26 in particular is really
 * the GreenPAK I2C SDA line below, which idles high (pulled up), so the
 * old PIN_TRIG_WR=26 made the bus loop's write-trigger wait spin forever
 * against an idle I2C bus instead of a real write cycle. ---- */
#define PIN_TRIG_RD 21  /* CS && Read && OE asserted by the GreenPAK -- drive data bus now */
#define PIN_TRIG_WR 22  /* CS && Write asserted by the GreenPAK -- latch data bus now */

/* ---- I2C-style link to the GreenPAK(s): general comms plus the
 * Control_Mode_Control-equivalent ROM-source mux select (SRAM vs MCU for
 * the 6K ROM window) that the PSoC5 design drove as a dedicated pin.
 * GreenPAK1 and GreenPAK2 share this one physical bus -- there is no
 * separate PIN_GREENPAK2_SDA/SCL wiring, matching RP2350B/board_pins.h's
 * same convention; the two chips are distinguished by I2C slave address
 * (each chip's NVM-configured control code), not by pin.
 *
 * GP26/GP27, NOT GP27/GP28 -- overridden from this file's original
 * (unbuilt, theoretical) 27/28 assignment to match the actual fabricated
 * PC1500-Pico2W-Dongle board: confirmed 2026-09-14 via
 * PC1500-Pico2W-Dongle.kicad_sch's netlist, U1 (the Pico 2 W module
 * socket) physical pin 31 -> net "SDA" (=GP26) and pin 32 -> net "SCL"
 * (=GP27) through U8 (TCA9406DC level shifter) to the GreenPAKs. This
 * was the root cause of a full-range (0x08-0x77) I2C recovery scan
 * finding nothing on real hardware: firmware was bit-banging GP27/GP28,
 * where GP27 is really the board's SCL line and GP28 is unconnected --
 * the real SDA line (GP26) was never toggled at all. ---- */
#define PIN_GREENPAK1_SDA 26
#define PIN_GREENPAK1_SCL 27
#define PIN_GREENPAK2_SDA PIN_GREENPAK1_SDA
#define PIN_GREENPAK2_SCL PIN_GREENPAK1_SCL
#define GREENPAK_I2C_INSTANCE i2c1  /* GP26/GP27 are I2C1's SDA/SCL */
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

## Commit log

2026-08-18 Add SD directory commands, path/listing conventions, and 8.3 name enforcement
    - SDCD/SDMKDIR/SDRMDIR/SDPWD: real implementations (was stubs), backed by
    emFile's single global current-directory concept.
    - Standardize '/' as the SD path separator (converted to/from emFile's
    native '\' at the main.c boundary) and list subdirectories in SDLS with
    <DIR>.
    - Enforce uppercase 8.3 shape on every SD command's quoted name (this
    project's emFile build is the No-Long-File-Name variant, so real names
    are genuine FAT short names); a violation raises ERROR 1 on
    SDCD/SDMKDIR/SDRMDIR/SDSAVE, matching the existing malformed-name
    convention, while SDLOAD keeps its own silent-abort behavior.
    - Add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
    [PC_EXP.h, main.c]
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2026-08-18 Add SDOPEN/SDCLOSE/SDINPUT#/SDPRINT#/SDSKIP# variable-channel SD commands
    Up to 16 SD files open at once, numbered 1-16, addressed by variable name
    rather than byte offset or file handle -- a simplified, Apple-BASIC-style
    analogue of the CE-150's own PRINT#/INPUT#. rom.asm resolves each named
    BASIC variable's real RAM address via the base ROM's D461H "variable
    address search" system subroutine and builds/consumes a self-describing
    value chunk directly from that address; main.c stays completely blind to
    BASIC variables, only moving opaque chunk bytes tagged with a channel
    number. Numeric and string round trips, EOF zero/blank-fill, and
    skip-past-end (ERROR 40) all confirmed via both an in-pro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
    [PC_EXP.h, main.c]
2026-08-18 Move expansion ROM to 0x8800 (6K ROM/2K data) and fix a real D461H bug
    Grows the keyword-table ROM region from 4K to 6K (data window shrinks
    4K->2K correspondingly) as the table filled up. Requires updating every
    keyword's own dispatch code (0xE2xx->0xE1xx, page-index-dependent) --
    missing this would leave keywords tokenizing fine but silently failing
    to execute. EXP_DIR_MAX_ENTRIES recomputed (135->67) for the smaller
    data window; rom_9000.bin renamed to rom_8800.bin throughout.
    Also moves SD_PARSE_QUOTED_NAME's inline uppercase-fold/8.3-shape
    validation off the ROM into a new EXP_COMMAND_VALIDATE_SD_NAME wire
    command (main.c), since it was pure character classification -- rom.asm
    now only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
    [PC_EXP.h, main.c]
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2026-09-10 Document RP2350 5V-tolerance research for dropping the FXMA108 level shifters
    Captures the datasheet absolute-max-ratings analysis, the A2/A4 stepping
    question, community evidence (One ROM precedent vs. an unconfirmed
    gusmanb/logicanalyzer chip-damage report), and this board's specific
    power-sequencing case: AP2112K-3.3 EN tied directly to VCC with VIN
    pre-charged from the always-on VGG rail, giving ~100x margin against the
    LH5801's documented 2ms reset hold. Not yet bench-verified or acted on.
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2026-09-18 Checkpoint RP2350 dongle firmware before PIO-driven bus rewrite
    Captures the current, real-hardware-validated state of the Pico 2 W
    dongle firmware and its ROM-side counterpart before starting a rewrite
    of the read-trigger path to use PIO+DMA instead of software polling:
    dual-core split (core0 bus loop / core1 SD command worker), the
    level-shifter power-up warm-up transaction, the data-pin pulldown
    (confirmed load-bearing), the wireless/SMPS-PWM init (confirmed
    load-bearing), the GreenPAK I2C bridge and SD driver sources, and the
    ROM-side EC_WAIT_NOT_BUSY/DOSTUFF/keyword additions. Extensive real-
    hardware debugging this session found and fixed several genuine board
    faults (stuck data bit, m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
    [PC_EXP.h, board_pins.h, diskio_sd_bridge.c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]
2026-09-18 Fix RP2350 PIO read-trigger path: edge-gate address capture, IRQ-synchronize the two state machines
    Real-hardware-validated fix for the PIO+DMA read-trigger rewrite (staged
    in the prior checkpoint, d999fa0): PEEK on the real PC-1500 was returning
    garbage/zero regardless of address, and repeated ECVER runs eventually
    locked the machine.
    Root cause 1: addr_capture sampled the LH5801's 13-bit address bus
    continuously and unconditionally, but that bus is shared across the
    whole machine's memory map, not exclusive to this board's 8K window --
    so it picked up unrelated CPU traffic just as eagerly as genuine
    accesses, permanently filling the downstream DMA relay + read_serve's
    TX FIFO with address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
    [monitor.c]
2026-09-18 Add RP2350 PIO write-trigger path: ordinary writes + command dispatch
    Ports the write-trigger side of the LH5801 bus protocol to PIO+DMA
    hardware, following the read-trigger fix's own edge-gated,
    IRQ-synchronized approach (commit d829046) and using OneROM's pioram.c
    write-side design as the primary reference (fetched and read in full,
    adapted for this board's simpler two-signal GreenPAK-combined
    trigger lines).
    Four new state machines on pio1 (left entirely separate from pio0's
    already-validated read path): trigger_detect_wr is the sole observer of
    PIN_TRIG_WR; addr_capture_wr captures the live address and branches on
    whether it's the EXP_INSTRUCTION_PAGE/ADDRESS dispatch cell (flat offset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
    [monitor.c]
2026-09-20 Add repo-level DESIGN_DECISIONS.md, fix dangling doc reference, correct OneROM chip claim
    DESIGN_DECISIONS.md replaces an earlier version that existed at some
    point (referenced by "repo-level plan doc" comments in both copies of
    main_provision.c) but was never committed and has been lost. Captures:
    why 4.7V is the PC-1500's native Vcc/Vgg rail, the GreenPAK dual-chip
    provisioning workflow (GP1/GP2 factory-default address collision +
    sequential programming), the dongle's SDA1/SCL1 isolation jumpers, and
    this session's new I2C pull-up values (R11-R14).
    GreenPak_Provision/main_provision.c: point the "repo-level plan doc"
    comment at the new file instead of nowhere.
    no_level_shifters_investigat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
    [main_provision.c]
2026-09-20 Pico2W-Dongle-no-level-shifters: I2C pull-ups, cap fixes, SDA1/SCL1 rename, hand-routing
    Schematic: R11-R14 I2C pull-up resistors (2K on VGG for SDA_GP/SCL_GP,
    1.5K on 3V3 for SDA/SCL), C1/C2/C6/C7/C8 capacitor connections fixed
    (were fully or partially unwired), JP1/JP2 renamed to SDA1/SCL1 to
    match user's PCB-side silkscreen relabeling.
    PCB: C1/C2/C6 net assignments patched to match; SDA1/SCL1 footprint
    references renamed to match; user's manual routing/silkscreen fixes.
    Known state: 0 unconnected nets, but 100 DRC violations remain (mostly
    track_width squeeze escaping fine-pitch GreenPAK/SD-bridge pins, plus
    some clearance/silk) -- not yet fab-clean, captured here as a checkpoint.
    [PC1500-Pico2W-Dongle.kicad_pcb, PC1500-Pico2W-Dongle.kicad_sch]
2026-09-21 Fix microSD pin 6 (GND) and pin 1 (unused, needs pull-up) on all 4 boards
    Pin 6 and pin 3 were coincident in the generic SD_Card_Device symbol,
    forcing GND onto the same net as CMD/MOSI. Relocated pin 6's local
    coordinate and gave it its own wire+label on all four schematics
    (RP2350B-BLE and Pico2W-Dongle, each with and without level shifters).
    Pin 1 (symbol name CD/DAT3) is unused in this design but needs a 10K
    pull-up to 3.3V rather than being left floating, matching the existing
    SD_CS/SD_MOSI/SD_DAT1/SD_DAT2 pull-up pattern. Added the missing
    wire+label+resistor to the three boards that lacked it
    (Pico2W-Dongle-no-level-shifters already had it via R10).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
    [PC1500-Pico2W-Dongle.kicad_sch, PC1500-RP2350B-BLE.kicad_sch]
2026-09-21 Fix J2 pin 6->GND copper on Pico2W-Dongle-no-level-shifters, export fab files
    Pad 6 was still physically bridged in copper to pad 3 (SD_MOSI) despite
    the earlier schematic fix; user reworked the PCB to route it to GND
    directly. Also re-grounded the 4 shield pads, which lost their GND net
    assignment again during the schematic sync (recurring issue since they
    have no corresponding schematic pin).
    Regenerated Gerbers (Protel extensions + job file), drill files, BOM,
    and component placement file for this board. The CPL was rebuilt with
    JLCPCB's expected header (Designator,Mid X,Mid Y,Layer,Rotation instead
    of KiCad's default Ref,Val,Package,PosX,PosY,Rot,Side) and normalized
    rotations to 0-360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
    [PC1500-Pico2W-Dongle-B_Cu.gbl, PC1500-Pico2W-Dongle-B_Mask.gbs, PC1500-Pico2W-Dongle-B_Paste.gbp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]
2026-09-21 Swap discontinued AP1117-ADJ for NCP1117-ADJ, clean up part names for BOM/CPL
    AP1117-ADJ (U7, both Pico2W-Dongle variants) is discontinued; KiCad's own
    library even flags it obsolete. Swapped to NCP1117-ADJ_SOT223, a
    pin-compatible drop-in (same SOT-223 footprint, same graphics via the
    library's "extends" relationship) - no rewiring needed. Had to embed the
    new symbol into each schematic's symbol cache too, since just changing
    the instance lib_id left it unresolvable and silently dropped from the
    netlist/BOM.
    Replaced dashes and underscores with spaces in all instance-level part
    Values across both dongle boards, and in the no-level-shifters board's
    exported BOM Footprint column and resistor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
    [PC1500-Pico2W-Dongle.kicad_sch, bom.csv]
2026-09-24 RP2350 dongle: fix command-dispatch BUSY race, add STAGE/MLOG, SD bridge work
    Fix the stale-status race behind STAGE DEBUG's "first N bytes wrong" copies
    and intermittent SDLOAD/SDSAVE garbage. The ROM writes a command to 0x87FF
    and reads the status back on the very next instruction, treating anything
    but BUSY as done. BUSY used to be written by core0's monitor loop after it
    polled the dispatch FIFO, with no bound on that latency (CYW43 LED SPI
    calls on every command start/finish, USB stdio IRQs, flash_safe_execute
    pauses), so the LH5801 often read the previous command's SUCCESS and ran
    ahead of the MCU. Two DMA channels now drain the dispatch SM's FIFO: one
    queues the command byte in a ring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
    [PC_EXP.h, board_pins.h, diskio_sd_bridge.c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]
2026-09-24 RP2350: STAGE at boot, DORMANT sleep in STAGE RAM mode, MLOGMSG, memory map
    Boot-time STAGE: the base ROM's module-scan hook (0x880A) now runs STAGE's
    checksummed ROM-to-SRAM copy in a boot mode (no display, key wait, BASIC
    error or SIE; U/Y preserved for the scan loop), and skips it when a
    verified copy is already staged. ROM_GET_MODE gained a second byte, set
    only after a successful FINISH, so Remap alone (e.g. after a failed STAGE
    DEBUG) isn't mistaken for a good copy. STAGE RAM gets the same early exit.
    The STAGE_STAGE0_*/STAGE_PRIME_* diagnostics are removed.
    STAGE RAM sleep: while the ROM is served from SRAM, the RP2350 goes
    DORMANT between keywords. Every keyword now starts with EC_W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
    [PC_EXP.h, main.c, monitor.c]
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2026-09-25 Move keyword parsing to the MCU; keywords run in programs; add MCONF
    The expansion ROM no longer parses keyword arguments. Every keyword but
    ECVER points at KW_START, which hands the statement at BASIC's text
    pointer (Y) to the MCU (EXP_COMMAND_KEYWORD). RP2350/keywords.c parses
    it, runs the SD/log/STAGE commands itself, and returns actions for the
    ROM to carry out: DONE, SHOW, ERROR, BROWSE, LOAD, SAVE, VAR_LOOKUP,
    VAR_STORE, STAGE, and EVAL (BASIC's own evaluator, VEJ DE). The ROM
    region shrinks from ~5.0K to 1365 bytes.
    - Keywords now work inside running programs, not only at the prompt:
    every exit ends with VEJ E2 instead of jumping to the idle loop.
    - File names and numbers can be BA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
    [PC_EXP.h, diskio_sd_bridge.c, main.c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]
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2026-09-27 BLE step 0: BTstack scan spike on the dongle, Flutter Link-service app
    Firmware (RP2350):
    - Link pico_btstack_ble/pico_btstack_cyw43 (WiFi+BT CYW43 image) with our
    btstack_config.h.
    - BTstack's flash store gets its own 2 sectors below STSAVE: the SDK default
    overlapped MCONF and STSAVE, and BTstack erases it on its own. The log
    ring moves down 2 sectors.
    - ble_spike.c/.h: temporary. MCONF BLE=1 keeps the radio up, blocks DORMANT
    and runs a passive scan; core1 logs "BLE nd nA" after commands. To be
    replaced by ble_link and the BL keywords; config id 5 then stays unused.
    - MCONF's settings table carries explicit MCU_CONFIG ids.
    - Includes the 2026-09-25 lazy CYW43 bring-up (RadioUp()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
    [flash_layout.h, mcu_config.h, monitor.c]
2026-09-27 BLE: PC-1500 Link protocol, BL keywords, ROM entries
    - RP2350/BLE_PROTOCOL.md: the Link GATT service and framed protocol
    shared by firmware, app and emulator (HELLO/TEXT/FILE_*/ACK/ERR, one
    frame in flight per direction).
    - ROM: 'B' keyword group BLSCAN/BLCONNECT/BLDISC/BLPRINT/BLLIST/BLSAVE/
    BLLOAD (E1A0-E1A6). LOAD/SAVE now raise ERROR 40 when CLOSE reports the
    transfer failed (a BLE link can drop part-way; SD CLOSE succeeds).
    - keywords.c: the BL keywords. BLSAVE/BLLOAD reuse SDSAVE/SDLOAD with the
    peer in place of the card; BLPRINT formats numbers exactly as STR$
    (rules taken from and tested against the ROM in pc1500emu); BLLIST
    lays lines out as pc1500emu's detokenizer doe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
2026-09-28 BLE link on the Pico 2 W: PC-1500 <-> laptop app works end to end
    - ble_link.c/.h replace the bring-up spike: BTstack central on core0
    (CYW43 async context), commands on core1 via execute_sync, two one-frame
    receive slots; active scan for the Link service, connect, discovery,
    notifications, HELLO; TEXT and BLSAVE/BLLOAD streaming (READ/WRITE/
    CLOSE_SD_FILE go to the peer while a transfer is open). The radio is up,
    and DORMANT blocked, only while a command or connection needs it.
    - A minimal GATT server of our own (GAP + GATT services): without one,
    Windows held every notification to the PC-1500 (Unreachable, 0 bytes).
    - MCONF BLE (the spike's switch) removed; c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
    [flash_layout.h, mcu_config.h, monitor.c]
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2026-09-28 SDSAVE with no name saves as the last program SDLOADed
    A bare SDSAVE now saves the BASIC program under the name the last BASIC
    SDLOAD loaded (typed or picked from the browser), asking before
    overwriting it as usual. The name is kept as a full path (the current
    directory at load time, if cwd + name fit a name slot), so a later SDCD
    doesn't move it. It lives in the MCU's RAM only: with nothing loaded since
    power-up, a bare SDSAVE is ERROR 1, as before. SDLOAD M doesn't count, and
    BLSAVE still needs a name.
    keywords.h gains kw_reset(), which forgets that state, for pc1500emu to
    call when a module is loaded (the firmware's RAM starts clean).
    Tested in pc1500emu, and on hardware.
    Co-Authored-B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
2026-09-30 BLE messaging; BLSTAT and SDEOF(n) as BASIC functions; STAGE RAM refreshes
    Peer messaging between two PC-1500s (BLE_PROTOCOL.md "Peer messaging",
    MSG 0x30):
    - BLSEND value[,value...] sends numbers and strings as one message of
    SDPRINT-style chunks; if the peer's 8-message inbox is full it waits and
    retries (BREAK stops).
    - BLRECV [#t,]var[,var...] takes the oldest message into variables (extra
    ones 0 / blank, a type mismatch ERROR 42). It waits until one arrives,
    or up to t seconds (#0: not at all), leaving the variables unchanged if
    none does.
    - The inbox lives on core0, which ACKs each MSG as it's stored; core0 and
    core1 each own one counter, so neither read-modify-writes the o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
    [monitor.c]
2026-10-01 CE-150 printer/plotter stand-in over BLE; ECVER 0.4
    When no CE-150 is attached, the module answers the CE-150's 15 BASIC
    keywords and draws the output on the connected BLE peer instead of paper:
    COLOR, CSIZE, GRAPH, GLCURSOR, LCURSOR, LF, LINE, LLIST, LPRINT, RLINE,
    ROTATE, SORGN, TAB, TEST, TEXT.
    Codes and tables:
    - The eight F0xx keywords keep the CE-150's own codes (BASIC looks for
    F0xx on every page). The seven E6xx ones can't (BASIC only looks for
    those on the CE-150's page), so they're E1C0-E1C6 here.
    - New C/G/L/R/T index slots; SORGN joins the S chain.
    - Every letter's first table entry now has marker bit 4 set, as the
    CE-150's table does. Without it a mismatched word's skip-s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
    [monitor.c]
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2026-10-05 External Bluetooth keyboard (MCONF BLKBD); Link pairing; ECVER 0.5
    External keyboard, classic Bluetooth for now (works on hardware with an
    Omoton KB066):
    - MCONF BLKBD=1: at power-on/reset the boot hook copies ROM1's keyboard
    wait loop (E24A-E365) to the MCU, which checks its CRC and patches it
    into the module ROM at KBD_LOOP (kbd_seq.c kbd_loop_install), then arms
    the base ROM's keyboard hook (785BH/785CH = KBD_HOOK 880EH, 79D4H = 55H).
    No Sharp code ships in the module ROM.
    - The keyboard's key is a virtual matrix key the MCU publishes at 87EFH;
    ROM1's own loop handles SHIFT/DEF/SML, debounce and repeat. ON = BREAK
    (count at 87F5H, ack at 87FAH); OFF goes to the loop's own powe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
    [flash_layout.h]
2026-10-05 External keyboard: turning it off, stuck keys, re-pairing
    - MCONF BLKBD=0 unhooks the ROM's keyboard driver at once (79D4H = 0),
    so the PC-1500 is back on ROM1's own loop: the driver went on reading
    a key byte nothing kept up any more, and every character typed was
    wiped again. The MCU also drops queued and held keys and clears 87EFH.
    - A keyboard switched off (or out of range) with a key down: its
    connection closing releases every key.
    - BLKBD after a bond: an older connection to the keyboard (the
    reconnection made at start-up, dropped by the new pairing) failing no
    longer fails the pairing -- HID events are matched to their connection,
    and the pairing connects again once the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
2026-10-06 External keyboard: refuse the older PC-1500 ROM; CONNECTING timeout
    - An older PC-1500 ROM (a real machine's dump; CRC-32 A4713655H over
    C000H-FFFFH) has VEJ F4H,79H,D5H at E2B7H, which loads the hook vector
    at 79D5H into U, and the STX P after it jumps to whatever X held: its
    79D4H keyboard hook can't be used (BASWORD's PEEK &E2B9 = 56 test
    rejects it too). kbd_loop_install() now returns why it refused --
    E2B9H isn't 38H, an unknown loop (its CRC goes in the log), or a module
    ROM layout that doesn't fit -- and the MCU logs "KBD: ROM hook unusable"
    or "KBD: ROM CRC xxxxxxxx" instead of "KBD loop: not ROM1's". The boot
    hook already left the hook unarmed without the loop.
    - BLK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
    [monitor.c]
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2026-10-06 MCONF POWMANDELAY: POWMAN power-down in STAGE RAM sleep; wake on writes only
    - MCONF POWMANDELAY (setting 8; -1, or 0-65534 s; default -1): in STAGE
    RAM mode, a POWMAN power-down on top of DORMANT. -1 DORMANT only, as
    before; 0 POWMAN straight after SLEEPWAIT; n DORMANT, then POWMAN if n
    seconds pass with no wake (AON-timer alarm, LPOSC). MCONF shows and
    takes -1.
    - Before powering down, core1 closes SD files and SDOPEN channels and
    keeps the current directory (up to 20 characters, else its deepest
    parent that fits) in POWMAN scratch 0-5; then parks in WFI (the
    power-down needs both cores in WFI, datasheet sec.6.2.3). A wake is a
    reboot: main() notes it (chip_reset HAD_SWCORE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
    [main.c, mcu_config.h, monitor.c]
2026-10-06 Wi-Fi keywords (WFSCAN/WFCON/WFDISC/WFFORGET/WFSTAT); core1 command mailbox; BLKBD fixes
    Wi-Fi station mode on the CYW43 (wifi_link.c, wifi_store.c):
    - WFSCAN lists networks (strongest first, signal + security, * = remembered);
    C connects. WFCON ["ssid"[,pw$]] joins by name, or the strongest
    remembered network. A secured network with no password asks for one,
    masked, on the PC-1500 (SML for lowercase, left arrow deletes).
    - WFDISC leaves; WFFORGET ["ssid"] forgets one or all; WFSTAT is a
    function (0 off, 1 connecting, 2 connected).
    - Up to 4 networks remembered in their own flash sector (slot 4; the log
    ring moves down one sector). While joined, STAGE RAM sleep is held off,
    as fo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
    [flash_layout.h]
2026-10-07 Dispatch the pairing commands (BLPAIR/BLUNPAIR/BLADV pairing)
    BLE_PAIR_BEGIN/CONFIRM/ANSWER and BLE_UNPAIR never reached
    ble_link_command(): monitor.c had no case for them, so they fell to
    NOT_IMPLEMENTED and BLPAIR gave ERROR 40 with nothing logged. The
    emulator's own dispatch hid it. Confirmed on hardware.
    [monitor.c]
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2026-10-07 Fix SSH/WFPING codes colliding with COLOR/LF/LINE; BLLIST/LLIST honor BREAK; app plotter on the left
    - SSH, SSHKEY, SSHFORGET, WFPING move from E1B4-E1B7 to E1D0-E1D3. A
    keyword's id in keywords.c is only its token's low byte, so E1B5-E1B7
    were the CE-150 stand-in's COLOR (F0B5), LF (F0B6) and LINE (F0B7):
    since 621878e those ran SSHKEY/SSHFORGET/WFPING (ERROR 1 in programs).
    - BLLIST checks for BREAK after each TEXT frame it sends, LLIST after
    each line it draws (a one-wake POLL); BREAK ends the listing with what's
    out so far sent whole, back to BASIC.
    - ble_app: the plotter is a full-height column on the left; the console,
    files folder and log stack to its right.
    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
2026-10-08 MCONF BRIDGEINT: the SD bridge's INT pin optional (GP28 freed when off)
    Waiting on U5's INT made little difference to SD throughput, so it's a
    setting now, for anyone wanting GP28 for something else:
    - BRIDGEINT=1 (default): as before -- wait on INT after each SPI
    transmission, drain-read write-only chunks, Clear Interrupt.
    - BRIDGEINT=0: GP28 never touched; the busy-NAK retries alone.
    Read at boot (from the next power-on/reset), so the pin is never
    reconfigured under a transfer on core1: main.c hands it to the driver's
    new sc18is602b_set_int_enabled() before any SD access. sd_bridge_test
    (no mcu_config) keeps the default.
    Also drops main.c's temporary 2026-09-28 boot-timing scope marker,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
    [main.c, mcu_config.h]
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2026-10-09 RP2350B: snapshot of September work before retiring this tree
    Commits the uncommitted work as it stands: GreenPAK NVM provisioning
    (greenpak_nvm, gp1/gp2 images, main_provision), the bit-banged GreenPAK I2C on
    GPIO28/29, the data-bus remap and the hw_config SPI pin notes. RP2350B is being
    replaced by a card build variant of RP2350/, so this is kept for reference only.
    [board_pins.h, greenpak_i2c.c, greenpak_virtual_io.c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]
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2026-10-12 Internal card: SD over SPI works; SDLS free space; module wake pin
    Tested on the first prototype card (hand-wired microSD socket): SDLS,
    SDLOAD and SDDF work; SDDF takes under a second (20+ s through the
    dongle's bridge).
    - SD: keep CS low for a whole block read or write (sd_bus_hold(), SPI
    only). The bridge-era code polled for a slow card's data token one
    CS-toggled byte at a time; the prototype's SDSC card never sent the
    token and then answered nothing ("SD CARD ERROR 1").
    - SD: after init, check the data clock (CSD as at 400 kHz, sector 0
    read twice alike) and step down 25 -> 12.5 -> 6.25 -> 3 -> 1 MHz if the
    card misreads; a failed block read is now in the MCU log. The prototy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
2026-10-12 GreenPAK provisioner: card target; GP1 image from the corrected .gp6
    - GREENPAK_TARGET=card builds for the internal card's GreenPAK bus,
    GPIO28/29 (dongle: GPIO26/27, the default).
    - gp1_nvm_image.h regenerated from GP1-SRAM.gp6 as corrected 2026-10-12:
    byte-identical to the 16 Sep 16:35 image every working board runs.
    The 16 Sep 19:27 save (the image committed in 2e79417) had DME0
    active-low in 3-bit LUT2/LUT6/LUT11/LUT13 and IO11 pulled up; written
    to a working dongle it broke SRAM decoding. ME0/DME0 are active-high.
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

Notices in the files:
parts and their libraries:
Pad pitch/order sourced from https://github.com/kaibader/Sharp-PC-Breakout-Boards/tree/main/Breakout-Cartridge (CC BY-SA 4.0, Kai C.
